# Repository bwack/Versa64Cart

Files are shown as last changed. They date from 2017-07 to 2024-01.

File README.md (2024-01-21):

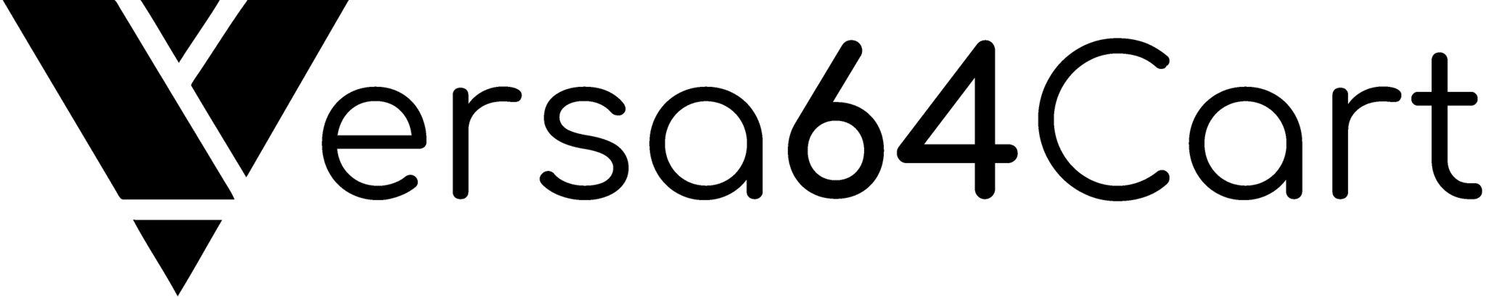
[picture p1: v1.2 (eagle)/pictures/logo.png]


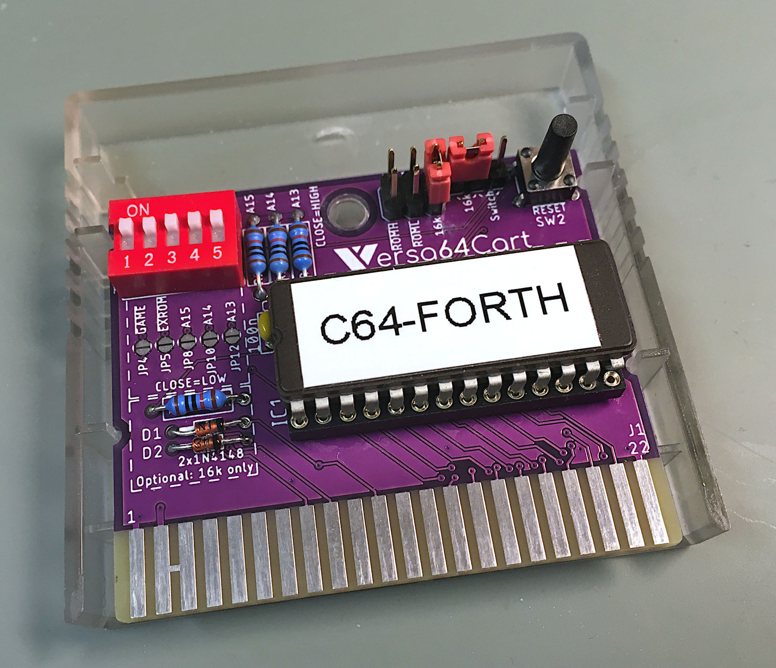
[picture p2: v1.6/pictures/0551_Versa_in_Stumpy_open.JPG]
boardimage


Versa64Cart is designed to be a modern easy-to-use cartridge development board for Commodore 64 and Commodore 128 hobbyists and hackers. The versatile design of the PCB allows for flexible implementation of various cartridge types. Whether it’s a simple cartridge backup of an 8k game or a switchable multi-program diagnostic cartridge, Versa64Cart has you covered.

Supported EPROMS are: 27C64 (8k), 27C128 (16k), 27C256 (32k), 27C512 (64k).
Please see the documentation for more information.

I have put the rev 1.1 in a separate folder in case someone wants to use the kicad files as a template.
Rev. 1.2 and onwards is designed by [Sven Petersen](https://github.com/svenpetersen1965 "Sven's github repository!") in eagle. It is a complete redrawn schematic and layout.

Sven has designed another cartridge called [Diag64cart](https://github.com/svenpetersen1965/Diag64cart) derived from this project.

# Quick Guide

## Obtaining binaries

Use the cartconv.exe tool from the VICE emulator to get information and to extract the binary from .CRT files. Copy it to the same folder as your .CRT files.

List the .CRT information:

```
C:\cartconv>cartconv -f deadtest.CRT
CRT Version: 1.0
Name: C64DEADTESTREV718220
Hardware ID: 0 (Generic Cartridge)
Mode: exrom: 1 game: 0 (ultimax)

offset  sig  type  bank start size  chunklen
$000040 CHIP ROM   #000 $e000 $2000 $2010

total banks: 1 size: $002000
```
The hardware ID must be 0. The size of the eprom shown here is 8k ($2000).

Convert the binary:

`cartconv -i mycartridge.crt -o mycartridge.bin`

## Combining binaries

The Versa64Cart supports EPROMS from 8k to 8x8k or 4x16k. The easiest way to combine is to use the copy command (in Windows):

`copy /b DeadTest.bin + jupiterl.bin + SomeGame.bin combined.bin`

Special care must be taken if mix 8k and 16k images. The 8k binaries must be allocated in pairs:

`copy /b first8k.bin + second8k.bin + some16k.bin combined.bin`

## Documentation

For more information Please see the [pdf file](v1.6/pdf/Versa64cart_v1_6.pdf) in this repository.

## Pictures

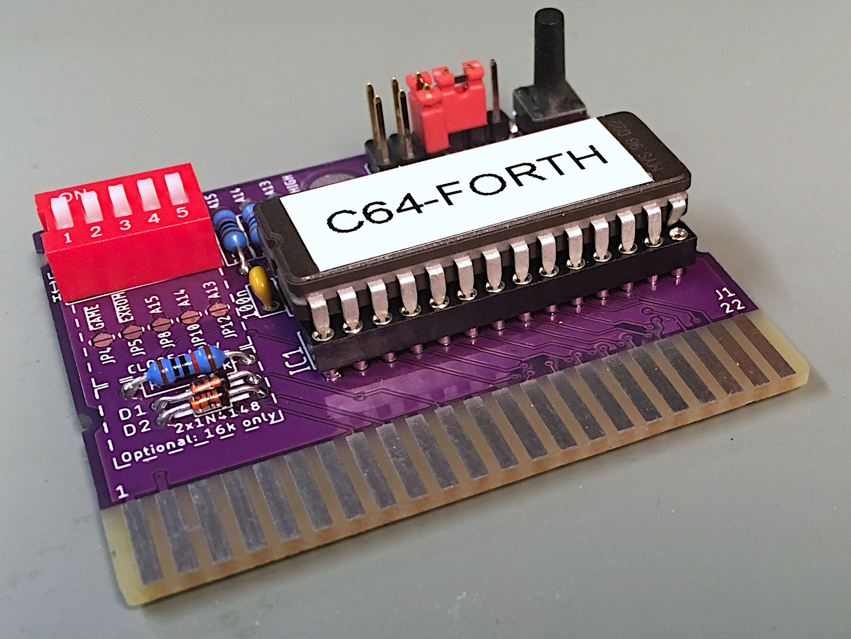
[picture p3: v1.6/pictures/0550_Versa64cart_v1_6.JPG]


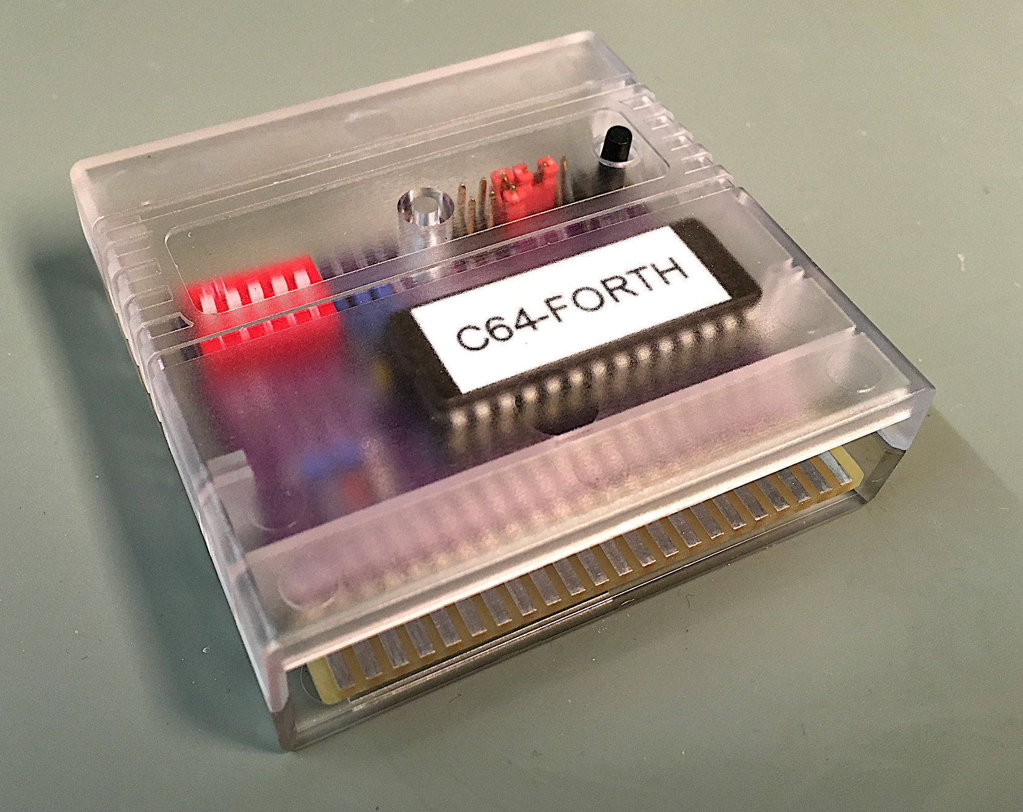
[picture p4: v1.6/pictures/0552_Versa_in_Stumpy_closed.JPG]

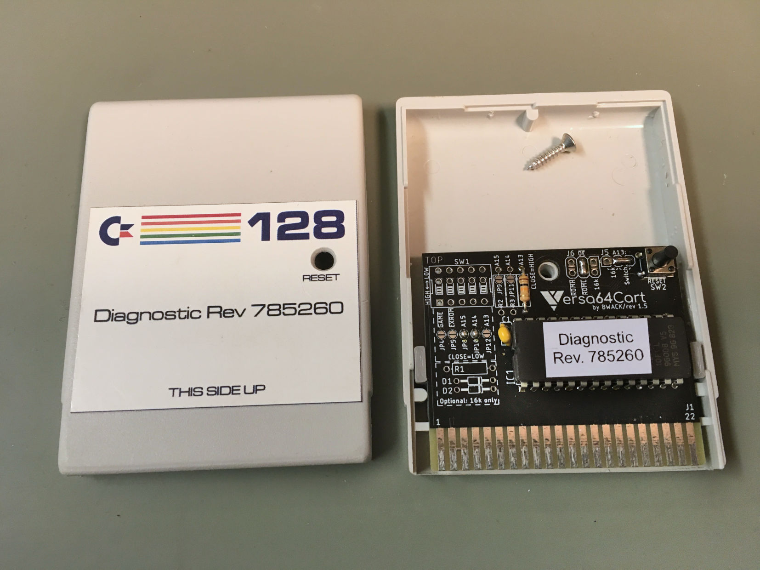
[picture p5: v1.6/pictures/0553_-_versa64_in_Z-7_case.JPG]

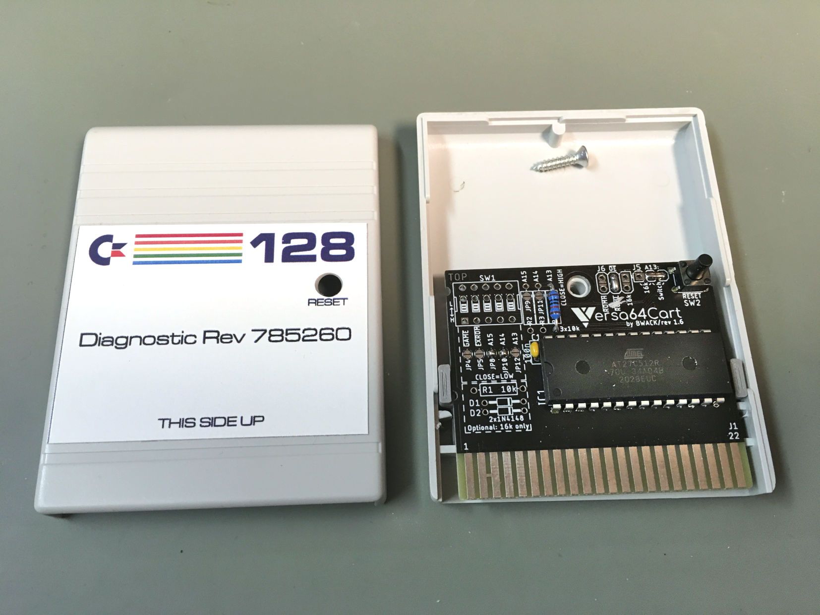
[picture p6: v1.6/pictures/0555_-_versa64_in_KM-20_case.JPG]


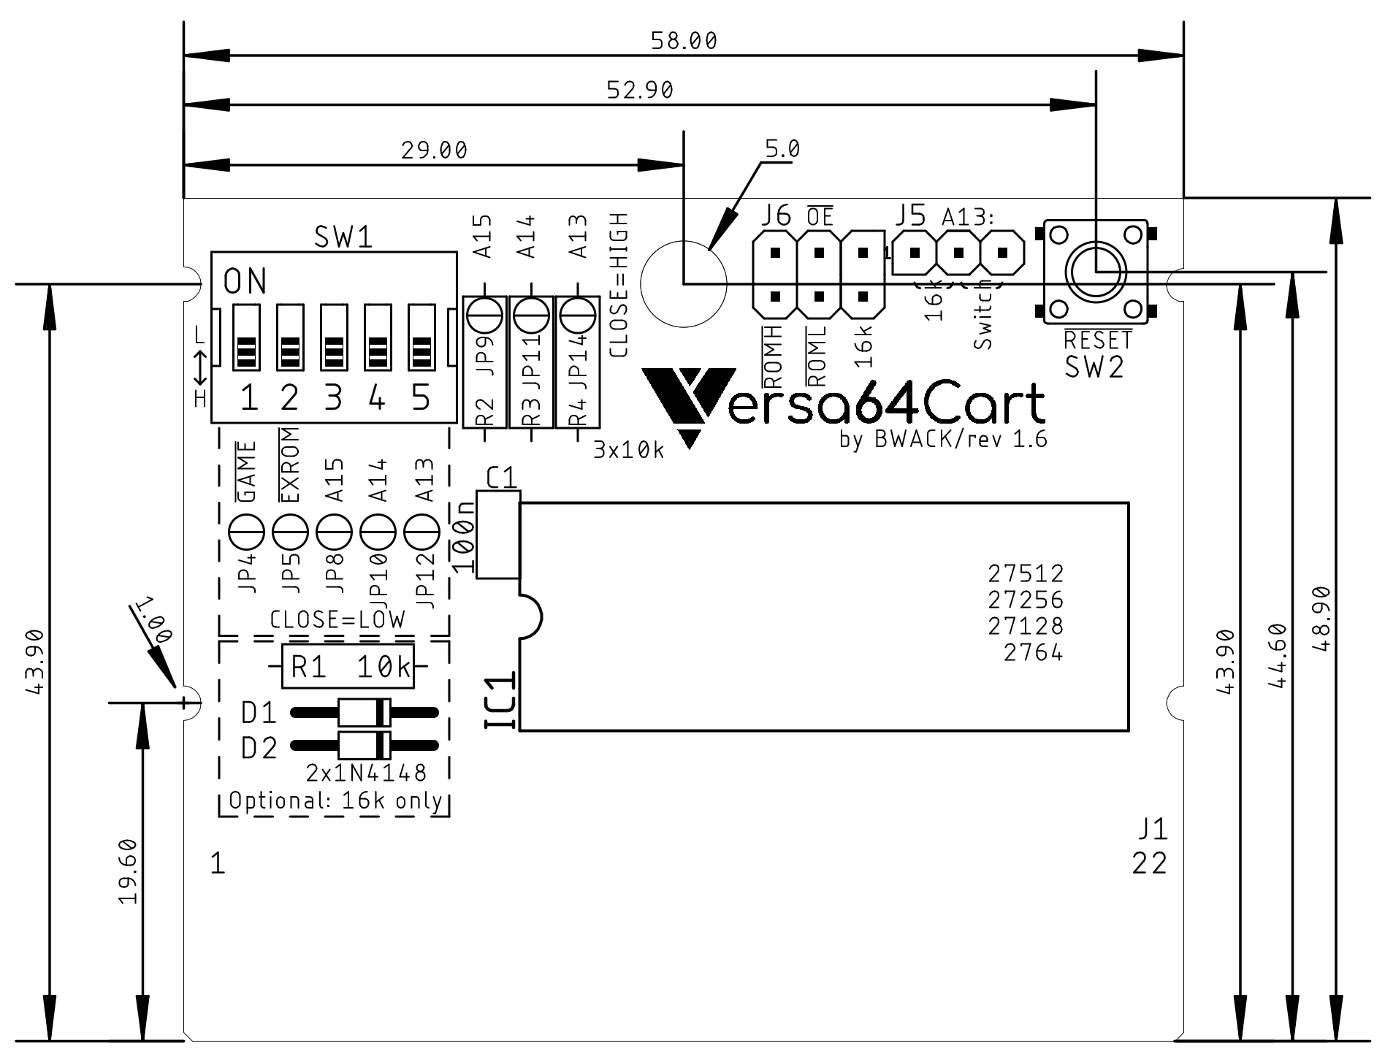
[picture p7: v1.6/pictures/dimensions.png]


# Changes
## 1.6
- Change: Notches added to fit the thefuturewas8bit.com stumpy cartridge case (not the button hole!)
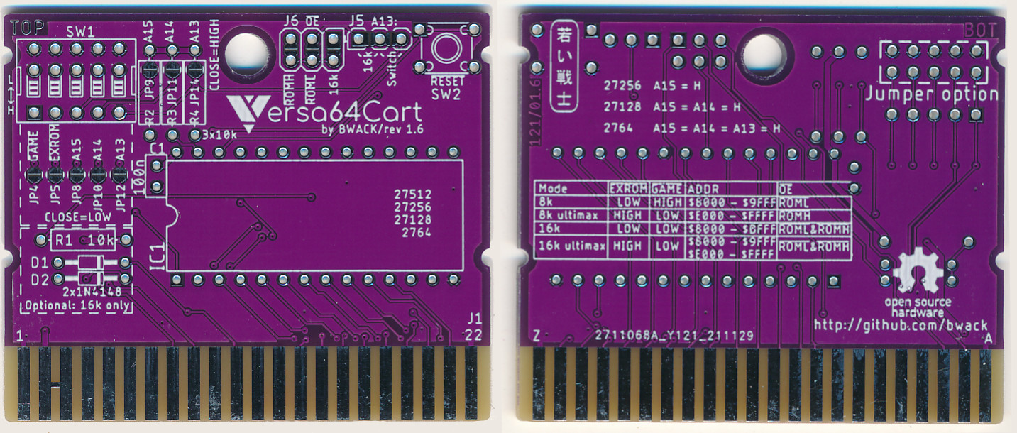
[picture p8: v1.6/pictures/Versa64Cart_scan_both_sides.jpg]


## 1.5
- Change: Combined footprint SW1, 5Way-DIP and 2x5 2.54mm pin header

## 1.4
- Change: card edge connector with pads like in v1.1

## 1.3
- Change: Cartridge enclosure support
  - Moved IC socket away from edge
  - Moved diode group away from edge
  - Bom: Use right angle pin headers. The straight ones are too tall.
  
## 1.2
- A reset button
- Jumpers accessible on outer edge.*
- Solder jumpers at the top layer
- New documentation
- Designed in Eagle
* Remember to turn off the computer before changing the jumpers.

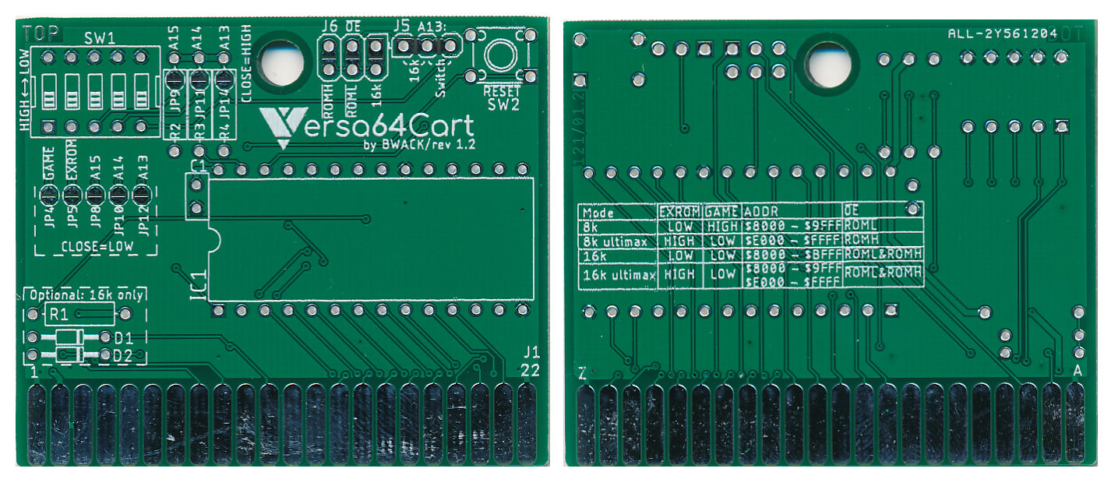
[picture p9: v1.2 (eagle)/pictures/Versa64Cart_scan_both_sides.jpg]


## 1.1 and 1.0

- Designed in KiCad based on simple64cart eagle files
- Support retro innovation cartridge enclosure (allthough pins too high)
- Moved IC sockets further from edge
- Added 16k game support
- Added dip switch and jumpers
- Added Documentation

# External websites

[Blog post, "Versa64Cart and C64 ROMs", by Gregory Nacu at c64os.com ](https://c64os.com/post/versa64cart)

# Versa64Cart on YouTube

https://www.youtube.com/results?search_query=Versa64Cart

# VersaZIF64
Check out VersaZIF64 if you are interested in the Versa64cart and with a ZIF socket.
https://github.com/bwack/VersaZIF64

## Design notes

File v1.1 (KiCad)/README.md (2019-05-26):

For gerbers click the relases tab!

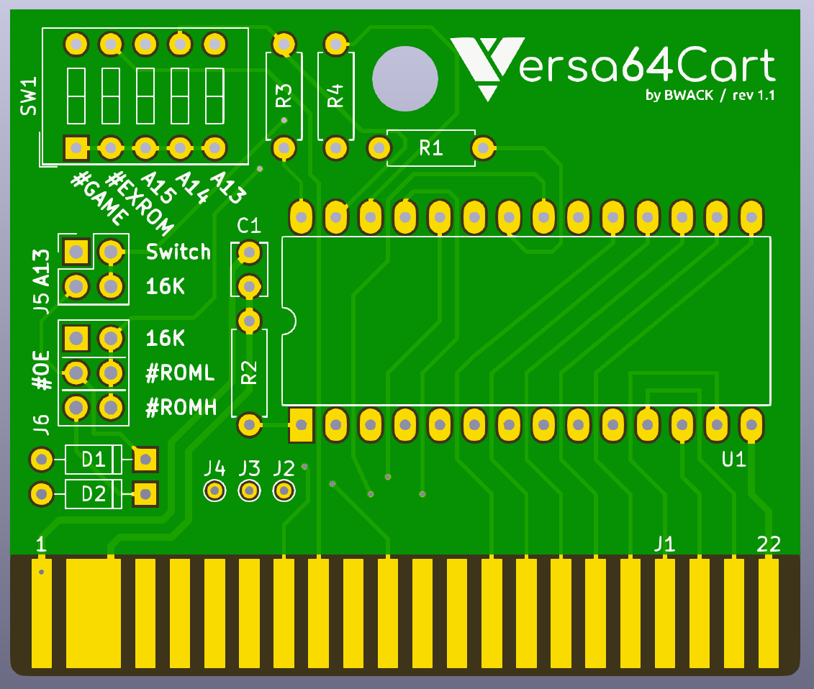
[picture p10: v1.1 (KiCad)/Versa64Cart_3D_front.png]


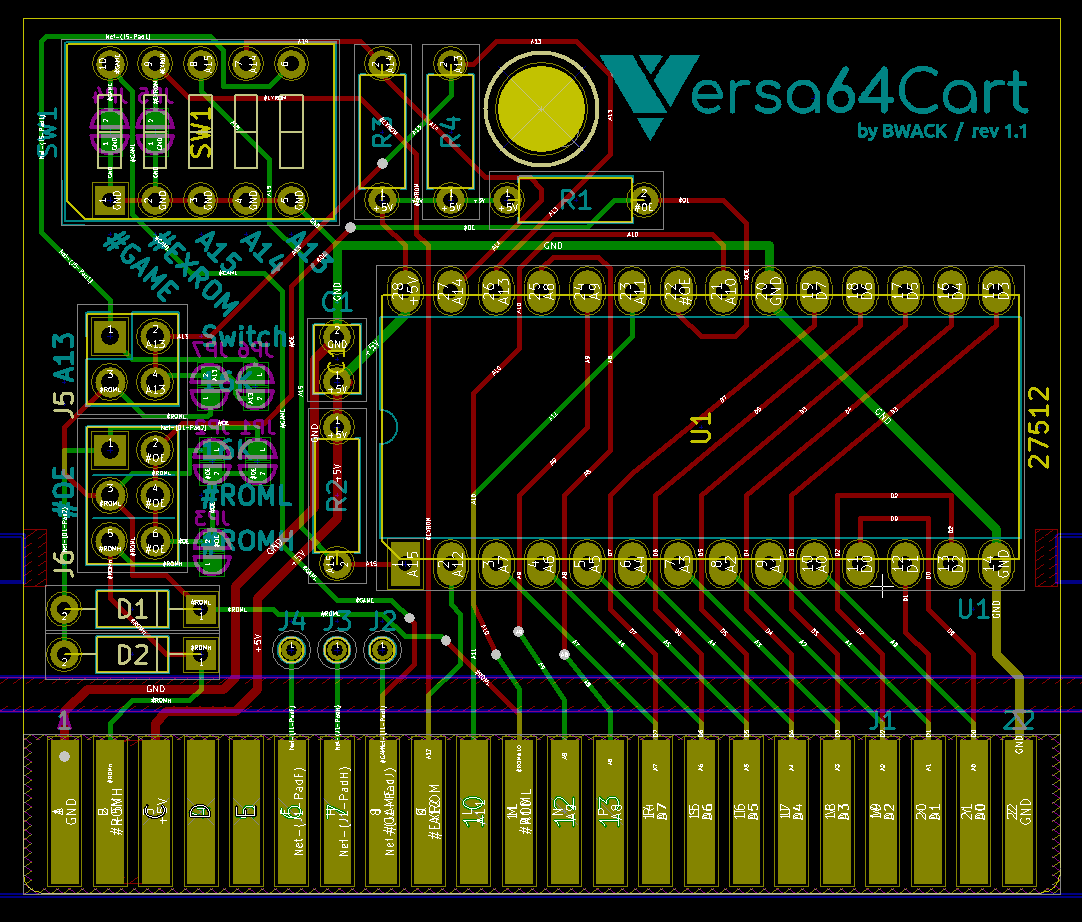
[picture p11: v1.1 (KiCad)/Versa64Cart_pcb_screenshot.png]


For more info see the docs

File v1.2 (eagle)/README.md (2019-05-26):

board

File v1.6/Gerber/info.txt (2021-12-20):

      
       Board: Versa64Cart
       Rev.:  1.6
  
       Files:
       ======
  
       All Gerber files are generated in extended gerber format (RS274X)
       *.TOP        : Film top copper
       *.BOT        :  -"- bottom copper
       *.STC        :  -"- top soldermask 
       *.STS        :  -"- bottom soldermask
       *.PLC        :  -"- silk screen top
       *.PLS        :  -"- silk screen bottom
       *.DK         : Drills plated Through (Excellon)
       *.NDK        : Drills not plated Through (Excellon)
       *.OUT        : Board outline

       Board Size:
       ===========
       Length     :   58.0 mm
       Width      :   48.9 mm
       Thickness  :   1.6 mm
       Material   :   FR 4
       Copper     :   35 um
       Surface    :   HASL
       
       Remarks:
       ========
       minimum drill: 0.35mm
       minimum width: 8 mil
       minimum distance: 6 mil

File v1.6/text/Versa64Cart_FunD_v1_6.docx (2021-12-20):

Versa64Cart v1.6

Functional Description

J1 are the contacts, that fit into the Commodore C64 expansion port. The pin numbering is identical to those of the C64. IC1 is the EPROM, which can be socketed or not. C1 is the blocking capacitor, that should help to keep the noise from the supply voltage out of the IC.

The configuration is achieved with the DIP-Switch SW1, jumper J5 and jumper J6. SW1-1 and SW1-2 set the signals and . These signalize the C64 the mode of the cartridge. The switches SW1-3 to SW3-5 are responsible for the (manual) bank select: The configure the three most sufficient address bit of the EPROM, since those are not asserted by the C64, which only addresses 8kB blocks. The Dip Switch can be replaced with a jumper (2x5).

For 16kB cartridges, a further address bit (A13) is required. Since this kind of cartridge uses both chip selects ( and ) the signal is used for this purpose. It will be low, while the lower 8kB are addressed and HIGH, while the upper 8kB are addressed.

The 16k cartridge configuration requires to combine and to one chip select signal. This function is provided by the wired AND circuit D1, D2 and R1. R1 is pulling the RH&RL signal HIGH. In case one of those signals is low, the RH&RL is driven LOW.

The required chip select signal can be selected with J6.

In 8k mode, the address bit A13 is set by the DIP-switch. Jumper J5 has to be set to the “Switch” position.

While and utilize the pull-up resistors inside the C64, the address signals A13 to A15 require Pull-Up resistors on the cartridge board (R2-R4). There are solder bridges on the component side if the Versa64Cart, that can be used alternatively to the DIP-Switch to pull each signal low. In case the Pull-Up resistors R2-R4 are not populated, additional solder bridges can be used to set A13 – A15 to a HIGH level (only those, that are set to a HIGH level). It is obvious, that closing the HIGH bridge and the LOW bridge of a signal at the same time produces a short circuit.

SW2 is the reset switch. A pull-up resistor on the C64 mainboard is utilized here.

Versa64Cart_FunD_v1_6.docx 19.12.2021 16:27 Drafted by Sven Petersen Page 2 of 2 Doc.-No.: 000-6-00-00

Versa64Cart_FunD_v1_6.docx 19.12.2021 16:27 Drafted by Sven Petersen Page 1 of 1 Doc.-No.: 121-6-02-01.6

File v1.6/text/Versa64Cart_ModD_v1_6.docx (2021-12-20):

Versa64Cart v1.6

Module Description

# 1. Introduction

The Versa64Cart is a generic EPROM cartridge for the Commodore C64 and C128. It can be configured as 8k, 16k, 8k ultimax or 16k ultimax cartridge. Further on, the most sufficient address bits of the EPROM can be set by a DIP-switch which offers a manual bank switching for multi game/multi ROM cart option.

The Versa64Cart is not suitable to run a Kernal or software, which require bank switching by that software (e.g. games > 16k).

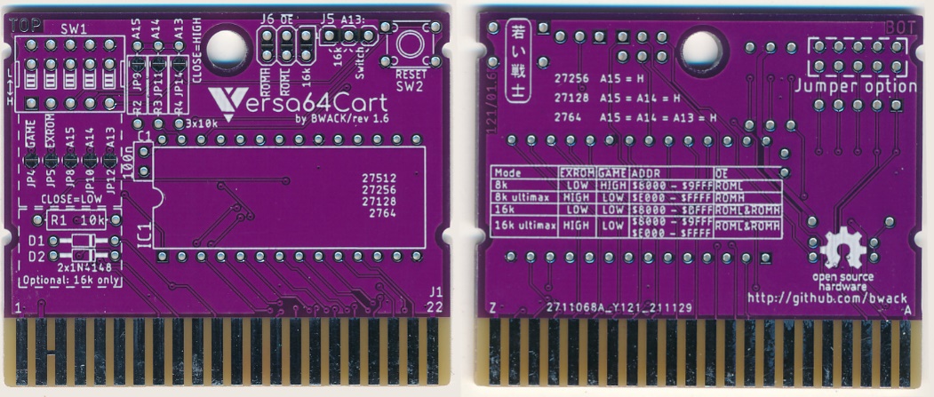
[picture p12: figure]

Figure 1: Both sides of the Versa64cart Rev. 1.6

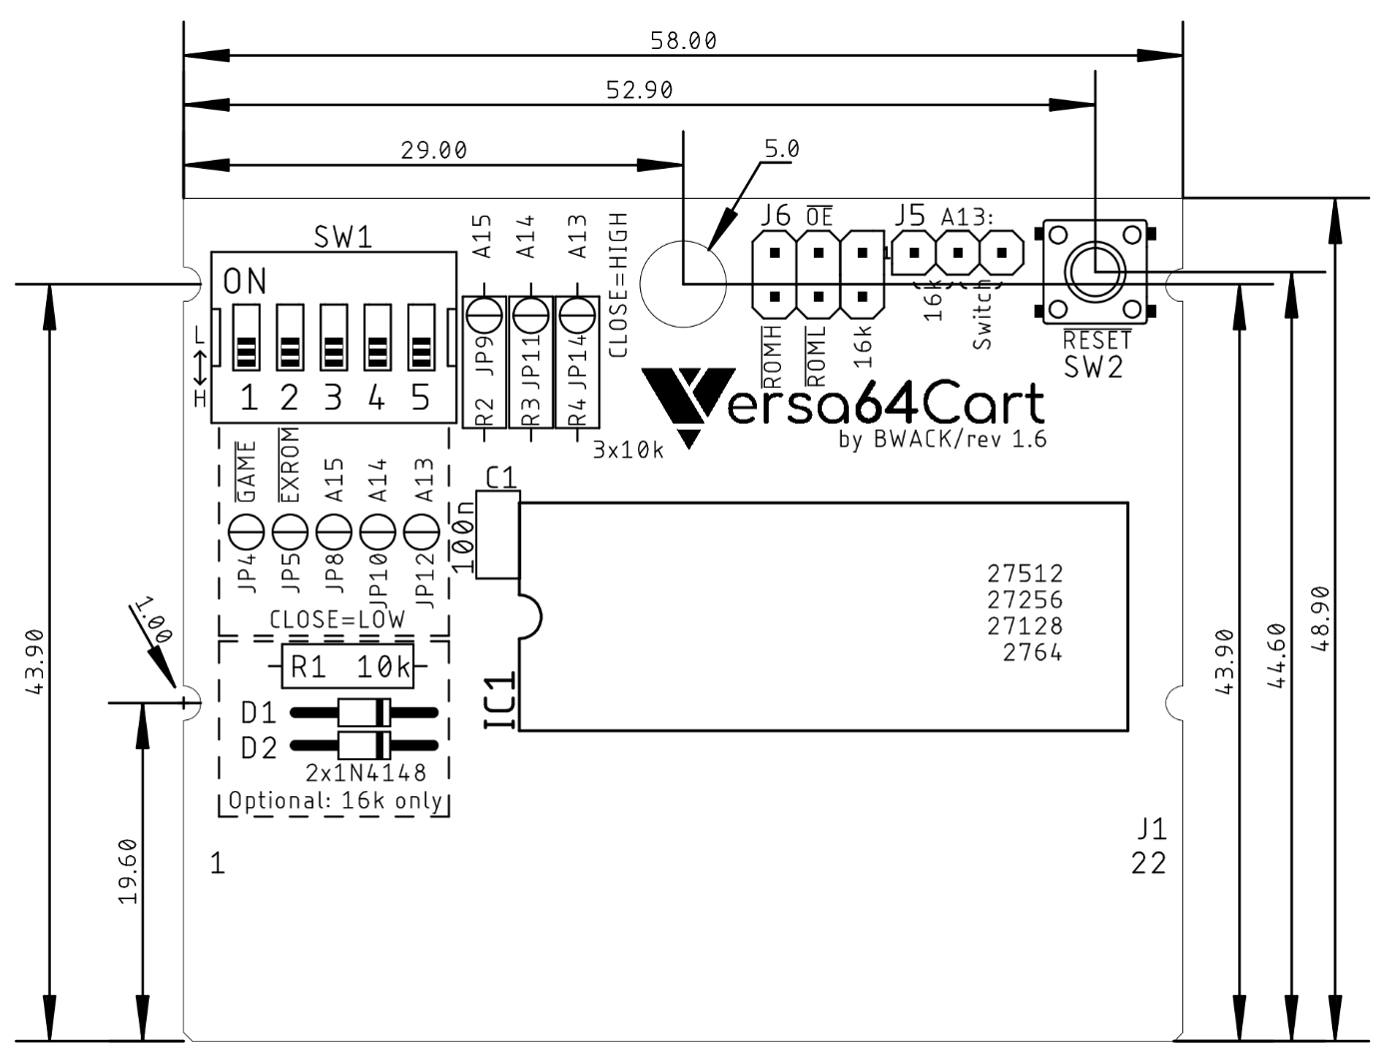
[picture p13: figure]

Figure 2: Versa64Cart - placement and dimensions

# 2. Configuration

## 2.1. Explanation

The extension cartridges signalize their configuration with two flags. Those are and . For addressing the EPROM, the C64 offers two chip-select signals for an 8kB address space, which are and . The chip-select signals are required to locate the EPROM content within the address space of the C64. It is possible to use either , or combining both to get a 16kB address space in total.

Mode | | | | Address space
8k | LOW | HIGH | | 0x8000 – 0x9FFF
8k ultimax | HIGH | LOW | | 0xE000 – 0xFFFF
16k | LOW | LOW | & = “16k” | 0x8000 – 0xBFFF
16k ultimax | HIGH | LOW | & = “16k” | 0x8000 – 0x9FFF + 0xE000 – 0xFFFF

Table 1: Cartridge configuration

In the “ultimax” modes, the Kernal ROM (0xE000 – 0xFFFF) is replaced by the content of the EPROM of the Versa64Cart. The Reset vector is located at 0xFFFC and 0xFFFD. This is a guidepost for the microprocessor, which shows where to start the execution after the processor was powered up (or received a RESET pulse). This way, the software in the EPROM will completely take control.

In EXROM mode, the C64 Kernal (the one on the mainboard) will check the memory locations 0x8004-0x8008 for the “cartridge signature” CBM80 (PETSCII 0xC3, 0xC2, 0xCD, 0x38, 0x30). If this sequence is found, the execution will follow the cartridge cold start vector located at the first two memory addresses of the EPROM (0x8000 and 0x8001 in the C64’s address space).

## 2.2. Jumper & DIP-Switch Settings

The DIP-Switch SW1 configures the cartridge mode and the three most sufficient address bit of the EPROM (the “bank switching”). Annotation: ON position connects the signal to ground (=LOW).

The jumper J6 () sets the chip select signal for the EPROM. It can be , or “16k”(this is a diode logic AND of and ).

The jumper J5 (A13) can be set to “Switch” or “16k”. “Switch” means, that A13 is set by the DIP-Switch, “16k” means, that A13 is controlled by the signal.

A 16k cartridge requires both jumpers (J5 and J6) set to “16k”.

For the required settings refer to Table 1.

## 2.3. Bank Switching

The EPROM offers more memory (27C512 = 64kB), than it is required for a generic 8k or 16k cartridge. On account of this an EPROM can keep the content of several cartridges. The DIP-Switch SW1 (3, 4, 5 = A15, A14 and A13) selects, which of these cartridges is selected. In 16k mode, the setting of A13 is ignored.

The DIP-Switch can be replaced with a jumper.

DIP-Switch | | | Address Bits | | | EPROM Address (Offset)
3 | 4 | 5 | A15 | A14 | A13
ON | ON | ON | L | L | L | 0x0000 – 0x1FFF
ON | ON | OFF | L | L | H | 0x2000 – 0x3FFF
ON | OFF | ON | L | H | L | 0x4000 – 0x5FFF
ON | OFF | OFF | L | H | H | 0x6000 – 0x7FFF
OFF | ON | ON | H | L | L | 0x8000 – 0x9FFF
OFF | ON | OFF | H | L | H | 0xA000 – 0xBFFF
OFF | OFF | ON | H | H | L | 0xC000 – 0xDFFF
OFF | OFF | OFF | H | H | H | 0xE000 – 0xFFFF

Table 2: 8k cartridges memory banks

DIP-Switch | | | Address Bits | | | EPROM Address (Offset)
3 | 4 | 5 | A15 | A14 | A13
ON | ON | X | L | L | X | 0x0000 – 0x3FFF
ON | OFF | X | L | H | X | 0x4000 – 0x7FFF
OFF | ON | X | H | L | X | 0x8000 – 0xBFFF
OFF | OFF | X | H | H | X | 0xC000 – 0xFFFF

Table 3: 16k cartridges memory banks

The C64 address must not be confused with the EPROM Address offset.

## 2.4. Solder Bridges

Instead of setting jumpers and the DIP-Switch, solder bridges can be utilized to configure the Versa64Cart. This is an option, in case the configuration of the Versa64Cart is not prone to be changed. Solder bridges are used to “hard wire” the configuration.

Signal | HIGH | LOW
| JP4 = open | JP4 = closed
| JP5 = open | JP5 = closed
A15 | JP8 = open, (JP9 = closed) | JP8 = closed, (JP9 = open)
A14 | JP10 = open, (JP11 = closed) | JP10 = closed, (JP11 = open)
A13 | JP12 = open, (JP14 = closed) | JP12 = closed, (JP14 = open)

Table 4: Configuration with solder bridges

The jumpers in ( ) are only required, in case the pull-up resistors R2, R3 and R4 are not populated. Never (!!!!) close both jumpers of one address signal. It cannot be LOW and HIGH at the same time, this will produce a SHORT CIRCUIT!!!!

The footprints of the jumpers J5 and J6 are designed to be solder bridged, when not populated.

# 3. Assembly of the Versa64Cart

The Versa64Cart can work with a minimum of components when being configured with solder bridges. Just the EPROM and a 100nF capacitor is required.

- The reset switch is nice to have, but it is just an option.
- The DIP-switch can be replaced by configuring the solder bridges JP4, 5, 8, 10 and 12.
- The pull-up resistors (R2-4) can be omitted and JP9, 11, 14 can be utilized to set a HIGH level on A15 … A13 (BE CAREFUL, see warning above!). If you are not sure, keep the pull up resistors.
- J5 and J6 can be hard wired with solder bridges.
- R1, D1 and D2 are only required in 16k modes.
- The EPROM can be soldered, a socket is not necessary

Soldering the EPROM can be required if a shallow cartridge case is used. A socket might add too much height. In this case, it is advised to test the EPROM with a Versa64Cart with a socket before.

# 4. Retrieving the binary and the settings from a CRT file

## 4.1. VICE cartconv

The CRT file format is created to emulate cartridges with VICE or devices like the Ultimate II+ etc. It should not be programmed into an EPROM; this will not work.

Instead, the binary has to be retrieved from the CRT file. The binary is a file that can be used for programming EPROMs. Also, it is possible to find out the required settings for and .

The utility that is used here is CARTCONV, which is a command line too that comes with VICE (C64 emulator). For the examples, CARTCONV and the cartridge files are copied to the same directory. To start, enter cmd into the search box on the task bar of Windows 10.

First the CRT information is required. Enter the following command

cartconv -f mycartridge.crt

mycartridge.crt stands for the crt file, that you want to convert.

The second step is to generate a *.bin file from the *.crt. The *.bin file can be used to program EPROMs.

cartconv -i mycartridge.crt -o mycartridge.bin

## 4.2. Example I

C:\cartconv>cartconv -f deadtest.CRT

CRT Version: 1.0

Name: C64DEADTESTREV718220

Hardware ID: 0 (Generic Cartridge)

Mode: exrom: 1 game: 0 (ultimax)

offset sig type bank start size chunklen

$000040 CHIP ROM #000 $e000 $2000 $2010

total banks: 1 size: $002000

The important information is colored red in the above example.

First of all, it has to be a generic cartridge (Hardware ID 0). Many (game or special) cartridges have additional hardware build it, that is required for proper operation. That might be one of manifold automatic bank switching circuits, a freezer circuit like in the Final Cartridge etc.

Next, has to be 1 (HIGH) and has to be 0 (LOW) Þ DIP Switch 1=ON, 2=OFF. The ultimax mode is mentioned here, too. The start address is $e000 (0xE000). Referring to Table 1, J6 has to be set to . The size is $2000 (which is hexadecimal for 8k). Hence jumper J5 is set to “switch”. It is assumed, that the binary is programmed to the first 8k of the EPROM, so the address lines A15, A14 and A13 are L, L, L Þ the switches 3-5 are ON.

Item | cartconv | Setting
| 0 (= LOW) | SW1-1 = ON
| 1 (= HIGH) | SW1-2 = OFF
size | $2000 (=8k cartridge) | A13 (J5) = “Switch”
start | $E000 | (J6) =
EPROM offset | $2000 | A15…13 = LLL Þ SW1-3 = ON SW1-4 = ON SW1-5 = ON

Now the deadtest.bin file can be generated:

C:\cartconv>cartconv -i deadtest.CRT -o deadtest.bin

Input file : deadtest.CRT

Output file : deadtest.bin

Conversion from Generic Cartridge .crt to binary format successful.

## 4.3. Example II

C:\cartconv>cartconv -f diag04.crt

CRT Version: 1.0

Name: 586220PLUS_0.4

Hardware ID: 0 (Generic Cartridge)

Mode: exrom: 0 game: 1 (8k Game)

offset sig type bank start size chunklen

$000040 CHIP ROM #000 $8000 $2000 $2010

total banks: 1 size: $002000

Here, the Hardware ID is 0 (Generic Cartridge) again. The Versa64Cart is suitable for running the software. Now, it is assumed, that the first 8k are already in use and the binary should be programmed to the second 8k slot of the EPROM.

Item | cartconv | Setting
| 1 (= HIGH) | SW1-1 = OFF
| 0 (= LOW) | SW1-2 = ON
size | $2000 (=8k cartridge) | A13 (J5) = “Switch”
start | $8000 | (J6) =
EPROM offset | $2000 | A15…13 = LLH Þ SW1-3 = ON SW1-4 = ON SW1-5 = OFF

The binary conversion is exactly the same like in Example I.

## 4.4. Example III

C:\cartconv>cartconv -f neutron.crt

CRT Version: 1.0

Name: NEUTRON

Hardware ID: 0 (Generic Cartridge)

Mode: exrom: 0 game: 0 (16k Game)

offset sig type bank start size chunklen

$000040 CHIP ROM #000 $8000 $4000 $4010

total banks: 1 size: $004000

Again, it is assumed, the binaries should be programmed to the first 16k of the EPROM.

Item | cartconv | Setting
| 0 (= LOW) | SW1-1 = ON
| 0 (= LOW) | SW1-2 = ON
size | $4000 (=16k cartridge) | A13 (J5) = “16k” (J6) = “16k”
start | $8000 | Not relevant in 16k mode
EPROM offset | $0000 | A15…13 = LLL Þ SW1-3 = ON SW1-4 = ON SW1-5 = ON

The binary conversion is exactly the same like in Example I.

## 4.5. Example IV

C:\cartconv>cartconv -f batman.crt

CRT Version: 1.0

Name: batman

Hardware ID: 5 (Ocean)

Mode: exrom: 0 game: 1 (8k Game)

Warning: game in crt image set incorrectly.

offset sig type bank start size chunklen

$000040 CHIP ROM #000 $8000 $2000 $2010

$002050 CHIP ROM #001 $8000 $2000 $2010

[…]

$01e130 CHIP ROM #015 $8000 $2000 $2010

total banks: 16 size: $020000

Here, the hardware ID is not 0 (generic). The Versa64Cart is not suitable for this software. The size is $20000, which is 128kB, more than what fits into the memory space of the C64. This kind of software requires a cartridge with a certain automatic bank switching circuit, in this case the Ocean cartridge type and a 27C010 (128kx8bit) EPROM is required.

# 5. EPROMs

Four different types/sizes of EPROMs can be used with the Versa64Cart, not all settings make sense with them. Their pin out is shown in Table 5.

The effect of the settings and the recommended configurations are shown in Table 6.

27C64
| 27C128
| | 27C256
| | | 27C512
| | | | SOCKET
Vpp | Vpp | Vpp | A15 | 1 | A15 | VCC | 28 | VCC | VCC | VCC | VCC
A12 | A12 | A12 | A12 | 2 | A12 | A14 | 27 | A14 | A14 | /PGM | /PGM
A7 | A7 | A7 | A7 | 3 | A7 | A13 | 26 | A13 | A13 | A13 | n.c.
A6 | A6 | A6 | A6 | 4 | A6 | A8 | 25 | A8 | A8 | A8 | A8
A5 | A5 | A5 | A5 | 5 | A5 | A9 | 24 | A9 | A9 | A9 | A9
A4 | A4 | A4 | A4 | 6 | A4 | A11 | 23 | A11 | A11 | A11 | A11
A3 | A3 | A3 | A3 | 7 | A3 | /OE | 22 | /G/Vpp | /G | /G | /G
A2 | A2 | A2 | A2 | 8 | A2 | A10 | 21 | A10 | A10 | A10 | A10
A1 | A1 | A1 | A1 | 9 | A1 | GND | 20 | /E | /E | /E | /E
A0 | A0 | A0 | A0 | 10 | A0 | D7 | 19 | D7 | D7 | D7 | D7
D0 | D0 | D0 | D0 | 11 | D0 | D6 | 18 | D6 | D6 | D6 | D6
D1 | D1 | D1 | D1 | 12 | D1 | D5 | 17 | D5 | D5 | D5 | D5
D2 | D2 | D2 | D2 | 13 | D2 | D4 | 16 | D4 | D4 | D4 | D4
GND | GND | GND | GND | 14 | GND | D3 | 15 | D3 | D3 | D3 | D3

Table 5: EPROM pin compatibility

EPROM | Size | A15 | A14 | A13 | 16k
27C512 | 64kx8 | yes | yes | yes | yes
27C256 | 32kx8 | HIGH | yes | yes | yes
27C128 | 16kx8 | HIGH | HIGH | yes | yes
27C64 | 8kx8 | HIGH | HIGH | HIGH | no

Table 6: Settings per EPROM type

In case Vpp is located at a dedicated pin (pin 1), A15 has no effect anymore. A HIGH level is recommended (switch is off) . The /PGM Pin should be set HIGH. The n.c. (not connected) pin should be HIGH (with pull-up) or open. For an 8k EPROM, the 16k setting makes no sense.

# 6. Using parallel EEPROMs

There are parallel EPROMs, which fit into the EPROM sockets. They do not require erasing with a UV eraser, like EPROMs, but the price is higher.

Since they can be written, which is controlled by the signal, but the Super Expander II cartridge is lacking of this functionality, this signal has to be HIGH (inactive). The 28C256 has the A14 signal connected to Pin 1, which is A15 of the EEPROM socket. This is no problem, but it has to be kept in mind, that the jumper for A15 has effect on the bank select A14 of the EPROM.

28C64
| 28C256
| | SOCKET
n.c. | A14 | 1 | A15 | VCC | 28 | VCC | VCC
A12 | A12 | 2 | A12 | A14 | 27 | /WE | /WE
A7 | A7 | 3 | A7 | A13 | 26 | A13 | n.c
A6 | A6 | 4 | A6 | A8 | 25 | A8 | A8
A5 | A5 | 5 | A5 | A9 | 24 | A9 | A9
A4 | A4 | 6 | A4 | A11 | 23 | A11 | A11
A3 | A3 | 7 | A3 | /OE | 22 | /G/Vpp | /OE
A2 | A2 | 8 | A2 | A10 | 21 | A10 | A10
A1 | A1 | 9 | A1 | GND | 20 | /E | /CE
A0 | A0 | 10 | A0 | D7 | 19 | D7 | D7
D0 | D0 | 11 | D0 | D6 | 18 | D6 | D6
D1 | D1 | 12 | D1 | D5 | 17 | D5 | D5
D2 | D2 | 13 | D2 | D4 | 16 | D4 | D4
GND | GND | 14 | GND | D3 | 15 | D3 | D3

Table 7: EEPROM pin compatibility

EEPROM | Size | A15 | A14 | A13
28C256 | 32kx8 | =A14 | OPEN | yes
28C64 | 8kx8 | OPEN | OPEN | OPEN

Table 8: Settings per EEPROM type

# 7. Startup and Trouble shooting

Before you insert the Versa64Cart into the expansion port of the C64, you should make sure, that there are no fatal failures on it. In the worst case, it will produce a short circuit.

- Check the solder joints on the solder side
- Check the orientation of the socket. The notch is at the side, where the capacitor is
- In case you have used the solder bridges to configure the address, check according to the warning in chapter 2.4 or measure the resistance between pin 1 and 2 (that is GND and +5V) of the edge connector (without an EPROM inserted). It must not be less than about 3kΩ.
- After inserting the EPROM, check if the notch is at the same side like the notch of the socket. Check all pins are properly seated in the socket and not bent inwards or outwards.

After all these points are correct, nothing really bad can happen to your C64 anymore. If you get a black screen or a normal startup display with less than 38911 Basic Bytes free, you might have a configuration problem.

- Did you program the EPROM with a proper *.bin and not with the *.crt file? CRT files are not suitable to program an EPROM. Refer to chapter 4.
- Did you set the configuration bits correctly? ON means LOW
- Did you select the required (J6)?
- Did you jumper A13 (J5) as required?
- In case it is a 16k cartridge: Are R1, D1 and D2 placed?

# 8. Suitable Cases

There are several case options:

1. The Versa64case (https://github.com/svenpetersen1965/Versa64Case) is a 3D-Printed case with a lid. It fits the Versa64cart with a socketed EPROM
2. The Maszczyk KM-20 (https://www.tme.eu/de/en/details/abs-20b/multipurpose-enclosures/maszczyk/km-20b-gy/) case (e.g. available from tme.eu) – no EPROM socket possible
3. The Kradex Z-7 (https://www.tme.eu/de/en/details/z-7/enclosures-with-panel/kradex/z7/) case (e.g. available from tme.eu) – no EPROM socket possible
4. Stumpy cartridge case from https://www.thefuturewas8bit.com/ EPROM on a low profile socket possible.

For the KM-20 and the Z-7, an 3D printed adapter (https://github.com/svenpetersen1965/Versa64cart-adapter_km20-z7) helps to keep the Versa64cart straight. It is not a requirement, but an elegant way to solve a (minor) problem. The reset button should have a height of 9.5mm for this case.

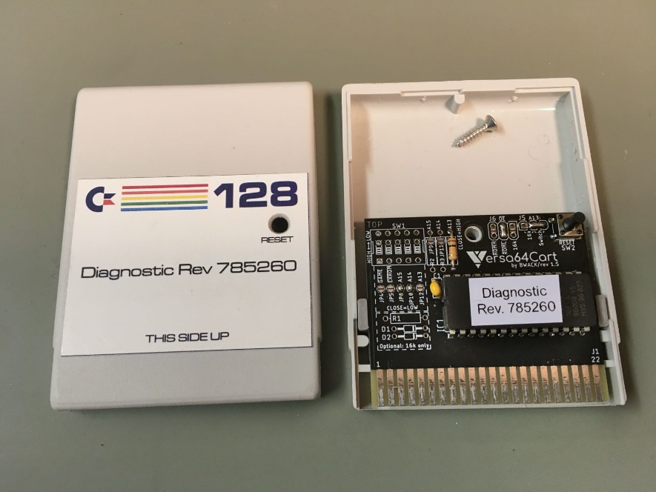
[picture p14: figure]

Figure 3: The Versa64cart in a Kradex Z-7 case

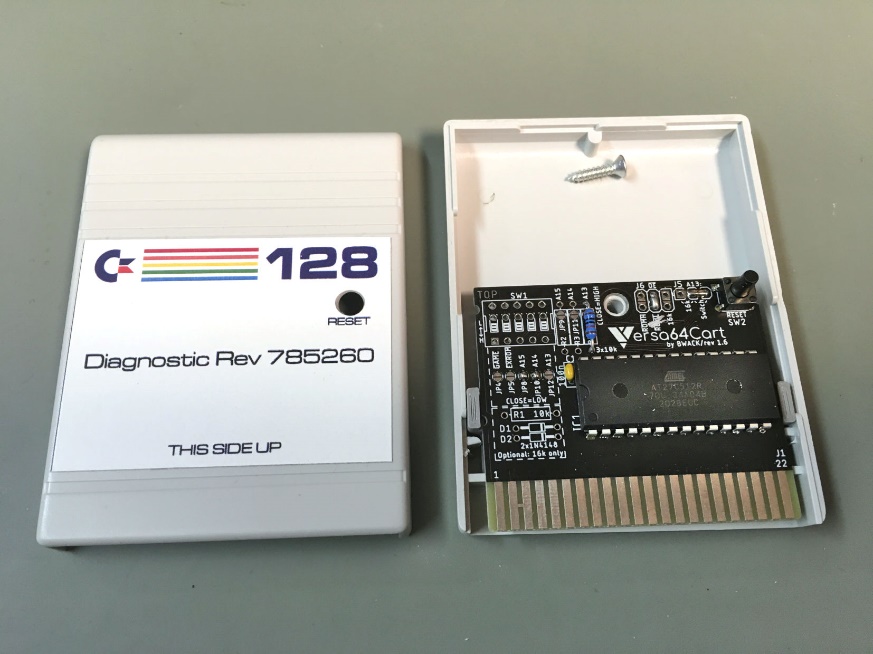
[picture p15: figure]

Figure 4: The Versa64cart in a Maszczyk KM-20 case

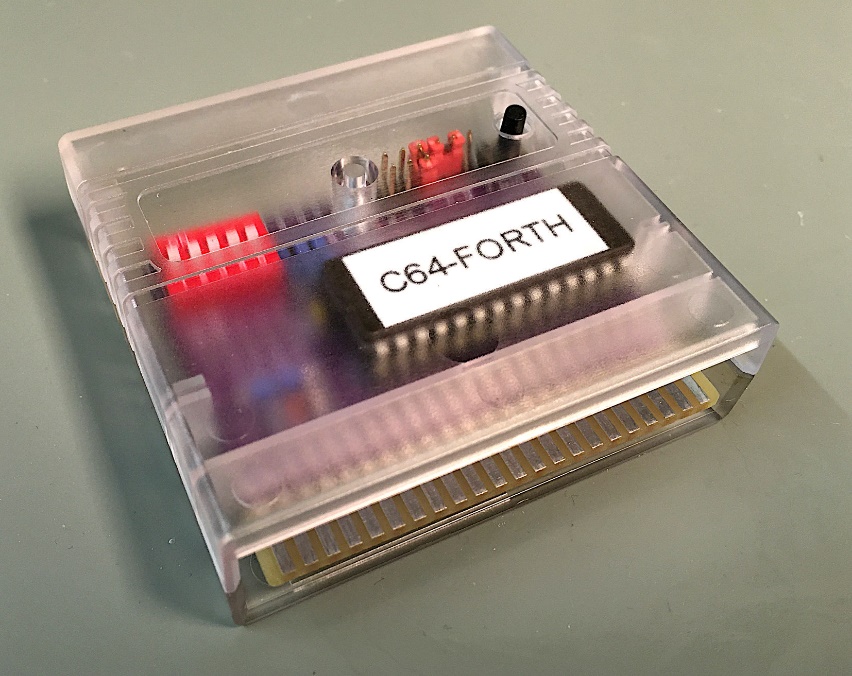
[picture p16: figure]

Figure 5: The Versa64cart (Rev. 1.6) in a Stumpy cartridge case

For the Stumpy cartridge case, the Reset button should have a height of 11mm.

# 9. Revision History

## 9.1. Rev. 1.1 Þ Rev. 1.2

- Schematic and layout were redrawn in Eagle (v 9.2)
- All solder bridges (jumpers) are located on the component side now (the footprint of the jumpers includes the solder bridge option)
- A13…A15 can be configured by solder bridges now
- No test points for A13…A15 anymore
- The jumpers are moved to the outer edge for easier access
- J5 for the configuration of A13 is a 3-pin jumper now
- A reset switch is added
- A configuration table is added on the solder side

## 9.2. Rev. 1.2 Þ Rev. 1.3

Some issues with cartridge cases were fixed.

- The diodes D1 & D2 and R1 were moved north by 4.93mm
- D1&D2 moved east by 4.6mm, R1 by 2.54mm
- IC1&C1 moved west by 1.59mm

## 9.3. Rev. 1.3 Þ Rev. 1.4

- The width of the contact pads of the expansion port was reduced to 1.5mm and the whole area is free of solder stop mask.

## 9.4. Rev. 1.4 Þ Rev. 1.5

- The DIP-Switch SW1 can be replaced with a jumper

## 9.5. Rev. 1.5 Þ Rev. 1.6

- Notches added to fit the thefuturewas8bit.com stumpy cartridge case (not the button hole!)

Versa64Cart_ModD_v1_6.docx 19.12.2021 16:33 Drafted by Sven Petersen Page 2 of 2 Doc.-No.: 121-6-01-01.6

Versa64Cart_ModD_v1_6.docx 19.12.2021 16:33 Drafted by Sven Petersen Page 1 of 1 Doc.-No.: 121-6-01-01.5

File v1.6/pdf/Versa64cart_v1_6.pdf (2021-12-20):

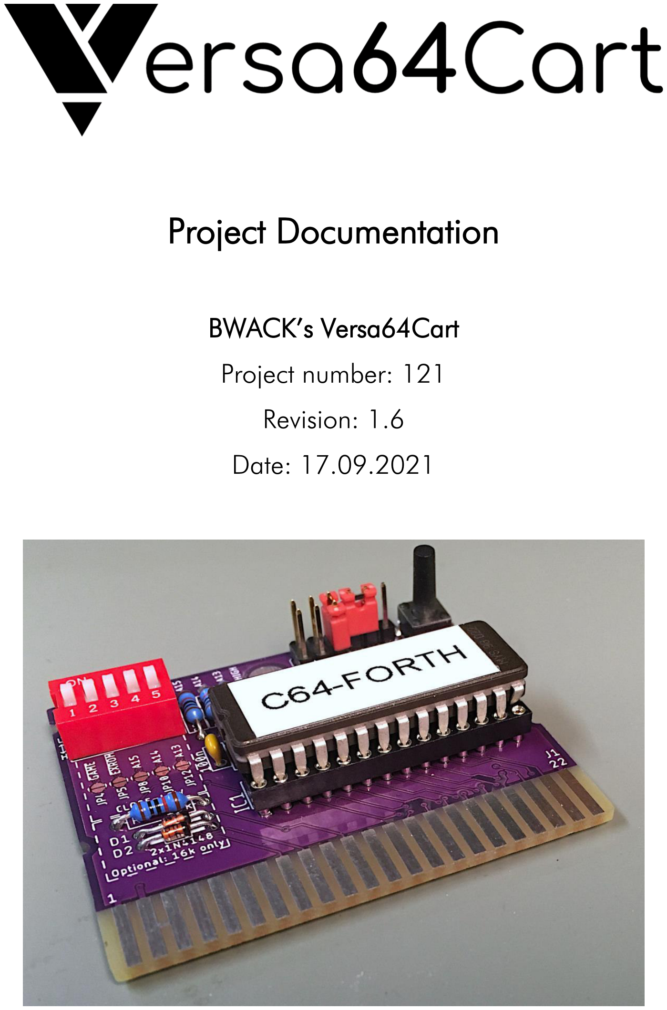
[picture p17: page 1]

# Project Documentation

# BWACK’s Versa64Cart

## Project number: 121

## Revision: 1.6

## Date: 17.09.2021

Versa64Cart_ModD_v1_6.docx | | 19.12.2021 16:33
Drafted by Sven Petersen | Page 1 of 11 | Doc.-No.: 121-6-01-01.6

# Versa64Cart v1.6

# Module Description

Content

# 1. Introduction

The Versa64Cart is a generic EPROM cartridge for the Commodore C64 and C128. It can be configured as 8k, 16k, 8k ultimax or 16k ultimax cartridge. Further on, the most sufficient address bits of the EPROM can be set by a DIP-switch which offers a manual bank switching for multi game/multi ROM cart option.

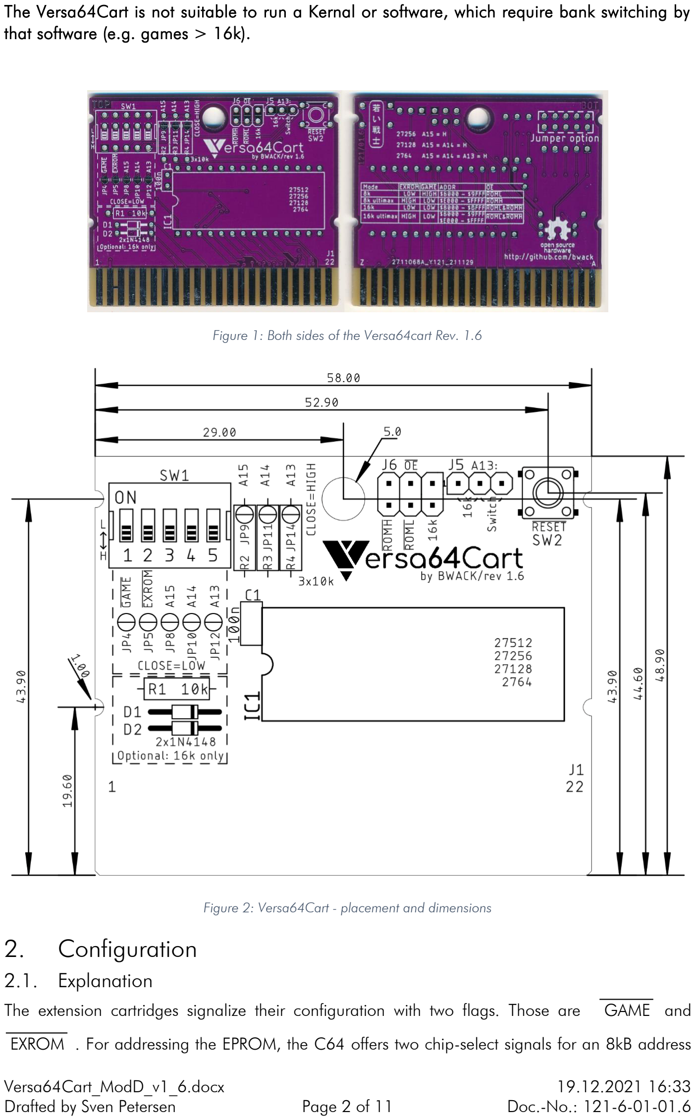
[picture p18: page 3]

Drafted by Sven Petersen | Page 2 of 11 | Doc.-No.: 121-6-01-01.6

The Versa64Cart is not suitable to run a Kernal or software, which require bank switching by that software (e.g. games > 16k).

Figure 1: Both sides of the Versa64cart Rev. 1.6

Figure 2: Versa64Cart - placement and dimensions

## 2. Configuration

### 2.1. Explanation

The extension cartridges signalize their configuration with two flags. Those are GAME and

EXROM . For addressing the EPROM, the C64 offers two chip-select signals for an 8kB address

Drafted by Sven Petersen | Page 3 of 11 | Doc.-No.: 121-6-01-01.6

space, which are ROML and ROMH . The chip-select signals are required to locate the EPROM

content within the address space of the C64. It is possible to use either ROML , ROMH or combining both to get a 16kB address space in total.

Mode | EXROM | GAME | OE

Address space

8k | LOW | HIGH | ROML | 0x8000 – 0x9FFF
8k ultimax | HIGH | LOW | ROMH | 0xE000 – 0xFFFF
16k | LOW | LOW | ROML & ROMH = “16k” | 0x8000 – 0xBFFF
16k ultimax | HIGH | LOW | ROML & ROMH = “16k” | 0x8000 – 0x9FFF + 0xE000 – 0xFFFF

Table 1: Cartridge configuration
In the “ultimax” modes, the Kernal ROM (0xE000 – 0xFFFF) is replaced by the content of the EPROM of the Versa64Cart. The Reset vector is located at 0xFFFC and 0xFFFD. This is a guidepost for the microprocessor, which shows where to start the execution after the processor was powered up (or received a RESET pulse). This way, the software in the EPROM will completely take control.

In EXROM mode, the C64 Kernal (the one on the mainboard) will check the memory locations
0x8004-0x8008 for the “cartridge signature” CBM80 (PETSCII 0xC3, 0xC2, 0xCD, 0x38, 0x30). If
this sequence is found, the execution will follow the cartridge cold start vector located at the first two
memory addresses of the EPROM (0x8000 and 0x8001 in the C64’s address space).

### 2.2. Jumper & DIP-Switch Settings

The DIP-Switch SW1 configures the cartridge mode and the three most sufficient address bit of the EPROM (the “bank switching”). Annotation: ON position connects the signal to ground (=LOW).

The jumper J6 ( OE ) sets the chip select signal for the EPROM. It can be ROML , ROMH or
“16k”(this is a diode logic AND of ROML and ROMH ).

The jumper J5 (A13) can be set to “Switch” or “16k”. “Switch” means, that A13 is set by the DIP-
Switch, “16k” means, that A13 is controlled by the ROML signal.

A 16k cartridge requires both jumpers (J5 and J6) set to “16k”.

For the required settings refer to Table 1.

### 2.3. Bank Switching

The EPROM offers more memory (27C512 = 64kB), than it is required for a generic 8k or 16k cartridge. On account of this an EPROM can keep the content of several cartridges. The DIP-Switch SW1 (3, 4, 5 = A15, A14 and A13) selects, which of these cartridges is selected. In 16k mode, the setting of A13 is ignored.

The DIP-Switch can be replaced with a jumper.

Drafted by Sven Petersen | Page 4 of 11 | Doc.-No.: 121-6-01-01.6
DIP-Switch | Address Bits | EPROM Address
3 | 4 | 5 | A15 | A14 | A13 | (Offset)
ON | ON | ON | L | L | L | 0x0000 – 0x1FFF
ON | ON | OFF | L | L | H | 0x2000 – 0x3FFF
ON | OFF | ON | L | H | L | 0x4000 – 0x5FFF
ON | OFF | OFF | L | H | H | 0x6000 – 0x7FFF
OFF | ON | ON | H | L | L | 0x8000 – 0x9FFF
OFF | ON | OFF | H | L | H | 0xA000 – 0xBFFF
OFF | OFF | ON | H | H | L | 0xC000 – 0xDFFF
OFF | OFF | OFF | H | H | H | 0xE000 – 0xFFFF
Table 2: 8k cartridges memory banks
DIP-Switch | Address Bits | EPROM Address
3 | 4 | 5 | A15 | A14 | A13 | (Offset)
ON | ON | X | L | L | X | 0x0000 – 0x3FFF
ON | OFF | X | L | H | X | 0x4000 – 0x7FFF
OFF | ON | X | H | L | X | 0x8000 – 0xBFFF
OFF | OFF | X | H | H | X | 0xC000 – 0xFFFF
Table 3: 16k cartridges memory banks

The C64 address must not be confused with the EPROM Address offset.

### 2.4. Solder Bridges

Instead of setting jumpers and the DIP-Switch, solder bridges can be utilized to configure the Versa64Cart. This is an option, in case the configuration of the Versa64Cart is not prone to be
changed. Solder bridges are used to “hard wire” the configuration.
Signal | HIGH | LOW
GAME | JP4 = open | JP4 = closed
EXROM | JP5 = open | JP5 = closed
A15 | JP8 = open, (JP9 = closed) | JP8 = closed, (JP9 = open)
A14 | JP10 = open, (JP11 = closed) | JP10 = closed, (JP11 = open)
A13 | JP12 = open, (JP14 = closed) | JP12 = closed, (JP14 = open)
Table 4: Configuration with solder bridges

The jumpers in ( ) are only required, in case the pull-up resistors R2, R3 and R4 are not populated. Never (!!!!) close both jumpers of one address signal. It cannot be LOW and HIGH at the same time, this will produce a SHORT CIRCUIT!!!!

The footprints of the jumpers J5 and J6 are designed to be solder bridged, when not populated.

## 3. Assembly of the Versa64Cart

The Versa64Cart can work with a minimum of components when being configured with solder bridges. Just the EPROM and a 100nF capacitor is required.

- The reset switch is nice to have, but it is just an option.
- The DIP-switch can be replaced by configuring the solder bridges JP4, 5, 8, 10 and 12.

Drafted by Sven Petersen | Page 5 of 11 | Doc.-No.: 121-6-01-01.6
- The pull-up resistors (R2-4) can be omitted and JP9, 11, 14 can be utilized to set a HIGH level on A15 … A13 (BE CAREFUL, see warning above!). If you are not sure, keep the pull up resistors.
- J5 and J6 can be hard wired with solder bridges.
- R1, D1 and D2 are only required in 16k modes.
- The EPROM can be soldered, a socket is not necessary

Soldering the EPROM can be required if a shallow cartridge case is used. A socket might add too much height. In this case, it is advised to test the EPROM with a Versa64Cart with a socket before.

## 4. Retrieving the binary and the settings from a CRT file

### 4.1. VICE cartconv

The CRT file format is created to emulate cartridges with VICE or devices like the Ultimate II+ etc. It should not be programmed into an EPROM; this will not work.

Instead, the binary has to be retrieved from the CRT file. The binary is a file that can be used for programming EPROMs. Also, it is possible to find out the required settings for GAME and

EXROM .

The utility that is used here is CARTCONV, which is a command line too that comes with VICE (C64 emulator). For the examples, CARTCONV and the cartridge files are copied to the same directory. To start, enter cmd into the search box on the task bar of Windows 10.

First the CRT information is required. Enter the following command

cartconv -f mycartridge.crt

mycartridge.crt stands for the crt file, that you want to convert.

The second step is to generate a *.bin file from the *.crt. The *.bin file can be used to program EPROMs.

cartconv -i mycartridge.crt -o mycartridge.bin

### 4.2. Example I

C:\cartconv>cartconv -f deadtest.CRT
CRT Version: 1.0
Name: C64DEADTESTREV718220
Hardware ID: 0 (Generic Cartridge)
Mode: exrom: 1 game: 0 (ultimax)

offset sig type bank start size chunklen $000040 CHIP ROM #000 $e000 $2000 $2010

total banks: 1 size: $002000

The important information is colored red in the above example.

First of all, it has to be a generic cartridge (Hardware ID 0). Many (game or special) cartridges have additional hardware build it, that is required for proper operation. That might be one of manifold automatic bank switching circuits, a freezer circuit like in the Final Cartridge etc.

Drafted by Sven Petersen | Page 6 of 11 | Doc.-No.: 121-6-01-01.6

Next, EXROM has to be 1 (HIGH) and GAME has to be 0 (LOW) Þ DIP Switch 1=ON, 2=OFF.

The ultimax mode is mentioned here, too. The start address is $e000 (0xE000). Referring to Table 1, J6 has to be set to ROMH . The size is $2000 (which is hexadecimal for 8k). Hence jumper J5 is set to “switch”. It is assumed, that the binary is programmed to the first 8k of the EPROM, so the address lines A15, A14 and A13 are L, L, L Þ the switches 3-5 are ON.

Item | cartconv | Setting
GAME | 0 (= LOW) | SW1-1 = ON
EXROM | 1 (= HIGH) | SW1-2 = OFF
size | $2000 (=8k cartridge) | A13 (J5) = “Switch”
start | $E000 | OE (J6) = ROMH
EPROM offset | $2000 | A15…13 = LLL Þ SW1-3 = ON SW1-4 = ON SW1-5 = ON

Now the deadtest.bin file can be generated:

C:\cartconv>cartconv -i deadtest.CRT -o deadtest.bin
Input file : deadtest.CRT
Output file : deadtest.bin
Conversion from Generic Cartridge .crt to binary format successful.

### 4.3. Example II

C:\cartconv>cartconv -f diag04.crt
CRT Version: 1.0
Name: 586220PLUS_0.4
Hardware ID: 0 (Generic Cartridge)
Mode: exrom: 0 game: 1 (8k Game)
offset | sig | type | bank start size | chunklen
$000040 CHIP ROM | #000 $8000 $2000 $2010
total banks: 1 size: $002000

Here, the Hardware ID is 0 (Generic Cartridge) again. The Versa64Cart is suitable for running the software. Now, it is assumed, that the first 8k are already in use and the binary should be programmed to the second 8k slot of the EPROM.

Item | cartconv | Setting
GAME | 1 (= HIGH) | SW1-1 = OFF
EXROM | 0 (= LOW) | SW1-2 = ON
size | $2000 (=8k cartridge) | A13 (J5) = “Switch”
start | $8000 | OE (J6) = ROML
EPROM offset | $2000 | A15…13 = LLH Þ SW1-3 = ON SW1-4 = ON SW1-5 = OFF

Drafted by Sven Petersen | Page 7 of 11 | Doc.-No.: 121-6-01-01.6

The binary conversion is exactly the same like in Example I.

### 4.4. Example III

C:\cartconv>cartconv -f neutron.crt CRT Version: 1.0
Name: NEUTRON
Hardware ID: 0 (Generic Cartridge)
Mode: exrom: 0 game: 0 (16k Game)
offset | sig | type | bank start size | chunklen
$000040 CHIP ROM | #000 $8000 $4000 $4010
total banks: 1 size: $004000

Again, it is assumed, the binaries should be programmed to the first 16k of the EPROM.

Item | cartconv | Setting
GAME | 0 (= LOW) | SW1-1 = ON
EXROM | 0 (= LOW) | SW1-2 = ON
size | $4000 (=16k cartridge) | A13 (J5) = “16k” OE (J6) = “16k”
start | $8000 | Not relevant in 16k mode
EPROM offset | $0000 | A15…13 = LLL Þ SW1-3 = ON SW1-4 = ON SW1-5 = ON

The binary conversion is exactly the same like in Example I.

### 4.5. Example IV

C:\cartconv>cartconv -f batman.crt
CRT Version: 1.0
Name: batman
Hardware ID: 5 (Ocean)
Mode: exrom: 0 game: 1 (8k Game)
Warning: game in crt image set incorrectly.
offset | sig | type | bank start size | chunklen
$000040 CHIP ROM | #000 $8000 $2000 $2010
$002050 CHIP ROM | #001 $8000 $2000 $2010
[…]
$01e130 CHIP ROM #015 $8000 $2000 $2010
total banks: 16 size: $020000

Here, the hardware ID is not 0 (generic). The Versa64Cart is not suitable for this software. The size is $20000, which is 128kB, more than what fits into the memory space of the C64. This kind of software requires a cartridge with a certain automatic bank switching circuit, in this case the Ocean cartridge type and a 27C010 (128kx8bit) EPROM is required.

Drafted by Sven Petersen | Page 8 of 11 | Doc.-No.: 121-6-01-01.6

## 5. EPROMs

Four different types/sizes of EPROMs can be used with the Versa64Cart, not all settings make sense with them. Their pin out is shown in Table 5.

The effect of the settings and the recommended configurations are shown in Table 6.

27C64
| 27C128
| 27C256
| 27C512
| SOCKET
Vpp | Vpp | Vpp | A15 | 1 | A15 | VCC | 28 | VCC | VCC | VCC | VCC
A12 | A12 | A12 | A12 | 2 | A12 | A14 | 27 | A14 | A14 | /PGM | /PGM
A7 | A7 | A7 | A7 | 3 | A7 | A13 | 26 | A13 | A13 | A13 | n.c.
A6 | A6 | A6 | A6 | 4 | A6 | A8 | 25 | A8 | A8 | A8 | A8
A5 | A5 | A5 | A5 | 5 | A5 | A9 | 24 | A9 | A9 | A9 | A9
A4 | A4 | A4 | A4 | 6 | A4 | A11 | 23 | A11 | A11 | A11 | A11
A3 | A3 | A3 | A3 | 7 | A3 | /OE | 22 | /G/Vpp | /G | /G | /G
A2 | A2 | A2 | A2 | 8 | A2 | A10 | 21 | A10 | A10 | A10 | A10
A1 | A1 | A1 | A1 | 9 | A1 | GND | 20 | /E | /E | /E | /E
A0 | A0 | A0 | A0 | 10 | A0 | D7 | 19 | D7 | D7 | D7 | D7
D0 | D0 | D0 | D0 | 11 | D0 | D6 | 18 | D6 | D6 | D6 | D6
D1 | D1 | D1 | D1 | 12 | D1 | D5 | 17 | D5 | D5 | D5 | D5
D2 | D2 | D2 | D2 | 13 | D2 | D4 | 16 | D4 | D4 | D4 | D4
GND | GND | GND | GND | 14 | GND | D3 | 15 | D3 | D3 | D3 | D3
Table 5: EPROM pin compatibility
EPROM | Size | A15 | A14 | A13 | 16k
27C512 | 64kx8 | yes | yes | yes | yes
27C256 | 32kx8 | HIGH | yes | yes | yes
27C128 | 16kx8 | HIGH | HIGH | yes | yes
27C64 | 8kx8 | HIGH | HIGH | HIGH | no
Table 6: Settings per EPROM type

In case Vpp is located at a dedicated pin (pin 1), A15 has no effect anymore. A HIGH level is recommended (switch is off) . The /PGM Pin should be set HIGH. The n.c. (not connected) pin should be HIGH (with pull-up) or open. For an 8k EPROM, the 16k setting makes no sense.

## 6. Using parallel EEPROMs

There are parallel EPROMs, which fit into the EPROM sockets. They do not require erasing with a UV eraser, like EPROMs, but the price is higher.

Since they can be written, which is controlled by the WE signal, but the Super Expander II cartridge is lacking of this functionality, this signal has to be HIGH (inactive). The 28C256 has the A14 signal connected to Pin 1, which is A15 of the EEPROM socket. This is no problem, but it has to be kept in mind, that the jumper for A15 has effect on the bank select A14 of the EPROM.

Drafted by Sven Petersen | Page 9 of 11 | Doc.-No.: 121-6-01-01.6

28C64
| 28C256
| SOCKET
n.c. | A14 | 1 | A15 | VCC | 28 | VCC | VCC
A12 | A12 | 2 | A12 | A14 | 27 | /WE | /WE
A7 | A7 | 3 | A7 | A13 | 26 | A13 | n.c
A6 | A6 | 4 | A6 | A8 | 25 | A8 | A8
A5 | A5 | 5 | A5 | A9 | 24 | A9 | A9
A4 | A4 | 6 | A4 | A11 | 23 | A11 | A11
A3 | A3 | 7 | A3 | /OE | 22 | /G/Vpp | /OE
A2 | A2 | 8 | A2 | A10 | 21 | A10 | A10
A1 | A1 | 9 | A1 | GND | 20 | /E | /CE
A0 | A0 | 10 | A0 | D7 | 19 | D7 | D7
D0 | D0 | 11 | D0 | D6 | 18 | D6 | D6
D1 | D1 | 12 | D1 | D5 | 17 | D5 | D5
D2 | D2 | 13 | D2 | D4 | 16 | D4 | D4
GND | GND | 14 | GND | D3 | 15 | D3 | D3
Table 7: EEPROM pin compatibility
EEPROM | Size | A15 | A14 | A13
28C256 | 32kx8 | =A14 | OPEN | yes
28C64 | 8kx8 | OPEN | OPEN | OPEN
Table 8: Settings per EEPROM type

## 7. Startup and Trouble shooting

Before you insert the Versa64Cart into the expansion port of the C64, you should make sure, that there are no fatal failures on it. In the worst case, it will produce a short circuit.

- Check the solder joints on the solder side
- Check the orientation of the socket. The notch is at the side, where the capacitor is
- In case you have used the solder bridges to configure the address, check according to the warning in chapter 2.4 or measure the resistance between pin 1 and 2 (that is GND and +5V) of the edge connector (without an EPROM inserted). It must not be less than about 3kΩ.
- After inserting the EPROM, check if the notch is at the same side like the notch of the socket. Check all pins are properly seated in the socket and not bent inwards or outwards.

After all these points are correct, nothing really bad can happen to your C64 anymore. If you get a black screen or a normal startup display with less than 38911 Basic Bytes free, you might have a configuration problem.

- Did you program the EPROM with a proper *.bin and not with the *.crt file? CRT files are not suitable to program an EPROM. Refer to chapter 4.
- Did you set the configuration bits correctly? ON means LOW
- Did you select the required OE (J6)?
- Did you jumper A13 (J5) as required?
- In case it is a 16k cartridge: Are R1, D1 and D2 placed?

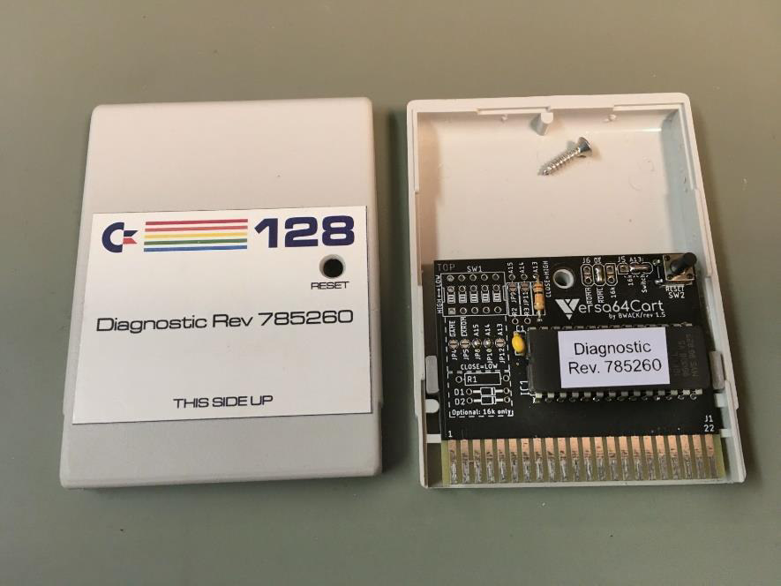
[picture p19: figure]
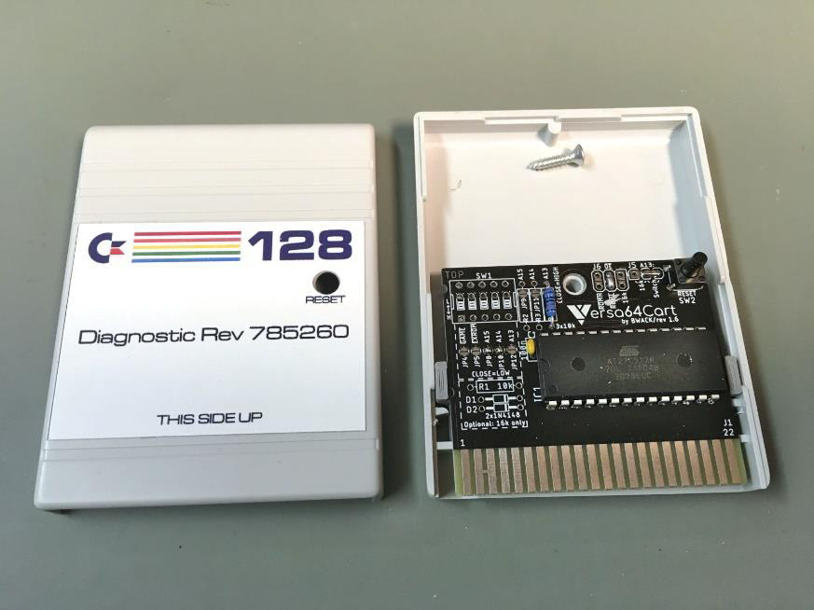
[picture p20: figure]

Drafted by Sven Petersen | Page 10 of 11 | Doc.-No.: 121-6-01-01.6

## 8. Suitable Cases

There are several case options:

1. The Versa64case (https://github.com/svenpetersen1965/Versa64Case) is a 3D-Printed case with a lid. It fits the Versa64cart with a socketed EPROM
2. The Maszczyk KM-20 (https://www.tme.eu/de/en/details/abs-20b/multipurpose-enclosures/maszczyk/km-20b-gy/) case (e.g. available from tme.eu) – no EPROM socket possible
3. The Kradex Z-7 (https://www.tme.eu/de/en/details/z-7/enclosures-with-panel/kradex/z7/) case (e.g. available from tme.eu) – no EPROM socket possible

### 4. Stumpy cartridge case from https://www.thefuturewas8bit.com/ EPROM on a low profile

socket possible.

For the KM-20 and the Z-7, an 3D printed adapter (https://github.com/svenpetersen1965/Versa64cart-adapter_km20-z7) helps to keep the Versa64cart straight. It is not a requirement, but an elegant way to solve a (minor) problem. The reset button should have a height of 9.5mm for this case.

Figure 3: The Versa64cart in a Kradex Z-7 case

Figure 4: The Versa64cart in a Maszczyk KM-20 case

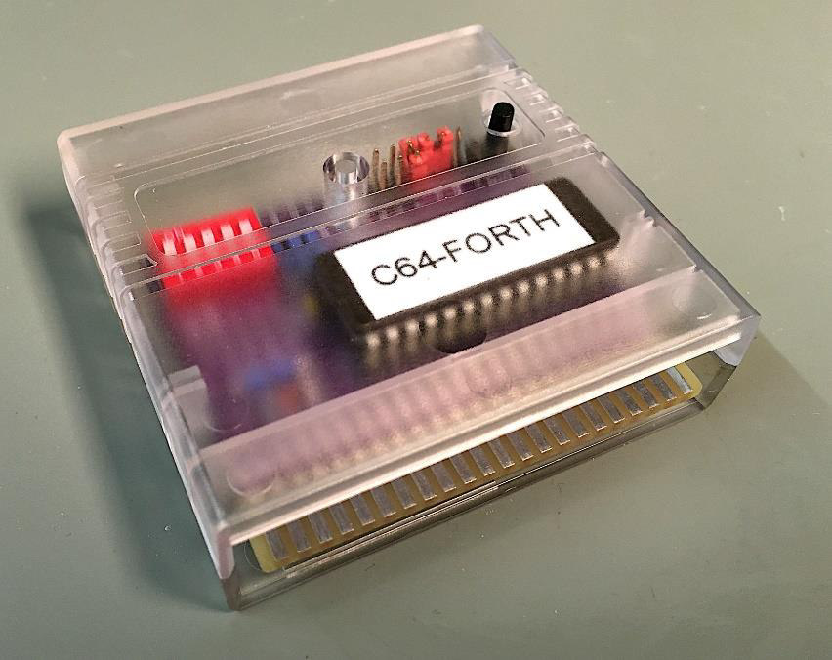
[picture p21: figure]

Drafted by Sven Petersen | Page 11 of 11 | Doc.-No.: 121-6-01-01.6

Figure 5: The Versa64cart (Rev. 1.6) in a Stumpy cartridge case

For the Stumpy cartridge case, the Reset button should have a height of 11mm.

## 9. Revision History

### 9.1. Rev. 1.1 Þ Rev. 1.2

- Schematic and layout were redrawn in Eagle (v 9.2)
- All solder bridges (jumpers) are located on the component side now (the footprint of the jumpers includes the solder bridge option)

### - A13…A15 can be configured by solder bridges now - No test points for A13…A15 anymore

- The jumpers are moved to the outer edge for easier access
- J5 for the configuration of A13 is a 3-pin jumper now
- A reset switch is added
- A configuration table is added on the solder side

### 9.2. Rev. 1.2 Þ Rev. 1.3

Some issues with cartridge cases were fixed.

- The diodes D1 & D2 and R1 were moved north by 4.93mm
- D1&D2 moved east by 4.6mm, R1 by 2.54mm
- IC1&C1 moved west by 1.59mm

### 9.3. Rev. 1.3 Þ Rev. 1.4

- The width of the contact pads of the expansion port was reduced to 1.5mm and the whole area is free of solder stop mask.

### 9.4. Rev. 1.4 Þ Rev. 1.5

- The DIP-Switch SW1 can be replaced with a jumper

### 9.5. Rev. 1.5 Þ Rev. 1.6

- Notches added to fit the thefuturewas8bit.com stumpy cartridge case (not the button hole!)

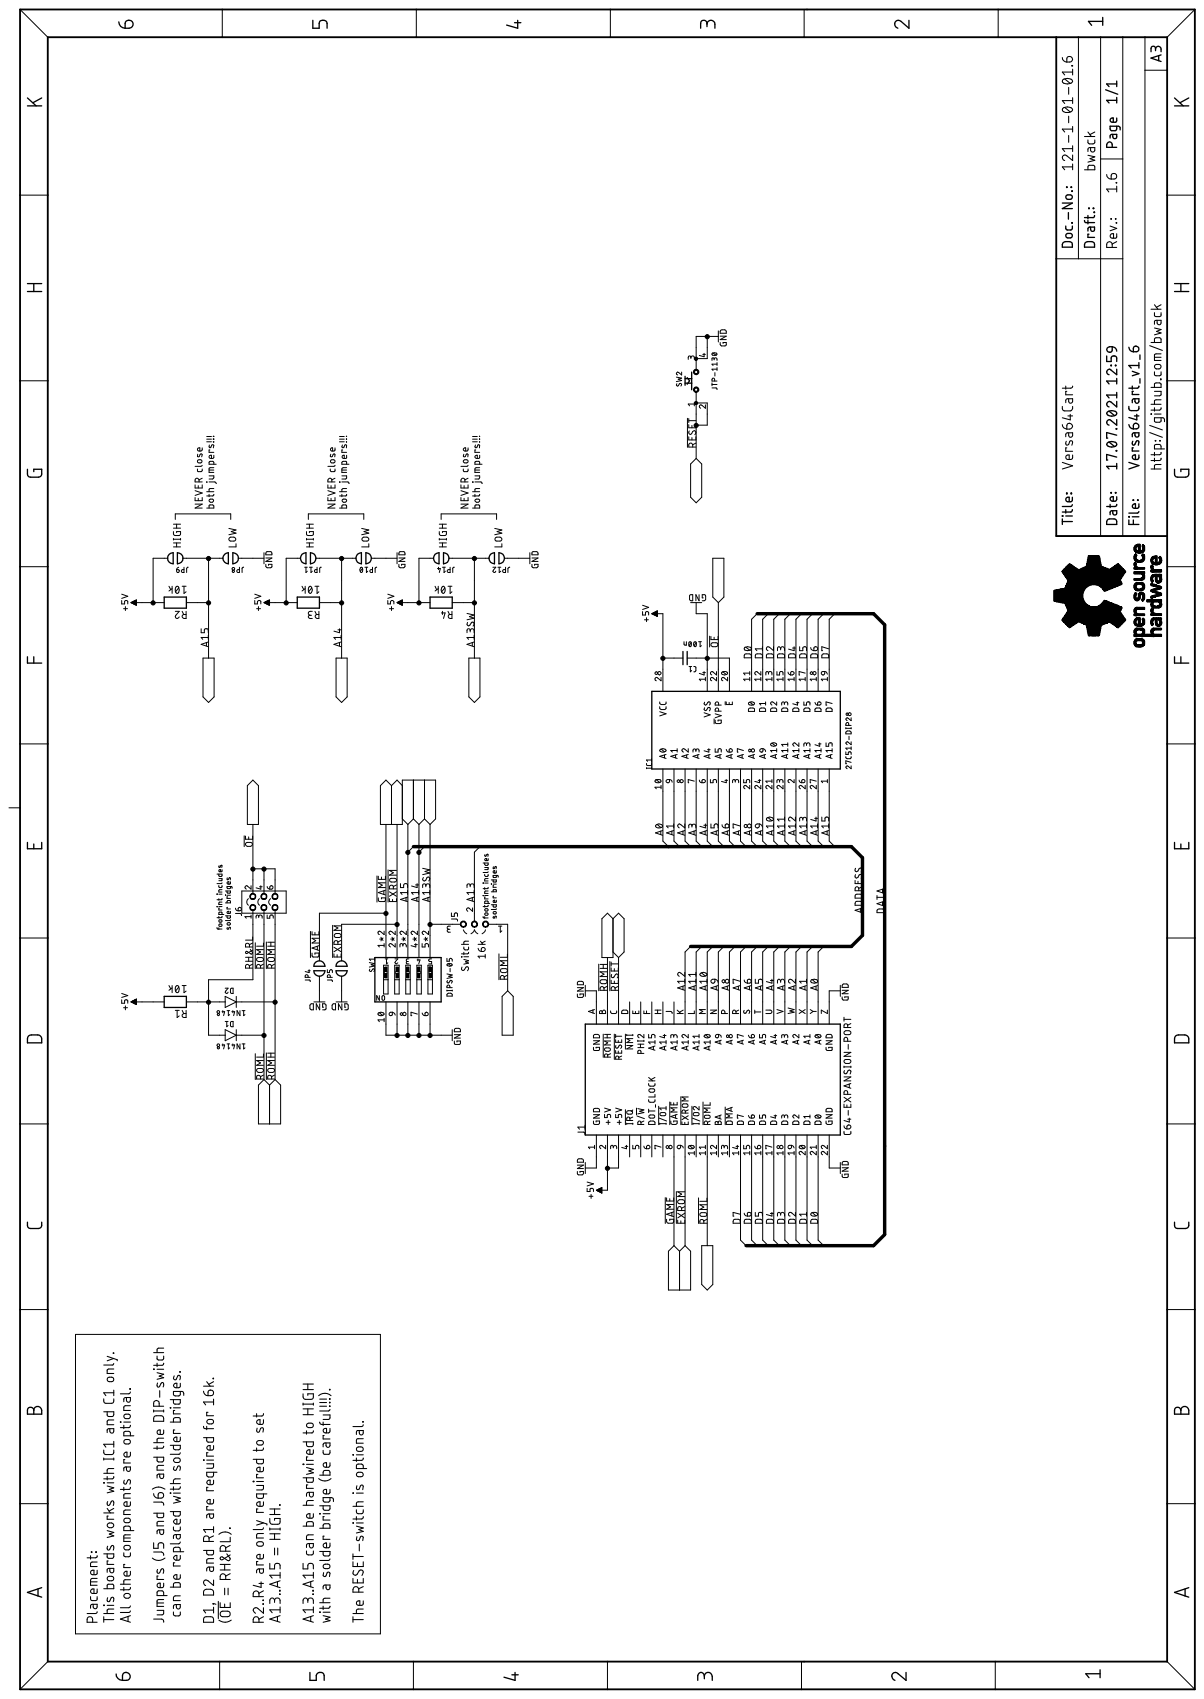
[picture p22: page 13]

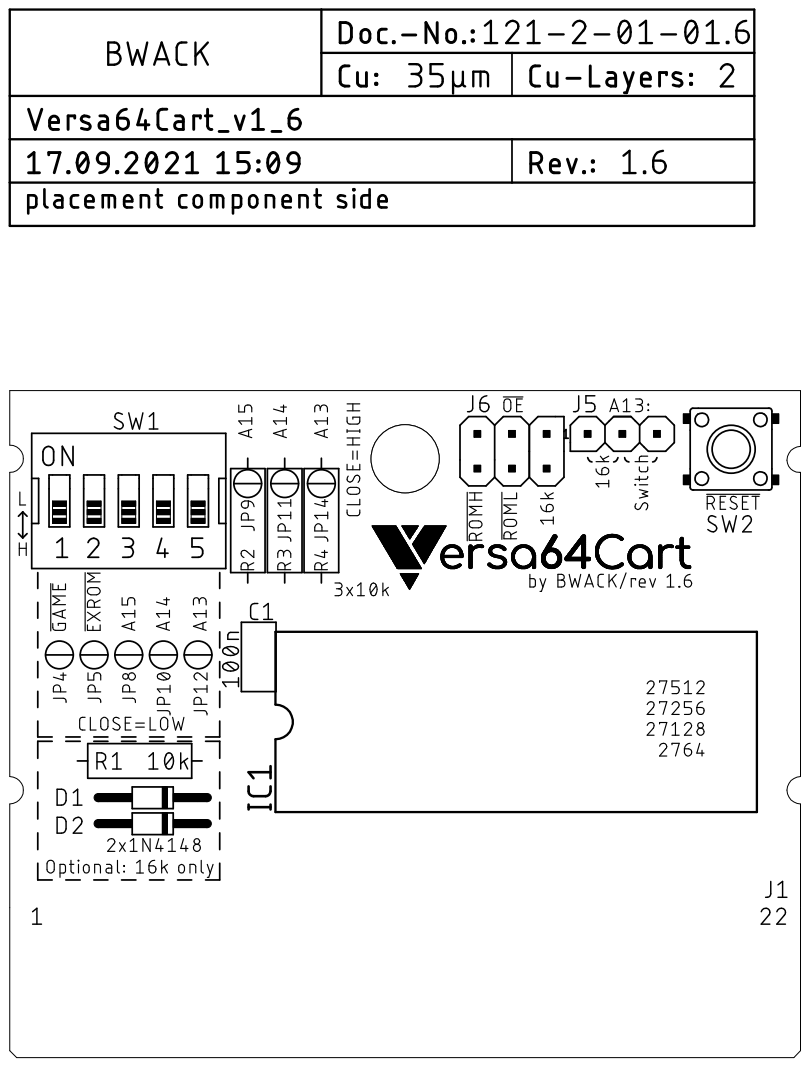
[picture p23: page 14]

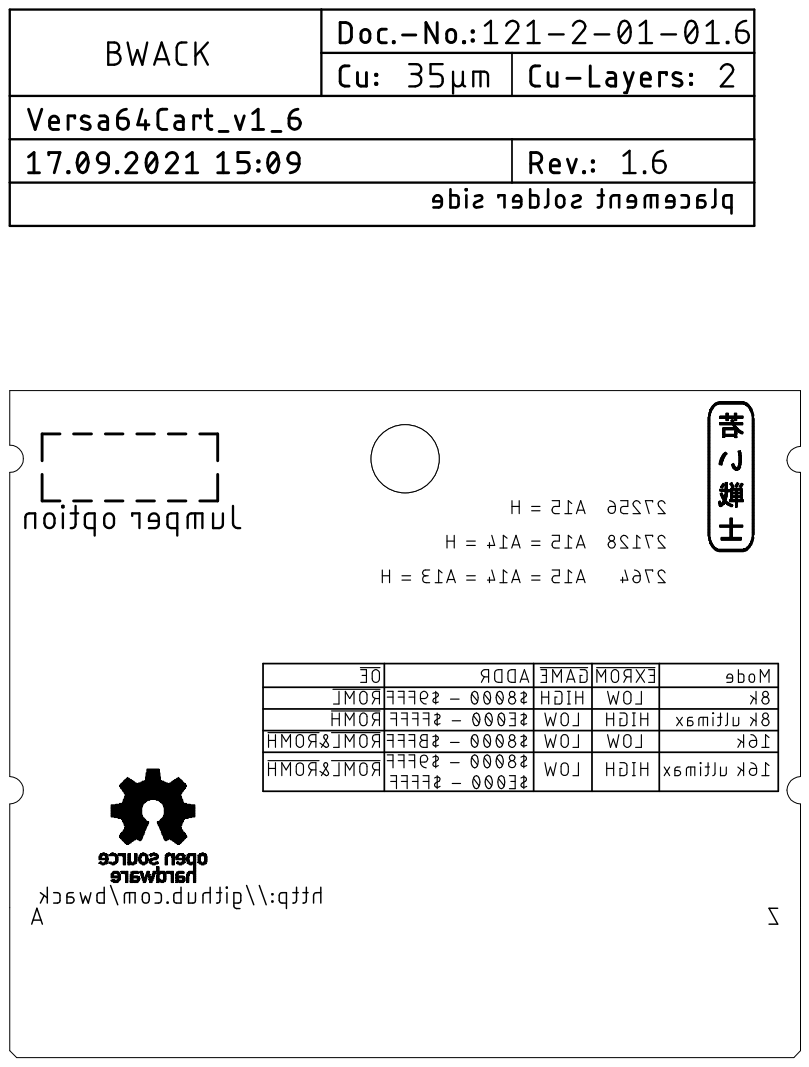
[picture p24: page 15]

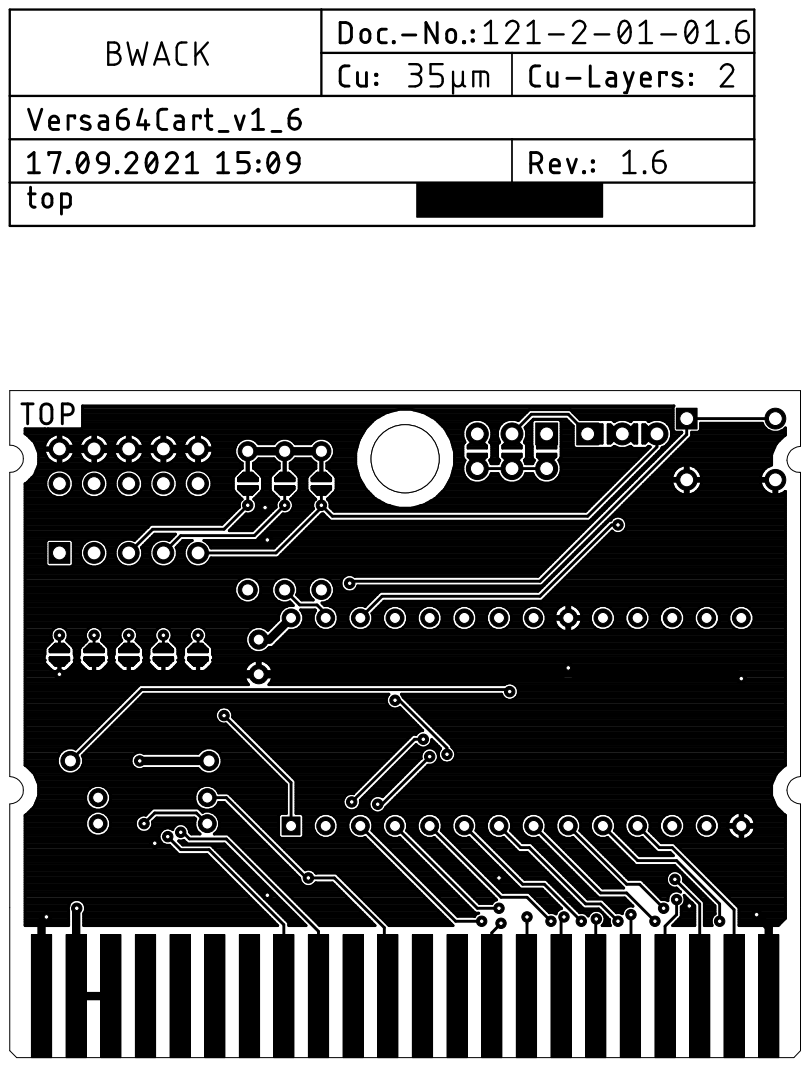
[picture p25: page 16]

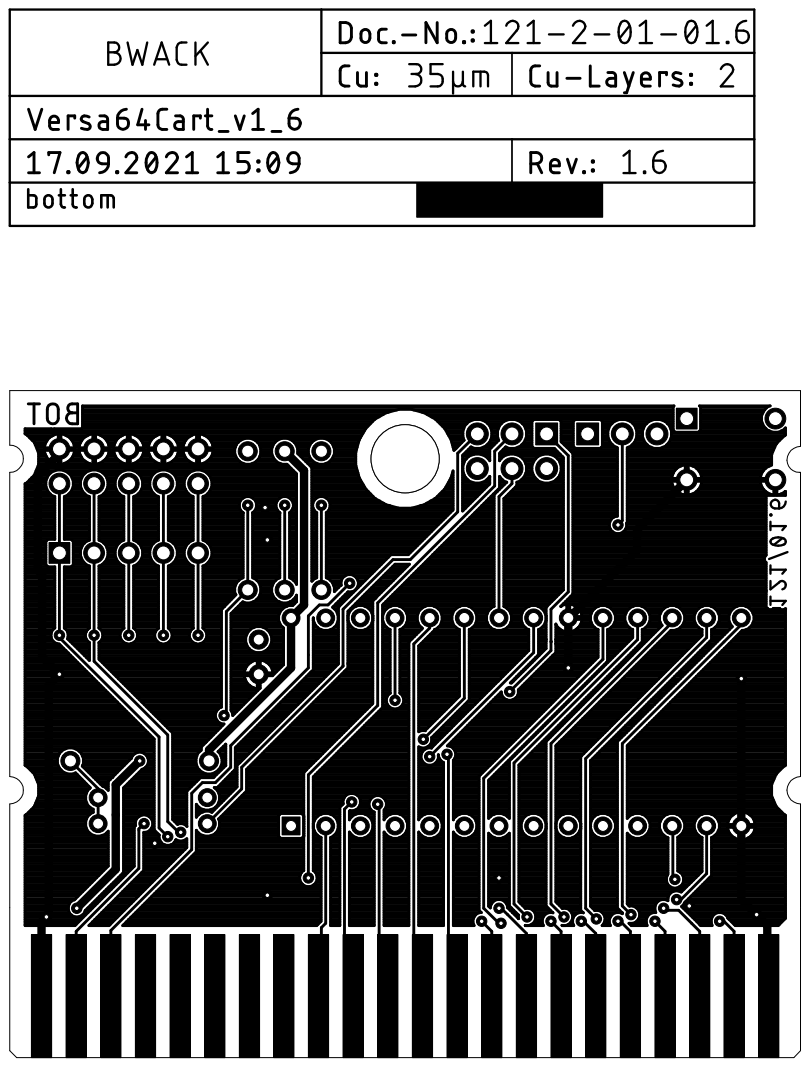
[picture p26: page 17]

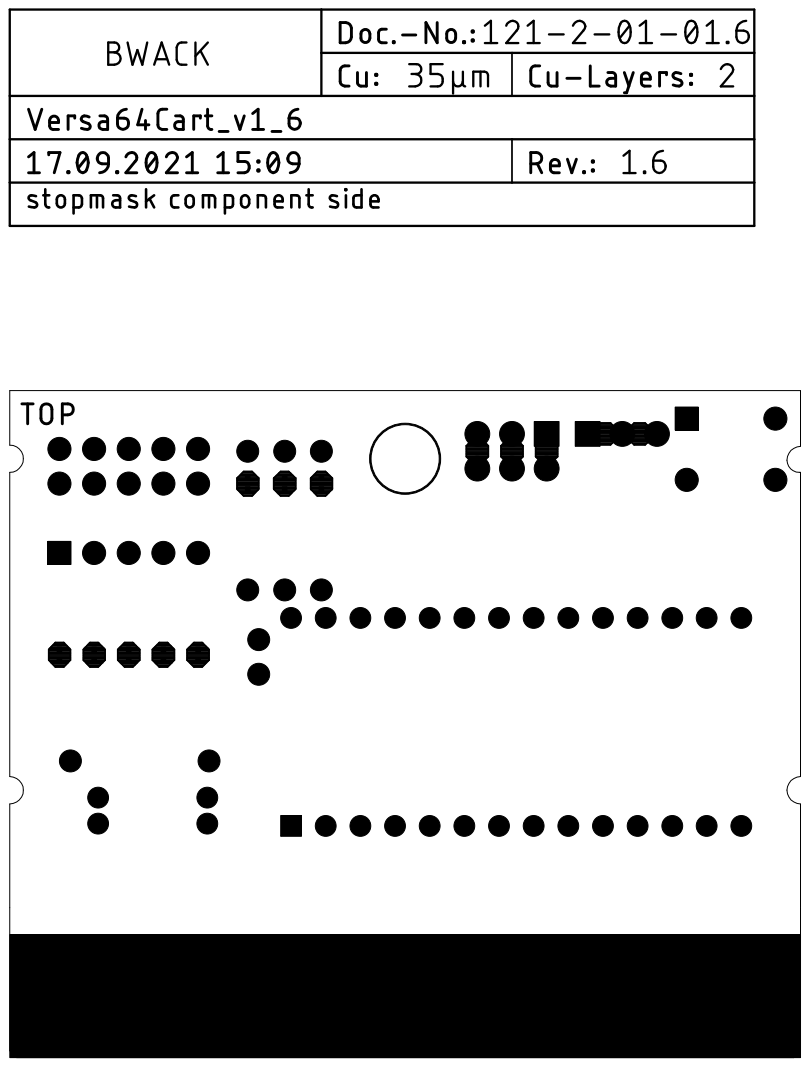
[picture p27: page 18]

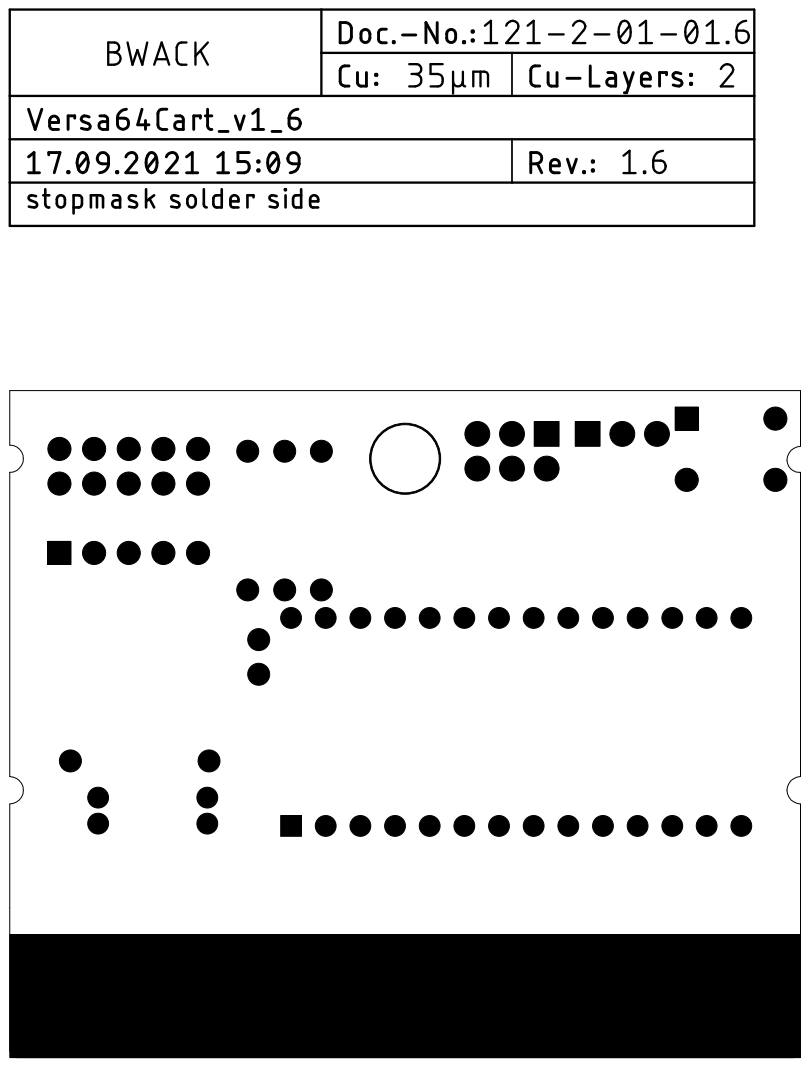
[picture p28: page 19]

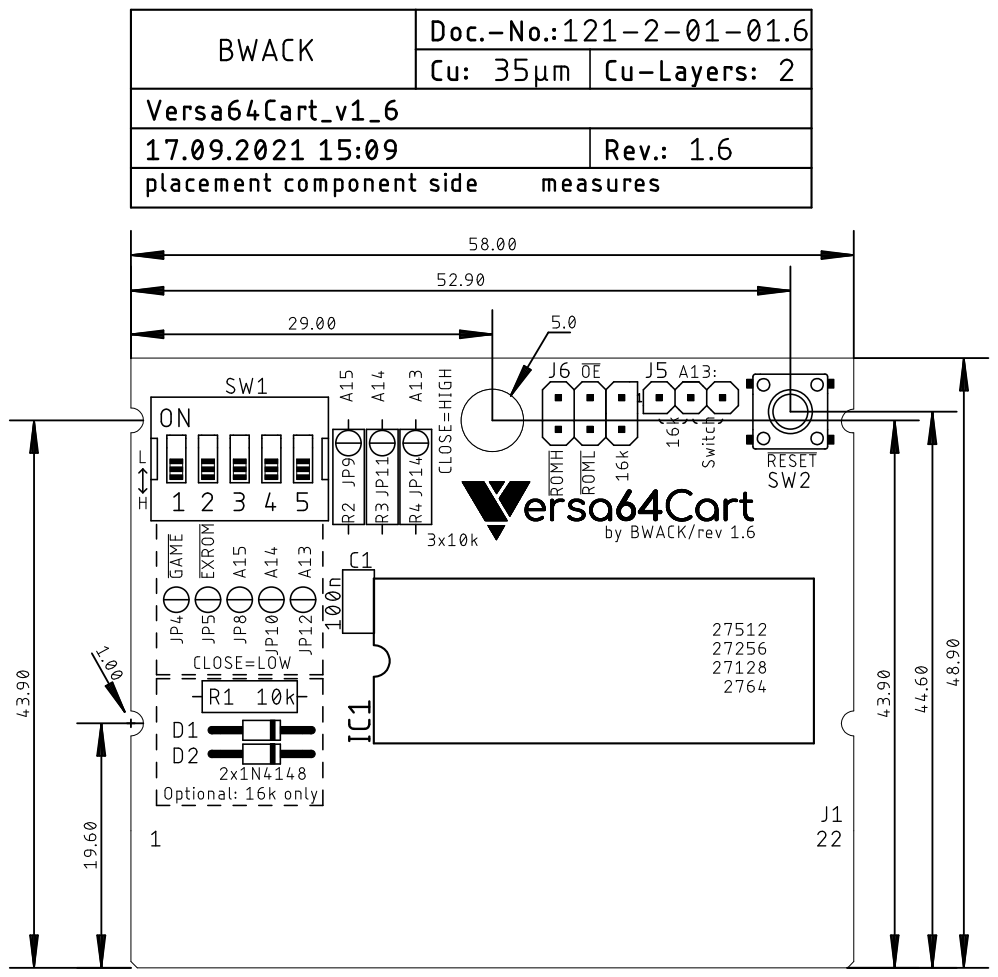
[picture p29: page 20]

Versa64Cart_FunD_v1_6.docx | | 19.12.2021 16:27
Drafted by Sven Petersen | Page 1 of 1 | Doc.-No.: 121-6-02-01.6

### Versa64Cart v1.6

### Functional Description

J1 are the contacts, that fit into the Commodore C64 expansion port. The pin numbering is identical to those of the C64. IC1 is the EPROM, which can be socketed or not. C1 is the blocking capacitor, that should help to keep the noise from the supply voltage out of the IC.

The configuration is achieved with the DIP-Switch SW1, jumper J5 and jumper J6. SW1-1 and SW1-2 set the signals GAME and EXROM . These signalize the C64 the mode of the cartridge. The switches SW1-3 to SW3-5 are responsible for the (manual) bank select: The configure the three most sufficient address bit of the EPROM, since those are not asserted by the C64, which only addresses 8kB blocks. The Dip Switch can be replaced with a jumper (2x5).

For 16kB cartridges, a further address bit (A13) is required. Since this kind of cartridge uses both chip selects ( ROML and ROMH ) the signal ROML is used for this purpose. It will be low, while the lower 8kB are addressed and HIGH, while the upper 8kB are addressed.

The 16k cartridge configuration requires to combine ROML and ROMH to one chip select signal. This function is provided by the wired AND circuit D1, D2 and R1. R1 is pulling the RH&RL signal HIGH. In case one of those signals is low, the RH&RL is driven LOW.

The required chip select signal can be selected with J6.

In 8k mode, the address bit A13 is set by the DIP-switch. Jumper J5 has to be set to the
“Switch” position.

While GAME and EXROM utilize the pull-up resistors inside the C64, the address signals A13 to A15 require Pull-Up resistors on the cartridge board (R2-R4). There are solder bridges on the component side if the Versa64Cart, that can be used alternatively to the DIP-Switch to pull each signal low. In case the Pull-Up resistors R2-R4 are not populated, additional solder bridges can be used to set A13 – A15 to a HIGH level (only those, that are set to a HIGH level). It is obvious, that closing the HIGH bridge and the LOW bridge of a signal at the same time produces a short circuit.

SW2 is the reset switch. A pull-up resistor on the C64 mainboard is utilized here.

Versa64Cart_Test_v1_6.docx | | 19.12.2021 16:30
Drafted by Sven Petersen | Page 1 of 4 | Doc.-No.: 121-6-03-01.6

### Versa64Cart v1.6

### Testing

## Test Description

The electrical test was executed with a Versa64Cart v1.2 (the differences to v1.3 to v1.6 are not functional), a C64G (Mainboard ASSY 250469) and an EPROM type ST micro M27C512 10F1. The programming of the EPROM was done with a TL866II Plus programmer.

The following binaries were loaded into the program memory of the programmer, programed to the EPROM and verified “ok”:

Binary | Binary # | Start Address | End Address
Neutron.bin | 1 | 0x0000 | 0x3FFF
Deadtest.bin | 2 | 0x4000 | 0x5FFF
586220plus_0_4.bin | 3 | 0x6000 | 0x7FFF
LalaPrologue.bin | 4 | 0x8000 | 0xBFFF

The EPROM was inserted into the socket of Versa64Cart, which was then configured, inserted into the C64, the C64 was switched on and the selected binary was run.

## Test Execution

Binary # | A15..13 | GAME | EXROM | J6 OE
J5 A13 Observation | Testing
1 | LLL | L | L | 16k | 16k | working | ok
2 | LHL | L | H | ROMH | Switch | working | ok
3 | LHH | H | L | ROML | Switch | working | ok
4 | HLL | L | L | 16k | 16k | working | ok
Test | Observation | Testing
Does the Cart fit into the slot? | yes | ok
Does the Cart move inside the slot? | The Cart moves 0.9mm from left to right in total. The contacts of the cartridge connector do not leave the contact pad. | ok
Comparison of measures v1.2 vs. v1.1 | Both PCBs have the same dimensions. The mounting holes are aligned. The port contacts are aligned, the contacts of v1.2 are wider. | ok
Reset button | Binary #1 can be restarted by pushing the reset button. Some software (e.g. LalaPrologue.bin) does not reset well after pressing the RESET button. It depends on that software, not on the memory bank. | ok
Running cartridge with a breakout board, which adds 90mm to the bus | Binary #1 is running Þ The bus length is not critical | ok

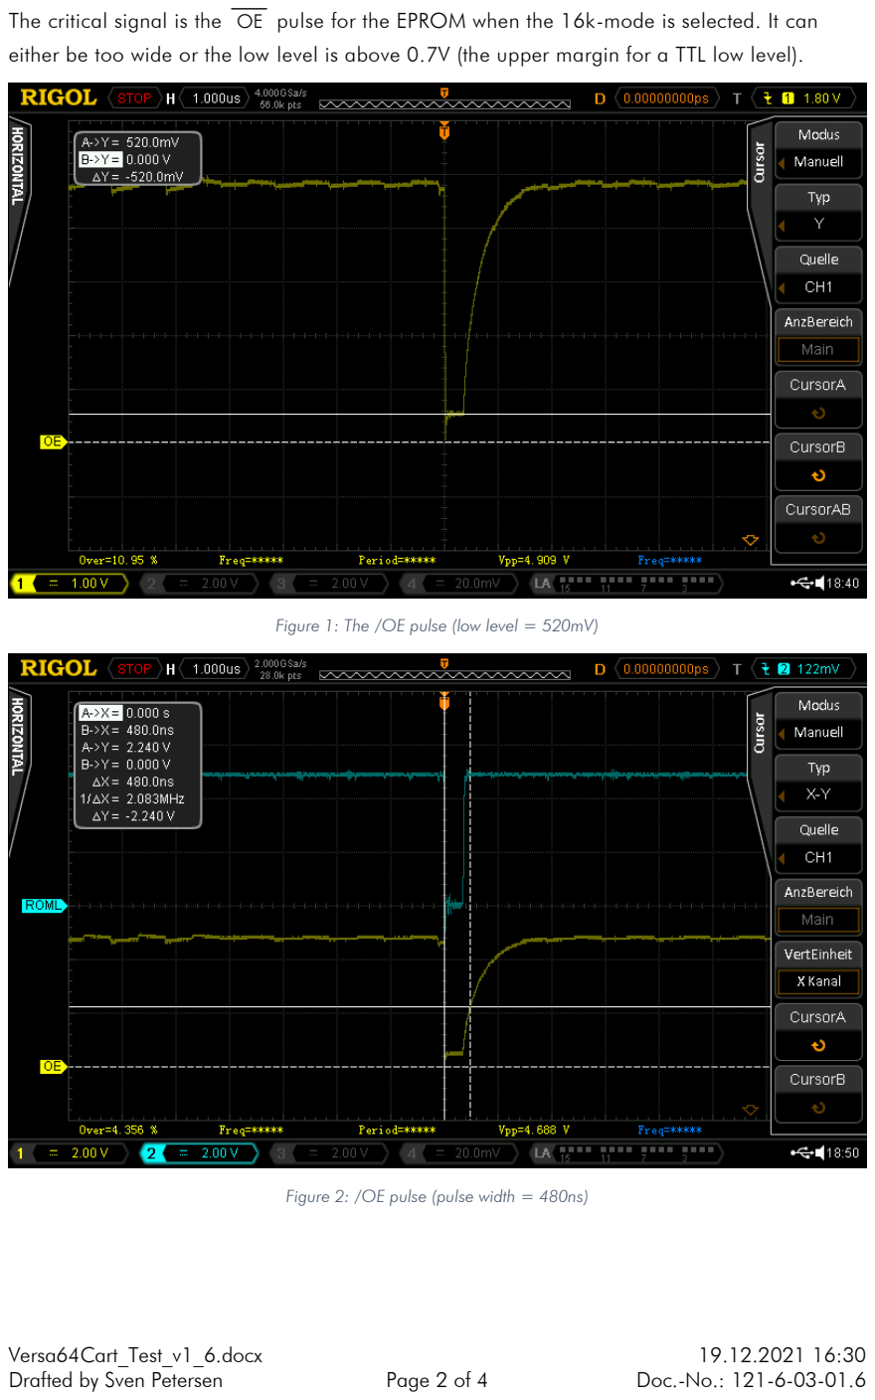
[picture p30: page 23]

Versa64Cart_Test_v1_6.docx | | 19.12.2021 16:30
Drafted by Sven Petersen | Page 2 of 4 | Doc.-No.: 121-6-03-01.6

The critical signal is the OE pulse for the EPROM when the 16k-mode is selected. It can either be too wide or the low level is above 0.7V (the upper margin for a TTL low level).

Figure 1: The /OE pulse (low level = 520mV)

Figure 2: /OE pulse (pulse width = 480ns)

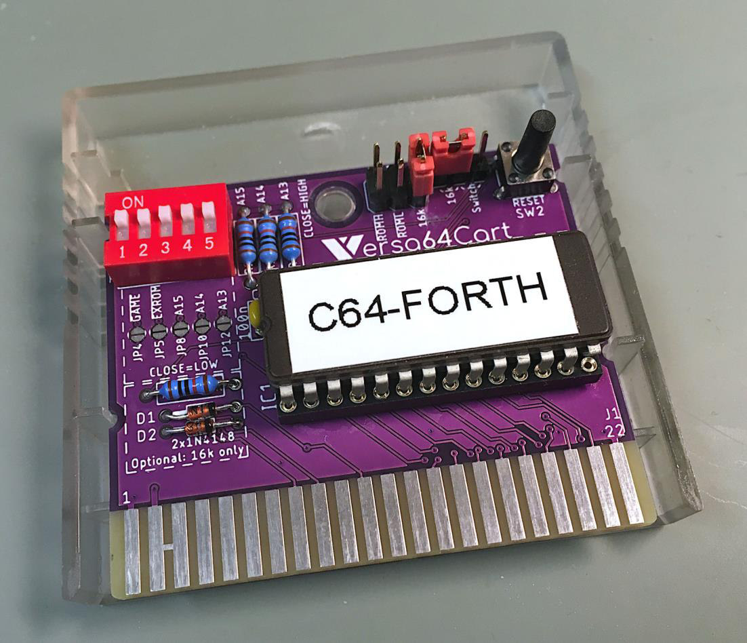
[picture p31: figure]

Versa64Cart_Test_v1_6.docx | | 19.12.2021 16:30
Drafted by Sven Petersen | Page 3 of 4 | Doc.-No.: 121-6-03-01.6
Test | Observation | Testing
Low level of the 16k- OE pulse below 0.7V | The low level is 520mV | ok
Pulse width of the 16k-OE pulse less than 500ns (?) | The pulse width is 480ns | ok (?)
Test | Observation | Testing
Neutron.bin & LalaPrologue.bin were programmed into a 27C256, A15 was set HIGH | Both games started and played properly. | ok
LalaPrologue.bin was programmed into a 27C128A, A15 & A14 were set HIGH | Game started and played properly. | ok
1541diagcart.bin was programmed into a 27C164A, A13..A15:HHH, GAME : H, EXROM : L, OE : ROML | Software started and worked properly | ok

## Testing the Rev. 1.6 in a Stumpy Cartridge Case

Figure 3: Versa64cart Rev. 1.6 on an open Stumpy cartridge case

Versa64Cart_Test_v1_6.docx | | 19.12.2021 16:30
Drafted by Sven Petersen | Page 4 of 4 | Doc.-No.: 121-6-03-01.6

## Conclusion

### - All extra address lines (A15 … A13) can be asserted

- GAME can be configured properly
- EXROM can be configured properly
- ROML works as a chip select
- ROMH works as a chip select
- The 16k OE works properly, the timing cannot be proved ok, due to a lack of

information.
- All binaries are running (16k, 8k Game, 8k Exrom)
- EPROM types tested: ST M27C512, M27C256B, M27C128A, M27C64A
- The notches of Rev. 1.6 fit the Stumpy cartridge case.

The Versa64Cart v1.6 is fully functional.

Pos. Qty Value Footprint Ref.-No. Comment

1 1 121-2-01-01.6 2 Layer PCB Rev. 1.6 2 layer, Cu 35µ, HASL, 58mm x 48.9mm, 1.6mm FR4

2 1 100n C-2,5 C1 ceramic capacitor, pitch 2.54

3 4 10k R-10 R1, R2, R3, R4 resistors
4 2 1N4148 DO-35 D1, D2 diodes

5 1 27C512 DIL28 IC1 EPROM. Also possible: 27C256, 27C128 and 27C64

6 1 socket DIL28 (IC1) IC socket for the EPROM

7 1 Pinheader 3x1 pin 1x3p J5 2.54mm pitch (0.1") pinheader (option: 90°)

8 1 Pinheader 3x2 pin 2x3p J6 2.54mm pitch (0.1") pinheader (option: 90°)

9 2 Jumper 2.54mm 2.54mm (J5), (J6) Jumper to be placed on J5 and J6

10 1 DIPSW-05V DIPSW-05V SW1 Standard DIP-Switch with 5 switches (switch side facing up)

The DIP-Switch can be replaced with a normal 2x5 jumper.

11 1 JTP-1130 JTP-1130 SW2 Standard 6x6mm tact switch, e.g. Namae JTP-1130 or any

other

### Rev. 1.2 → 1.3

Pos 1 new board revision

### Rev. 1.3 → 1.4

Pos 1 new board revision

### Rev. 1.4 → 1.5

Pos 1 new board revision

### Rev. 1.5 → 1.6

Pos 1 new board revision

## Versa64Cart Rev. 1.6

## Bill of Material Rev. 1.60

Versa64Cart_BOM_v1_60.xlsx

Drafted by Sven Petersen Page 1 of 1

17.09.2021 15:41
Doc.No.: 121-5-01-01.60

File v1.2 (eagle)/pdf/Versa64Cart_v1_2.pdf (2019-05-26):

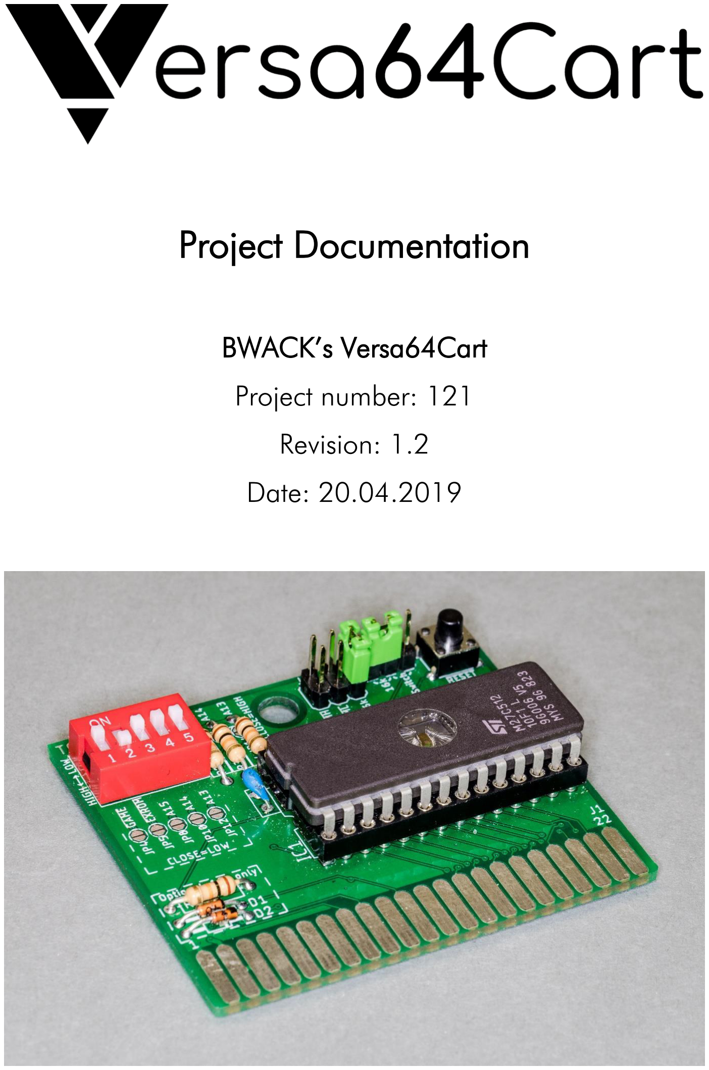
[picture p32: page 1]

# Project Documentation

# BWACK’s Versa64Cart

## Project number: 121

## Revision: 1.2

## Date: 20.04.2019

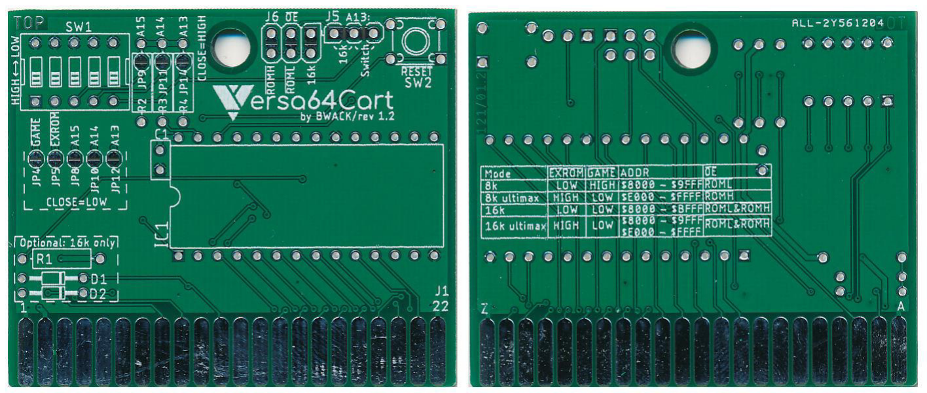
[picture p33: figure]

Versa64Cart_ModD_v1_2.docx | | 24.05.2019 16:38
Drafted by Sven Petersen | Page 1 of 9 | Doc.-No.: 121-6-01-01.2

# Versa64Cart v1.2

# Module Description

Content

Figure 1: Both sides of the Versa64Cart Rev. 1.2


Drafted by Sven Petersen | Page 2 of 9 | Doc.-No.: 121-6-01-01.2

# 1. Introduction

The Versa64Cart is a generic EPROM cartridge for the Commodore C64 and C128. It can be configured as 8k, 16k, 8k ultimax or 16k ultimax cartridge. Further on, the most sufficient address bits of the EPROM can be set by a DIP-switch which offers a manual bank switching for multi game/multi ROM cart option.

The Versa64Cart is not suitable to run a Kernal or software, which require bank switching by that software (e.g. games > 16k).

Figure 2: Versa64Cart - placement and dimensions

## 2. Configuration

### 2.1. Explanation

The extension cartridges signalize their configuration with two flags. Those are GAME and

EXROM . For addressing the EPROM, the C64 offers two chip-select signals for an 8kB address

space, which are ROML and ROMH . The chip-select signals are required to locate the EPROM

Drafted by Sven Petersen | Page 3 of 9 | Doc.-No.: 121-6-01-01.2

content within the address space of the C64. It is possible to use either ROML , ROMH or combining both to get a 16kB address space in total.

Mode | EXROM | GAME | OE

Address space

8k | LOW | HIGH | ROML | 0x8000 – 0x9FFF
8k ultimax | HIGH | LOW | ROMH | 0xE000 – 0xFFFF
16k | LOW | LOW | ROML & ROMH = “16k” | 0x8000 – 0xBFFF
16k ultimax | HIGH | LOW | ROML & ROMH = “16k” | 0x8000 – 0x9FFF + 0xE000 – 0xFFFF

Table 1: Cartridge configuration
In the “ultimax” modes, the Kernal ROM (0xE000 – 0xFFFF) is replaced by the content of the EPROM of the Versa64Cart. The Reset vector is located at 0xFFFC and 0xFFFD. This is a guidepost for the microprocessor, which shows where to start the execution after the processor was powered up (or received a RESET pulse). This way, the software in the EPROM will completely take control.

In EXROM mode, the C64 Kernal (the one on the mainboard) will check the memory locations
0x8004-0x8008 for the “cartridge signature” CBM80 (PETSCII 0xC3, 0xC2, 0xCD, 0x38, 0x30). If
this sequence is found, the execution will follow the cartridge cold start vector located at the first two
memory addresses of the EPROM (0x8000 and 0x8001 in the C64’s address space).

### 2.2. Jumper & DIP-Switch Settings

The DIP-Switch SW1 configures the cartridge mode and the three most sufficient address bit of the EPROM (the “bank switching”). Annotation: ON position connects the signal to ground (=LOW).

The jumper J6 ( OE ) sets the chip select signal for the EPROM. It can be ROML , ROMH or
“16k”(this is a diode logic AND of ROML and ROMH ).

The jumper J5 (A13) can be set to “Switch” or “16k”. “Switch” means, that A13 is set by the DIP-Switch, “16k” means, that A13 is controlled by the ROML signal.

A 16k cartridge requires both jumpers (J5 and J6) set to “16k”.

For the required settings refer to Table 1.

### 2.3. Bank Switching

The EPROM offers more memory (27C512 = 64kB), than it is required for a generic 8k or 16k cartridge. On account of this an EPROM can keep the content of several cartridges. The DIP-Switch SW1 (3, 4, 5 = A15, A14 and A13) selects, which of these cartridges is selected. In 16k mode, the setting of A13 is ignored.

Drafted by Sven Petersen | Page 4 of 9 | Doc.-No.: 121-6-01-01.2
DIP-Switch | Address Bits | EPROM Address
3 | 4 | 5 | A15 | A14 | A13 | (Offset)
ON | ON | ON | L | L | L | 0x0000 – 0x1FFF
ON | ON | OFF | L | L | H | 0x2000 – 0x3FFF
ON | OFF | ON | L | H | L | 0x4000 – 0x5FFF
ON | OFF | OFF | L | H | H | 0x6000 – 0x7FFF
OFF | ON | ON | H | L | L | 0x8000 – 0x9FFF
OFF | ON | OFF | H | L | H | 0xA000 – 0xBFFF
OFF | OFF | ON | H | H | L | 0xC000 – 0xDFFF
OFF | OFF | OFF | H | H | H | 0xE000 – 0xFFFF
Table 2: 8k cartridges memory banks
DIP-Switch | Address Bits | EPROM Address
3 | 4 | 5 | A15 | A14 | A13 | (Offset)
ON | ON | X | L | L | X | 0x0000 – 0x3FFF
ON | OFF | X | L | H | X | 0x4000 – 0x7FFF
OFF | ON | X | H | L | X | 0x8000 – 0xBFFF
OFF | OFF | X | H | H | X | 0xC000 – 0xFFFF
Table 3: 16k cartridges memory banks

The C64 address must not be confused with the EPROM Address offset.

### 2.4. Solder Bridges

Instead of setting jumpers and the DIP-Switch, solder bridges can be utilized to configure the Versa64Cart. This is an option, in case the configuration of the Versa64Cart is not prone to be
changed. Solder bridges are used to “hard wire” the configuration.
Signal | HIGH | LOW
GAME | JP4 = open | JP4 = closed
EXROM | JP5 = open | JP5 = closed
A15 | JP8 = open, (JP9 = closed) | JP8 = closed, (JP9 = open)
A14 | JP10 = open, (JP11 = closed) | JP10 = closed, (JP11 = open)
A13 | JP12 = open, (JP14 = closed) | JP12 = closed, (JP14 = open)
Table 4: Configuration with solder bridges

The jumpers in ( ) are only required, in case the pull-up resistors R2, R3 and R4 are not populated. Never (!!!!) close both jumpers of one address signal. It cannot be LOW and HIGH at the same time, this will produce a SHORT CIRCUIT!!!!

The footprints of the jumpers J5 and J6 are designed to be solder bridged, when not populated.

## 3. Assembly of the Versa64Cart

The Versa64Cart can work with a minimum of components when being configured with solder bridges. Just the EPROM and a 100nF capacitor is required.

- The reset switch is nice to have, but it is just an option.
- The DIP-switch can be replaced by configuring the solder bridges JP4, 5, 8, 10 and 12.

Drafted by Sven Petersen | Page 5 of 9 | Doc.-No.: 121-6-01-01.2
- The pull-up resistors (R2-4) can be omitted and JP9, 11, 14 can be utilized to set a HIGH level on A15 … A13 (BE CAREFUL, see warning above!). If you are not sure, keep the pull up resistors.
- J5 and J6 can be hard wired with solder bridges.
- R1, D1 and D2 are only required in 16k modes.
- The EPROM can be soldered, a socket is not necessary

Soldering the EPROM can be required if a shallow cartridge case is used. A socket might add too much height. In this case, it is advised to test the EPROM with a Versa64Cart with a socket before.

## 4. Retrieving the binary and the settings from a CRT file

### 4.1. VICE cartconv

The CRT file format is created to emulate cartridges with VICE or devices like the Ultimate II+ etc. It should not be programmed into an EPROM; this will not work.

Instead, the binary has to be retrieved from the CRT file. The binary is a file that can be used for programming EPROMs. Also, it is possible to find out the required settings for GAME and

EXROM .

The utility that is used here is CARTCONV, which is a command line too that comes with VICE (C64 emulator). For the examples, CARTCONV and the cartridge files are copied to the same directory. To start, enter cmd into the search box on the task bar of Windows 10.

First the CRT information is required. Enter the following command

cartconv -f mycartridge.crt

mycartridge.crt stands for the crt file, that you want to convert.

The second step is to generate a *.bin file from the *.crt. The *.bin file can be used to program EPROMs.

cartconv -i mycartridge.crt -o mycartridge.bin

### 4.2. Example I

C:\cartconv>cartconv -f deadtest.CRT
CRT Version: 1.0
Name: C64DEADTESTREV718220
Hardware ID: 0 (Generic Cartridge)
Mode: exrom: 1 game: 0 (ultimax)

offset sig type bank start size chunklen $000040 CHIP ROM #000 $e000 $2000 $2010

total banks: 1 size: $002000

The important information is colored red in the above example.

First of all, it has to be a generic cartridge (Hardware ID 0). Many (game or special) cartridges have additional hardware build it, that is required for proper operation. That might be one of manifold automatic bank switching circuits, a freezer circuit like in the Final Cartridge etc.

Drafted by Sven Petersen | Page 6 of 9 | Doc.-No.: 121-6-01-01.2

Next, EXROM has to be 1 (HIGH) and GAME has to be 0 (LOW) Þ DIP Switch 1=ON, 2=OFF.

The ultimax mode is mentioned here, too. The start address is $e000 (0xE000). Referring to Table 1, J6 has to be set to ROMH . The size is $2000 (which is hexadecimal for 8k). Hence jumper J5 is set to “switch”. It is assumed, that the binary is programmed to the first 8k of the EPROM, so the address lines A15, A14 and A13 are L, L, L Þ the switches 3-5 are ON.

Item | cartconv | Setting
GAME | 0 (= LOW) | SW1-1 = ON
EXROM | 1 (= HIGH) | SW1-2 = OFF
size | $2000 (=8k cartridge) | A13 (J5) = “Switch”
start | $E000 | OE (J6) = ROMH
EPROM offset | $2000 | A15…13 = LLL Þ SW1-3 = ON SW1-4 = ON SW1-5 = ON

Now the deadtest.bin file can be generated:

C:\cartconv>cartconv -i deadtest.CRT -o deadtest.bin
Input file : deadtest.CRT
Output file : deadtest.bin
Conversion from Generic Cartridge .crt to binary format successful.

### 4.3. Example II

C:\cartconv>cartconv -f diag04.crt
CRT Version: 1.0
Name: 586220PLUS_0.4
Hardware ID: 0 (Generic Cartridge)
Mode: exrom: 0 game: 1 (8k Game)
offset | sig | type | bank start size | chunklen
$000040 CHIP ROM | #000 $8000 $2000 $2010
total banks: 1 size: $002000

Here, the Hardware ID is 0 (Generic Cartridge) again. The Versa64Cart is suitable for running the software. Now, it is assumed, that the first 8k are already in use and the binary should be programmed to the second 8k slot of the EPROM.

Item | cartconv | Setting
GAME | 1 (= HIGH) | SW1-1 = OFF
EXROM | 0 (= LOW) | SW1-2 = ON
size | $2000 (=8k cartridge) | A13 (J5) = “Switch”
start | $8000 | OE (J6) = ROML
EPROM offset | $2000 | A15…13 = LLH Þ SW1-3 = ON SW1-4 = ON SW1-5 = OFF

Drafted by Sven Petersen | Page 7 of 9 | Doc.-No.: 121-6-01-01.2

The binary conversion is exactly the same like in Example I.

### 4.4. Example III

C:\cartconv>cartconv -f neutron.crt CRT Version: 1.0
Name: NEUTRON
Hardware ID: 0 (Generic Cartridge)
Mode: exrom: 0 game: 0 (16k Game)
offset | sig | type | bank start size | chunklen
$000040 CHIP ROM | #000 $8000 $4000 $4010
total banks: 1 size: $004000

Again, it is assumed, the binaries should be programmed to the first 16k of the EPROM.

Item | cartconv | Setting
GAME | 0 (= LOK) | SW1-1 = OFF
EXROM | 0 (= LOW) | SW1-2 = ON
size | $4000 (=16k cartridge) | A13 (J5) = “16k” OE (J6) = “16k”
start | $8000 | Not relevant in 16k mode
EPROM offset | $0000 | A15…13 = LLL Þ SW1-3 = ON SW1-4 = ON SW1-5 = ON

The binary conversion is exactly the same like in Example I.

### 4.5. Example IV

C:\cartconv>cartconv -f batman.crt
CRT Version: 1.0
Name: batman
Hardware ID: 5 (Ocean)
Mode: exrom: 0 game: 1 (8k Game)
Warning: game in crt image set incorrectly.
offset | sig | type | bank start size | chunklen
$000040 CHIP ROM | #000 $8000 $2000 $2010
$002050 CHIP ROM | #001 $8000 $2000 $2010
[…]
$01e130 CHIP ROM #015 $8000 $2000 $2010
total banks: 16 size: $020000

Here, the hardware ID is not 0 (generic). The Versa64Cart is not suitable for this software. The size is $20000, which is 128kB, more than what fits into the memory space of the C64. This kind of software requires a cartridge with a certain automatic bank switching circuit, in this case the Ocean cartridge type and a 27C010 (128kx8bit) EPROM is required.

Drafted by Sven Petersen | Page 8 of 9 | Doc.-No.: 121-6-01-01.2

## 5. EPROMs

Four different types/sizes of EPROMs can be used with the Versa64Cart, not all settings make sense with them. Their pin out is shown in Table 5.

The effect of the settings and the recommended configurations are shown in Table 6.

27C64
| 27C128
| 27C256
| 27C512
| SOCKET
Vpp | Vpp | Vpp | A15 | 1 | A15 | VCC | 28 | VCC | VCC | VCC | VCC
A12 | A12 | A12 | A12 | 2 | A12 | A14 | 27 | A14 | A14 | /PGM | /PGM
A7 | A7 | A7 | A7 | 3 | A7 | A13 | 26 | A13 | A13 | A13 | n.c.
A6 | A6 | A6 | A6 | 4 | A6 | A8 | 25 | A8 | A8 | A8 | A8
A5 | A5 | A5 | A5 | 5 | A5 | A9 | 24 | A9 | A9 | A9 | A9
A4 | A4 | A4 | A4 | 6 | A4 | A11 | 23 | A11 | A11 | A11 | A11
A3 | A3 | A3 | A3 | 7 | A3 | /OE | 22 | /G/Vpp | /G | /G | /G
A2 | A2 | A2 | A2 | 8 | A2 | A10 | 21 | A10 | A10 | A10 | A10
A1 | A1 | A1 | A1 | 9 | A1 | GND | 20 | /E | /E | /E | /E
A0 | A0 | A0 | A0 | 10 | A0 | D7 | 19 | D7 | D7 | D7 | D7
D0 | D0 | D0 | D0 | 11 | D0 | D6 | 18 | D6 | D6 | D6 | D6
D1 | D1 | D1 | D1 | 12 | D1 | D5 | 17 | D5 | D5 | D5 | D5
D2 | D2 | D2 | D2 | 13 | D2 | D4 | 16 | D4 | D4 | D4 | D4
GND | GND | GND | GND | 14 | GND | D3 | 15 | D3 | D3 | D3 | D3
Table 5: EPROM pin compatibility
EPROM | Size | A15 | A14 | A13 | 16k
27C512 | 64kx8 | yes | yes | yes | yes
27C256 | 32kx8 | HIGH | yes | yes | yes
27C128 | 16kx8 | HIGH | HIGH | yes | yes
27C64 | 8kx8 | HIGH | HIGH | HIGH | no
Table 6: Settings per EPROM type

In case Vpp is located at a dedicated pin (pin 1), A15 has no effect anymore. A HIGH level is recommended (switch is off) . The /PGM Pin should be set HIGH. The n.c. (not connected) pin should be HIGH (with pull-up) or open. For an 8k EPROM, the 16k setting makes no sense.

## 6. Startup and Trouble shooting

Before you insert the Versa64Cart into the expansion port of the C64, you should make sure, that there are no fatal failures on it. In the worst case, it will produce a short circuit.

- Check the solder joints on the solder side
- Check the orientation of the socket. The notch is at the side, where the capacitor is
- In case you have used the solder bridges to configure the address, check according to the warning in chapter 2.4 or measure the resistance between pin 1 and 2 (that is GND and +5V) of the edge connector (without an EPROM inserted). It must not be less than about 3kΩ.
- After inserting the EPROM, check if the notch is at the same side like the notch of the socket. Check all pins are properly seated in the socket and not bent inwards or outwards.

Drafted by Sven Petersen | Page 9 of 9 | Doc.-No.: 121-6-01-01.2

After all these points are correct, nothing really bad can happen to your C64 anymore. If you get a black screen or a normal startup display with less than 38911 Basic Bytes free, you might have a configuration problem.

- Did you program the EPROM with a proper *.bin and not with the *.crt file? CRT files are not suitable to program an EPROM. Refer to chapter 4.
- Did you set the configuration bits correctly? ON means LOW
- Did you select the required OE (J6)?
- Did you jumper A13 (J5) as required?
- In case it is a 16k cartridge: Are R1, D1 and D2 placed?

## 7. Revision History

### 7.1. Rev. 1.1 Þ Rev. 1.2

- Schematic and layout were redrawn in Eagle (v 9.2)
- All solder bridges (jumpers) are located on the component side now (the footprint of the jumpers includes the solder bridge option)

### - A13…A15 can be configured by solder bridges now - No test points for A13…A15 anymore

- The jumpers are moved to the outer edge for easier access
- J5 for the configuration of A13 is a 3-pin jumper now
- A reset switch is added
- A configuration table is added on the solder side










Versa64Cart_FunD_v1_2.docx | | 24.05.2019 16:52
Drafted by Sven Petersen | Page 1 of 1 | Doc.-No.: 121-6-02-01.2

### Versa64Cart v1.2

### Functional Description

J1 are the contacts, that fit into the Commodore C64 expansion port. The pin numbering is identical to those of the C64. IC1 is the EPROM, which can be socketed or not. C1 is the blocking capacitor, that should help to keep the noise from the supply voltage out of the IC.

The configuration is achieved with the DIP-Switch SW1, jumper J5 and jumper J6. SW1-1 and SW1-2 set the signals GAME and EXROM . These signalize the C64 the mode of the cartridge. The switches SW1-3 to SW3-5 are responsible for the (manual) bank select: The configure the three most sufficient address bit of the EPROM, since those are not asserted by the C64, which only addresses 8kB blocks.

For 16kB cartridges, a further address bit (A13) is required. Since this kind of cartridge uses both chip selects ( ROML and ROMH ) the signal ROML is used for this purpose. It will be low, while the lower 8kB are addressed and HIGH, while the upper 8kB are addressed.

The 16k cartridge configuration requires to combine ROML and ROMH to one chip select signal. This function is provided by the wired AND circuit D1, D2 and R1. R1 is pulling the RH&RL signal HIGH. In case one of those signals is low, the RH&RL is driven LOW.

The required chip select signal can be selected with J6.

In 8k mode, the address bit A13 is set by the DIP-switch. Jumper J5 has to be set to the
“Switch” position.

While GAME and EXROM utilize the pull-up resistors inside the C64, the address signals A13 to A15 require Pull-Up resistors on the cartridge board (R2-R4). There are solder bridges on the component side if the Versa64Cart, that can be used alternatively to the DIP-Switch to pull each signal low. In case the Pull-Up resistors R2-R4 are not populated, additional solder bridges can be used to set A13 – A15 to a HIGH level (only those, that are set to a HIGH level). It is obvious, that closing the HIGH bridge and the LOW bridge of a signal at the same time produces a short circuit.

SW2 is the reset switch. A pull-up resistor on the C64 mainboard is utilized here.

Pos. | Qty Value | Footprint | Ref.-No. | Comment
1 | 1 121-2-01-01.2 | 2 Layer | PCB Rev. 0 | 2 layer, Cu 35µ, HASL, 58mm x 48.9mm, 1.6mm FR4
2 | 1 100n | C-2,5 | C1 | ceramic capacitor, pitch 2.54
3 | 4 10k | R-10 | R1, R2, R3, R4 | resistors
4 | 2 1N4148 | DO-35 | D1, D2 | diodes
5 | 1 27C512 | DIL28 | IC1 | EPROM. Also possible: 27C256, 27C128 and 27C64
6 | 1 socket | DIL28 | (IC1) | IC socket for the EPROM
7 | 1 Pinheader 3x1 pin | 1x3p | J5 | 2.54mm pitch (0.1") pinheader
8 | 1 Pinheader 3x2 pin | 2x3p | J6 | 2.54mm pitch (0.1") pinheader
9 | 2 Jumper 2.54mm | 2.54mm | (J5), (J6) | Jumper to be placed on J5 and J6
10 | 1 DIPSW-05V | DIPSW-05V | SW1 | Standard DIP-Switch with 5 switches (switch side facing up)
11 | 1 JTP-1130 | JTP-1130 | SW2 | Standard 6x6mm tact switch, e.g. Namae JTP-1130 or any
| | | | other

## Versa64Cart Rev. 1.2 Bill of Material Rev. 1.20

Versa64Cart_BOM_v1_20.xlsx
Drafted by Sven Petersen | Page 1 of 1

24.05.2019 15:36
Doc.No.: 121-5-01-00.0

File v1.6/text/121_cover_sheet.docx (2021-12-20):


Project Documentation

BWACK’s Versa64Cart

Project number: 121

Revision: 1.6

Date: 17.09.2021


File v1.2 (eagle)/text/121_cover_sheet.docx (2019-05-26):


Project Documentation

BWACK’s Versa64Cart

Project number: 121

Revision: 1.2

Date: 20.04.2019


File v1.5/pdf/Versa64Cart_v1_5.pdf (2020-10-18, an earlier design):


# Project Documentation

# BWACK’s Versa64Cart

## Project number: 121

## Revision: 1.5

## Date: 07.05.2020


Versa64Cart_ModD_v1_5.docx | | 18.10.2020 12:28
Drafted by Sven Petersen | Page 1 of 10 | Doc.-No.: 121-6-01-01.5

# Versa64Cart v1.5

# Module Description

Content

Figure 1: Both sides of the Versa64Cart Rev. 1.2


Drafted by Sven Petersen | Page 2 of 10 | Doc.-No.: 121-6-01-01.5

# 1. Introduction

The Versa64Cart is a generic EPROM cartridge for the Commodore C64 and C128. It can be configured as 8k, 16k, 8k ultimax or 16k ultimax cartridge. Further on, the most sufficient address bits of the EPROM can be set by a DIP-switch which offers a manual bank switching for multi game/multi ROM cart option.

The Versa64Cart is not suitable to run a Kernal or software, which require bank switching by that software (e.g. games > 16k).

Figure 2: Versa64Cart - placement and dimensions

## 2. Configuration

### 2.1. Explanation

The extension cartridges signalize their configuration with two flags. Those are GAME and

EXROM . For addressing the EPROM, the C64 offers two chip-select signals for an 8kB address

space, which are ROML and ROMH . The chip-select signals are required to locate the EPROM

Drafted by Sven Petersen | Page 3 of 10 | Doc.-No.: 121-6-01-01.5

content within the address space of the C64. It is possible to use either ROML , ROMH or combining both to get a 16kB address space in total.

Mode | EXROM | GAME | OE

Address space

8k | LOW | HIGH | ROML | 0x8000 – 0x9FFF
8k ultimax | HIGH | LOW | ROMH | 0xE000 – 0xFFFF
16k | LOW | LOW | ROML & ROMH = “16k” | 0x8000 – 0xBFFF
16k ultimax | HIGH | LOW | ROML & ROMH = “16k” | 0x8000 – 0x9FFF + 0xE000 – 0xFFFF

Table 1: Cartridge configuration
In the “ultimax” modes, the Kernal ROM (0xE000 – 0xFFFF) is replaced by the content of the EPROM of the Versa64Cart. The Reset vector is located at 0xFFFC and 0xFFFD. This is a guidepost for the microprocessor, which shows where to start the execution after the processor was powered up (or received a RESET pulse). This way, the software in the EPROM will completely take control.

In EXROM mode, the C64 Kernal (the one on the mainboard) will check the memory locations
0x8004-0x8008 for the “cartridge signature” CBM80 (PETSCII 0xC3, 0xC2, 0xCD, 0x38, 0x30). If
this sequence is found, the execution will follow the cartridge cold start vector located at the first two
memory addresses of the EPROM (0x8000 and 0x8001 in the C64’s address space).

### 2.2. Jumper & DIP-Switch Settings

The DIP-Switch SW1 configures the cartridge mode and the three most sufficient address bit of the EPROM (the “bank switching”). Annotation: ON position connects the signal to ground (=LOW).

The jumper J6 ( OE ) sets the chip select signal for the EPROM. It can be ROML , ROMH or
“16k”(this is a diode logic AND of ROML and ROMH ).

The jumper J5 (A13) can be set to “Switch” or “16k”. “Switch” means, that A13 is set by the DIP-
Switch, “16k” means, that A13 is controlled by the ROML signal.

A 16k cartridge requires both jumpers (J5 and J6) set to “16k”.

For the required settings refer to Table 1.

### 2.3. Bank Switching

The EPROM offers more memory (27C512 = 64kB), than it is required for a generic 8k or 16k cartridge. On account of this an EPROM can keep the content of several cartridges. The DIP-Switch SW1 (3, 4, 5 = A15, A14 and A13) selects, which of these cartridges is selected. In 16k mode, the setting of A13 is ignored.

The DIP-Switch can be replaced with a jumper.

Drafted by Sven Petersen | Page 4 of 10 | Doc.-No.: 121-6-01-01.5
DIP-Switch | Address Bits | EPROM Address
3 | 4 | 5 | A15 | A14 | A13 | (Offset)
ON | ON | ON | L | L | L | 0x0000 – 0x1FFF
ON | ON | OFF | L | L | H | 0x2000 – 0x3FFF
ON | OFF | ON | L | H | L | 0x4000 – 0x5FFF
ON | OFF | OFF | L | H | H | 0x6000 – 0x7FFF
OFF | ON | ON | H | L | L | 0x8000 – 0x9FFF
OFF | ON | OFF | H | L | H | 0xA000 – 0xBFFF
OFF | OFF | ON | H | H | L | 0xC000 – 0xDFFF
OFF | OFF | OFF | H | H | H | 0xE000 – 0xFFFF
Table 2: 8k cartridges memory banks
DIP-Switch | Address Bits | EPROM Address
3 | 4 | 5 | A15 | A14 | A13 | (Offset)
ON | ON | X | L | L | X | 0x0000 – 0x3FFF
ON | OFF | X | L | H | X | 0x4000 – 0x7FFF
OFF | ON | X | H | L | X | 0x8000 – 0xBFFF
OFF | OFF | X | H | H | X | 0xC000 – 0xFFFF
Table 3: 16k cartridges memory banks

The C64 address must not be confused with the EPROM Address offset.

### 2.4. Solder Bridges

Instead of setting jumpers and the DIP-Switch, solder bridges can be utilized to configure the Versa64Cart. This is an option, in case the configuration of the Versa64Cart is not prone to be
changed. Solder bridges are used to “hard wire” the configuration.
Signal | HIGH | LOW
GAME | JP4 = open | JP4 = closed
EXROM | JP5 = open | JP5 = closed
A15 | JP8 = open, (JP9 = closed) | JP8 = closed, (JP9 = open)
A14 | JP10 = open, (JP11 = closed) | JP10 = closed, (JP11 = open)
A13 | JP12 = open, (JP14 = closed) | JP12 = closed, (JP14 = open)
Table 4: Configuration with solder bridges

The jumpers in ( ) are only required, in case the pull-up resistors R2, R3 and R4 are not populated. Never (!!!!) close both jumpers of one address signal. It cannot be LOW and HIGH at the same time, this will produce a SHORT CIRCUIT!!!!

The footprints of the jumpers J5 and J6 are designed to be solder bridged, when not populated.

## 3. Assembly of the Versa64Cart

The Versa64Cart can work with a minimum of components when being configured with solder bridges. Just the EPROM and a 100nF capacitor is required.

- The reset switch is nice to have, but it is just an option.
- The DIP-switch can be replaced by configuring the solder bridges JP4, 5, 8, 10 and 12.

Drafted by Sven Petersen | Page 5 of 10 | Doc.-No.: 121-6-01-01.5
- The pull-up resistors (R2-4) can be omitted and JP9, 11, 14 can be utilized to set a HIGH level on A15 … A13 (BE CAREFUL, see warning above!). If you are not sure, keep the pull up resistors.
- J5 and J6 can be hard wired with solder bridges.
- R1, D1 and D2 are only required in 16k modes.
- The EPROM can be soldered, a socket is not necessary

Soldering the EPROM can be required if a shallow cartridge case is used. A socket might add too much height. In this case, it is advised to test the EPROM with a Versa64Cart with a socket before.

## 4. Retrieving the binary and the settings from a CRT file

### 4.1. VICE cartconv

The CRT file format is created to emulate cartridges with VICE or devices like the Ultimate II+ etc. It should not be programmed into an EPROM; this will not work.

Instead, the binary has to be retrieved from the CRT file. The binary is a file that can be used for programming EPROMs. Also, it is possible to find out the required settings for GAME and

EXROM .

The utility that is used here is CARTCONV, which is a command line too that comes with VICE (C64 emulator). For the examples, CARTCONV and the cartridge files are copied to the same directory. To start, enter cmd into the search box on the task bar of Windows 10.

First the CRT information is required. Enter the following command

cartconv -f mycartridge.crt

mycartridge.crt stands for the crt file, that you want to convert.

The second step is to generate a *.bin file from the *.crt. The *.bin file can be used to program EPROMs.

cartconv -i mycartridge.crt -o mycartridge.bin

### 4.2. Example I

C:\cartconv>cartconv -f deadtest.CRT
CRT Version: 1.0
Name: C64DEADTESTREV718220
Hardware ID: 0 (Generic Cartridge)
Mode: exrom: 1 game: 0 (ultimax)

offset sig type bank start size chunklen $000040 CHIP ROM #000 $e000 $2000 $2010

total banks: 1 size: $002000

The important information is colored red in the above example.

First of all, it has to be a generic cartridge (Hardware ID 0). Many (game or special) cartridges have additional hardware build it, that is required for proper operation. That might be one of manifold automatic bank switching circuits, a freezer circuit like in the Final Cartridge etc.

Drafted by Sven Petersen | Page 6 of 10 | Doc.-No.: 121-6-01-01.5

Next, EXROM has to be 1 (HIGH) and GAME has to be 0 (LOW) Þ DIP Switch 1=ON, 2=OFF.

The ultimax mode is mentioned here, too. The start address is $e000 (0xE000). Referring to Table 1, J6 has to be set to ROMH . The size is $2000 (which is hexadecimal for 8k). Hence jumper J5 is set to “switch”. It is assumed, that the binary is programmed to the first 8k of the EPROM, so the address lines A15, A14 and A13 are L, L, L Þ the switches 3-5 are ON.

Item | cartconv | Setting
GAME | 0 (= LOW) | SW1-1 = ON
EXROM | 1 (= HIGH) | SW1-2 = OFF
size | $2000 (=8k cartridge) | A13 (J5) = “Switch”
start | $E000 | OE (J6) = ROMH
EPROM offset | $2000 | A15…13 = LLL Þ SW1-3 = ON SW1-4 = ON SW1-5 = ON

Now the deadtest.bin file can be generated:

C:\cartconv>cartconv -i deadtest.CRT -o deadtest.bin
Input file : deadtest.CRT
Output file : deadtest.bin
Conversion from Generic Cartridge .crt to binary format successful.

### 4.3. Example II

C:\cartconv>cartconv -f diag04.crt
CRT Version: 1.0
Name: 586220PLUS_0.4
Hardware ID: 0 (Generic Cartridge)
Mode: exrom: 0 game: 1 (8k Game)
offset | sig | type | bank start size | chunklen
$000040 CHIP ROM | #000 $8000 $2000 $2010
total banks: 1 size: $002000

Here, the Hardware ID is 0 (Generic Cartridge) again. The Versa64Cart is suitable for running the software. Now, it is assumed, that the first 8k are already in use and the binary should be programmed to the second 8k slot of the EPROM.

Item | cartconv | Setting
GAME | 1 (= HIGH) | SW1-1 = OFF
EXROM | 0 (= LOW) | SW1-2 = ON
size | $2000 (=8k cartridge) | A13 (J5) = “Switch”
start | $8000 | OE (J6) = ROML
EPROM offset | $2000 | A15…13 = LLH Þ SW1-3 = ON SW1-4 = ON SW1-5 = OFF

Drafted by Sven Petersen | Page 7 of 10 | Doc.-No.: 121-6-01-01.5

The binary conversion is exactly the same like in Example I.

### 4.4. Example III

C:\cartconv>cartconv -f neutron.crt CRT Version: 1.0
Name: NEUTRON
Hardware ID: 0 (Generic Cartridge)
Mode: exrom: 0 game: 0 (16k Game)
offset | sig | type | bank start size | chunklen
$000040 CHIP ROM | #000 $8000 $4000 $4010
total banks: 1 size: $004000

Again, it is assumed, the binaries should be programmed to the first 16k of the EPROM.

Item | cartconv | Setting
GAME | 0 (= LOW) | SW1-1 = ON
EXROM | 0 (= LOW) | SW1-2 = ON
size | $4000 (=16k cartridge) | A13 (J5) = “16k” OE (J6) = “16k”
start | $8000 | Not relevant in 16k mode
EPROM offset | $0000 | A15…13 = LLL Þ SW1-3 = ON SW1-4 = ON SW1-5 = ON

The binary conversion is exactly the same like in Example I.

### 4.5. Example IV

C:\cartconv>cartconv -f batman.crt
CRT Version: 1.0
Name: batman
Hardware ID: 5 (Ocean)
Mode: exrom: 0 game: 1 (8k Game)
Warning: game in crt image set incorrectly.
offset | sig | type | bank start size | chunklen
$000040 CHIP ROM | #000 $8000 $2000 $2010
$002050 CHIP ROM | #001 $8000 $2000 $2010
[…]
$01e130 CHIP ROM #015 $8000 $2000 $2010
total banks: 16 size: $020000

Here, the hardware ID is not 0 (generic). The Versa64Cart is not suitable for this software. The size is $20000, which is 128kB, more than what fits into the memory space of the C64. This kind of software requires a cartridge with a certain automatic bank switching circuit, in this case the Ocean cartridge type and a 27C010 (128kx8bit) EPROM is required.

Drafted by Sven Petersen | Page 8 of 10 | Doc.-No.: 121-6-01-01.5

## 5. EPROMs

Four different types/sizes of EPROMs can be used with the Versa64Cart, not all settings make sense with them. Their pin out is shown in Table 5.

The effect of the settings and the recommended configurations are shown in Table 6.

27C64
| 27C128
| 27C256
| 27C512
| SOCKET
Vpp | Vpp | Vpp | A15 | 1 | A15 | VCC | 28 | VCC | VCC | VCC | VCC
A12 | A12 | A12 | A12 | 2 | A12 | A14 | 27 | A14 | A14 | /PGM | /PGM
A7 | A7 | A7 | A7 | 3 | A7 | A13 | 26 | A13 | A13 | A13 | n.c.
A6 | A6 | A6 | A6 | 4 | A6 | A8 | 25 | A8 | A8 | A8 | A8
A5 | A5 | A5 | A5 | 5 | A5 | A9 | 24 | A9 | A9 | A9 | A9
A4 | A4 | A4 | A4 | 6 | A4 | A11 | 23 | A11 | A11 | A11 | A11
A3 | A3 | A3 | A3 | 7 | A3 | /OE | 22 | /G/Vpp | /G | /G | /G
A2 | A2 | A2 | A2 | 8 | A2 | A10 | 21 | A10 | A10 | A10 | A10
A1 | A1 | A1 | A1 | 9 | A1 | GND | 20 | /E | /E | /E | /E
A0 | A0 | A0 | A0 | 10 | A0 | D7 | 19 | D7 | D7 | D7 | D7
D0 | D0 | D0 | D0 | 11 | D0 | D6 | 18 | D6 | D6 | D6 | D6
D1 | D1 | D1 | D1 | 12 | D1 | D5 | 17 | D5 | D5 | D5 | D5
D2 | D2 | D2 | D2 | 13 | D2 | D4 | 16 | D4 | D4 | D4 | D4
GND | GND | GND | GND | 14 | GND | D3 | 15 | D3 | D3 | D3 | D3
Table 5: EPROM pin compatibility
EPROM | Size | A15 | A14 | A13 | 16k
27C512 | 64kx8 | yes | yes | yes | yes
27C256 | 32kx8 | HIGH | yes | yes | yes
27C128 | 16kx8 | HIGH | HIGH | yes | yes
27C64 | 8kx8 | HIGH | HIGH | HIGH | no
Table 6: Settings per EPROM type

In case Vpp is located at a dedicated pin (pin 1), A15 has no effect anymore. A HIGH level is recommended (switch is off) . The /PGM Pin should be set HIGH. The n.c. (not connected) pin should be HIGH (with pull-up) or open. For an 8k EPROM, the 16k setting makes no sense.

## 6. Using parallel EEPROMs

There are parallel EPROMs, which fit into the EPROM sockets. They do not require erasing with a UV eraser, like EPROMs, but the price is higher.

Since they can be written, which is controlled by the WE signal, but the Super Expander II cartridge is lacking of this functionality, this signal has to be HIGH (inactive). The 28C256 has the A14 signal connected to Pin 1, which is A15 of the EEPROM socket. This is no problem, but it has to be kept in mind, that the jumper for A15 has effect on the bank select A14 of the EPROM.

Drafted by Sven Petersen | Page 9 of 10 | Doc.-No.: 121-6-01-01.5

28C64
| 28C256
| SOCKET
n.c. | A14 | 1 | A15 | VCC | 28 | VCC | VCC
A12 | A12 | 2 | A12 | A14 | 27 | /WE | /WE
A7 | A7 | 3 | A7 | A13 | 26 | A13 | n.c
A6 | A6 | 4 | A6 | A8 | 25 | A8 | A8
A5 | A5 | 5 | A5 | A9 | 24 | A9 | A9
A4 | A4 | 6 | A4 | A11 | 23 | A11 | A11
A3 | A3 | 7 | A3 | /OE | 22 | /G/Vpp | /OE
A2 | A2 | 8 | A2 | A10 | 21 | A10 | A10
A1 | A1 | 9 | A1 | GND | 20 | /E | /CE
A0 | A0 | 10 | A0 | D7 | 19 | D7 | D7
D0 | D0 | 11 | D0 | D6 | 18 | D6 | D6
D1 | D1 | 12 | D1 | D5 | 17 | D5 | D5
D2 | D2 | 13 | D2 | D4 | 16 | D4 | D4
GND | GND | 14 | GND | D3 | 15 | D3 | D3
Table 7: EEPROM pin compatibility
EEPROM | Size | A15 | A14 | A13
28C256 | 32kx8 | =A14 | OPEN | yes
28C64 | 8kx8 | OPEN | OPEN | OPEN
Table 8: Settings per EEPROM type

## 7. Startup and Trouble shooting

Before you insert the Versa64Cart into the expansion port of the C64, you should make sure, that there are no fatal failures on it. In the worst case, it will produce a short circuit.

- Check the solder joints on the solder side
- Check the orientation of the socket. The notch is at the side, where the capacitor is
- In case you have used the solder bridges to configure the address, check according to the warning in chapter 2.4 or measure the resistance between pin 1 and 2 (that is GND and +5V) of the edge connector (without an EPROM inserted). It must not be less than about 3kΩ.
- After inserting the EPROM, check if the notch is at the same side like the notch of the socket. Check all pins are properly seated in the socket and not bent inwards or outwards.

After all these points are correct, nothing really bad can happen to your C64 anymore. If you get a black screen or a normal startup display with less than 38911 Basic Bytes free, you might have a configuration problem.

- Did you program the EPROM with a proper *.bin and not with the *.crt file? CRT files are not suitable to program an EPROM. Refer to chapter 4.
- Did you set the configuration bits correctly? ON means LOW
- Did you select the required OE (J6)?
- Did you jumper A13 (J5) as required?
- In case it is a 16k cartridge: Are R1, D1 and D2 placed?

Drafted by Sven Petersen | Page 10 of 10 | Doc.-No.: 121-6-01-01.5

## 8. Revision History

### 8.1. Rev. 1.1 Þ Rev. 1.2

- Schematic and layout were redrawn in Eagle (v 9.2)
- All solder bridges (jumpers) are located on the component side now (the footprint of the jumpers includes the solder bridge option)

### - A13…A15 can be configured by solder bridges now - No test points for A13…A15 anymore

- The jumpers are moved to the outer edge for easier access
- J5 for the configuration of A13 is a 3-pin jumper now
- A reset switch is added
- A configuration table is added on the solder side

### 8.2. Rev. 1.2 Þ Rev. 1.3

Some issues with cartridge cases were fixed.

- The diodes D1 & D2 and R1 were moved north by 4.93mm
- D1&D2 moved east by 4.6mm, R1 by 2.54mm
- IC1&C1 moved west by 1.59mm

### 8.3. Rev. 1.3 Þ Rev. 1.4

- The width of the contact pads of the expansion port was reduced to 1.5mm and the whole area is free of solder stop mask.

### 8.4. Rev. 1.4 Þ Rev. 1.5

- The DIP-Switch SW1 can be replaced with a jumper










Versa64Cart_FunD_v1_5.docx | | 07.05.2020 12:36
Drafted by Sven Petersen | Page 1 of 1 | Doc.-No.: 121-6-02-01.5

### Versa64Cart v1.5

### Functional Description

J1 are the contacts, that fit into the Commodore C64 expansion port. The pin numbering is identical to those of the C64. IC1 is the EPROM, which can be socketed or not. C1 is the blocking capacitor, that should help to keep the noise from the supply voltage out of the IC.

The configuration is achieved with the DIP-Switch SW1, jumper J5 and jumper J6. SW1-1 and SW1-2 set the signals GAME and EXROM . These signalize the C64 the mode of the cartridge. The switches SW1-3 to SW3-5 are responsible for the (manual) bank select: The configure the three most sufficient address bit of the EPROM, since those are not asserted by the C64, which only addresses 8kB blocks. The Dip Switch can be replaced with a jumper (2x5).

For 16kB cartridges, a further address bit (A13) is required. Since this kind of cartridge uses both chip selects ( ROML and ROMH ) the signal ROML is used for this purpose. It will be low, while the lower 8kB are addressed and HIGH, while the upper 8kB are addressed.

The 16k cartridge configuration requires to combine ROML and ROMH to one chip select signal. This function is provided by the wired AND circuit D1, D2 and R1. R1 is pulling the RH&RL signal HIGH. In case one of those signals is low, the RH&RL is driven LOW.

The required chip select signal can be selected with J6.

In 8k mode, the address bit A13 is set by the DIP-switch. Jumper J5 has to be set to the
“Switch” position.

While GAME and EXROM utilize the pull-up resistors inside the C64, the address signals A13 to A15 require Pull-Up resistors on the cartridge board (R2-R4). There are solder bridges on the component side if the Versa64Cart, that can be used alternatively to the DIP-Switch to pull each signal low. In case the Pull-Up resistors R2-R4 are not populated, additional solder bridges can be used to set A13 – A15 to a HIGH level (only those, that are set to a HIGH level). It is obvious, that closing the HIGH bridge and the LOW bridge of a signal at the same time produces a short circuit.

SW2 is the reset switch. A pull-up resistor on the C64 mainboard is utilized here.

Versa64Cart_Test_v1_5.docx | | 07.05.2020 12:34
Drafted by Sven Petersen | Page 1 of 3 | Doc.-No.: 121-6-03-01.5

### Versa64Cart v1.5

### Testing

## Test Description

The test was executed with a Versa64Cart v1.2 (the differences to v1.3, v1.4 and v1.5are not functional), a C64G (Mainboard ASSY 250469) and an EPROM type ST micro M27C512 10F1. The programming of the EPROM was done with a TL866II Plus programmer.

The following binaries were loaded into the program memory of the programmer, programed to the EPROM and verified “ok”:

Binary | Binary # | Start Address | End Address
Neutron.bin | 1 | 0x0000 | 0x3FFF
Deadtest.bin | 2 | 0x4000 | 0x5FFF
586220plus_0_4.bin | 3 | 0x6000 | 0x7FFF
LalaPrologue.bin | 4 | 0x8000 | 0xBFFF

The EPROM was inserted into the socket of Versa64Cart, which was then configured, inserted into the C64, the C64 was switched on and the selected binary was run.

## Test Execution

Binary # | A15..13 | GAME | EXROM | J6 OE
J5 A13 Observation | Testing
1 | LLL | L | L | 16k | 16k | working | ok
2 | LHL | L | H | ROMH | Switch | working | ok
3 | LHH | H | L | ROML | Switch | working | ok
4 | HLL | L | L | 16k | 16k | working | ok
Test | Observation | Testing
Does the Cart fit into the slot? | yes | ok
Does the Cart move inside the slot? | The Cart moves 0.9mm from left to right in total. The contacts of the cartridge connector do not leave the contact pad. | ok
Comparison of measures v1.2 vs. v1.1 | Both PCBs have the same dimensions. The mounting holes are aligned. The port contacts are aligned, the contacts of v1.2 are wider. | ok
Reset button | Binary #1 can be restarted by pushing the reset button. Some software (e.g. LalaPrologue.bin) does not reset well after pressing the RESET button. It depends on that software, not on the memory bank. | ok
Running cartridge with a breakout board, which adds 90mm to the bus | Binary #1 is running Þ The bus length is not critical | ok


Versa64Cart_Test_v1_5.docx | | 07.05.2020 12:34
Drafted by Sven Petersen | Page 2 of 3 | Doc.-No.: 121-6-03-01.5

The critical signal is the OE pulse for the EPROM when the 16k-mode is selected. It can either be too wide or the low level is above 0.7V (the upper margin for a TTL low level).

Figure 1: The /OE pulse (low level = 520mV)

Figure 2: /OE pulse (pulse width = 480ns)

Versa64Cart_Test_v1_5.docx | | 07.05.2020 12:34
Drafted by Sven Petersen | Page 3 of 3 | Doc.-No.: 121-6-03-01.5
Test | Observation | Testing
Low level of the 16k- OE pulse below 0.7V | The low level is 520mV | ok
Pulse width of the 16k-OE pulse less than 500ns (?) | The pulse width is 480ns | ok (?)
Test | Observation | Testing
Neutron.bin & LalaPrologue.bin were programmed into a 27C256, A15 was set HIGH | Both games started and played properly. | ok
LalaPrologue.bin was programmed into a 27C128A, A15 & A14 were set HIGH | Game started and played properly. | ok
1541diagcart.bin was programmed into a 27C164A, A13..A15:HHH, GAME : H, EXROM : L, OE : ROML | Software started and worked properly | ok

## Conclusion

### - All extra address lines (A15 … A13) can be asserted

- GAME can be configured properly
- EXROM can be configured properly
- ROML works as a chip select
- ROMH works as a chip select
- The 16k OE works properly, the timing cannot be proved ok, due to a lack of

information.
- All binaries are running (16k, 8k Game, 8k Exrom)
- EPROM types tested: ST M27C512, M27C256B, M27C128A, M27C64A

The Versa64Cart is fully functional.

Pos. Qty Value Footprint Ref.-No. Comment

1 1 121-2-01-01.5 2 Layer PCB Rev. 1.5 2 layer, Cu 35µ, HASL, 58mm x 48.9mm, 1.6mm FR4

2 1 100n C-2,5 C1 ceramic capacitor, pitch 2.54

3 4 10k R-10 R1, R2, R3, R4 resistors
4 2 1N4148 DO-35 D1, D2 diodes

5 1 27C512 DIL28 IC1 EPROM. Also possible: 27C256, 27C128 and 27C64

6 1 socket DIL28 (IC1) IC socket for the EPROM

7 1 Pinheader 3x1 pin 1x3p J5 2.54mm pitch (0.1") pinheader (option: 90°)

8 1 Pinheader 3x2 pin 2x3p J6 2.54mm pitch (0.1") pinheader (option: 90°)

9 2 Jumper 2.54mm 2.54mm (J5), (J6) Jumper to be placed on J5 and J6

10 1 DIPSW-05V DIPSW-05V SW1 Standard DIP-Switch with 5 switches (switch side facing up)

The DIP-Switch can be replaced with a normal 2x5 jumper.

11 1 JTP-1130 JTP-1130 SW2 Standard 6x6mm tact switch, e.g. Namae JTP-1130 or any

other

### Rev. 1.2 → 1.3

Pos 1 new board revision

### Rev. 1.3 → 1.4

Pos 1 new board revision

### Rev. 1.4 → 1.5

Pos 1 new board revision

## Versa64Cart Rev. 1.5

## Bill of Material Rev. 1.50

Versa64Cart_BOM_v1_50.xlsx

Drafted by Sven Petersen Page 1 of 1

07.05.2020 12:50
Doc.No.: 121-5-01-01.50

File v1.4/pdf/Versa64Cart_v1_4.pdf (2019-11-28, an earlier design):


# Project Documentation

# BWACK’s Versa64Cart

## Project number: 121

## Revision: 1.4

## Date: 25.06.2019

Versa64Cart_ModD_v1_4a.docx | | 26.11.2019 18:17
Drafted by Sven Petersen | Page 1 of 14 | Doc.-No.: 121-6-01-01.4a

# Versa64Cart v1.4

# Module Description

Content

# 1. Introduction


Drafted by Sven Petersen | Page 2 of 14 | Doc.-No.: 121-6-01-01.4a

The Versa64Cart is a generic EPROM cartridge for the Commodore C64 and C128. It can be configured as 8k, 16k, 8k ultimax or 16k ultimax cartridge. Further on, the most sufficient address bits of the EPROM can be set by a DIP-switch which offers a manual bank switching for multi game/multi ROM cart option.

Figure 1: Both sides of the Versa64Cart rev 1.2

The Versa64Cart is not suitable to run a Kernal or software, which require bank switching by that software (e.g. games > 16k).

Figure 2: Versa64Cart - placement and dimensions

Drafted by Sven Petersen | Page 3 of 14 | Doc.-No.: 121-6-01-01.4a

## 2. Configuration

### 2.1. Explanation

The extension cartridges signalize their configuration with two flags. Those are GAME and

EXROM . For addressing the EPROM, the C64 offers two chip-select signals for an 8kB address

space, which are ROML and ROMH . The chip-select signals are required to locate the EPROM

content within the address space of the C64. It is possible to use either ROML , ROMH or combining both to get a 16kB address space in total.

Mode | EXROM | GAME | OE

Address space

8k | LOW | HIGH | ROML | 0x8000 – 0x9FFF
8k ultimax | HIGH | LOW | ROMH | 0xE000 – 0xFFFF
16k | LOW | LOW | ROML & ROMH = “16k” | 0x8000 – 0xBFFF
16k ultimax | HIGH | LOW | ROML & ROMH = “16k” | 0x8000 – 0x9FFF + 0xE000 – 0xFFFF

Table 1: Cartridge configuration
In the “ultimax” modes, the Kernal ROM (0xE000 – 0xFFFF) is replaced by the content of the EPROM of the Versa64Cart. The Reset vector is located at 0xFFFC and 0xFFFD. This is a guidepost for the microprocessor, which shows where to start the execution after the processor was powered up (or received a RESET pulse). This way, the software in the EPROM will completely take control.

In EXROM mode, the C64 Kernal (the one on the mainboard) will check the memory locations
0x8004-0x8008 for the “cartridge signature” CBM80 (PETSCII 0xC3, 0xC2, 0xCD, 0x38, 0x30). If
this sequence is found, the execution will follow the cartridge cold start vector located at the first two
memory addresses of the EPROM (0x8000 and 0x8001 in the C64’s address space).

### 2.2. Addresses

This document mentions different sorts of addresses. All are expressed as hexadecimal numbers. This
is indicated by a 0x… in front of the number (like it is common in the programming language C). In
the Commodore world, a $... in front of the number indicates the hexadecimal format.

The addresses shown in Table 1 are absolute addresses in the memory space of the C64. The addresses shown in Table 2 and Table 3 are EPROM offset addresses. Both must no be confused. Depending on the cartridge mode, the selected memory bank is mapped to the addresses shown in Table 1 (by the PLA, the main logic chip of the C64).

### 2.3. Jumper & DIP-Switch Settings

The DIP-Switch SW1 configures the cartridge mode and the three most sufficient address bit of the EPROM (the “bank switching”). Annotation: ON position connects the signal to ground (=LOW).

The jumper J6 ( OE ) sets the chip select signal for the EPROM. It can be ROML , ROMH or
“16k”(this is a diode logic AND of ROML and ROMH ).

Drafted by Sven Petersen | Page 4 of 14 | Doc.-No.: 121-6-01-01.4a

The jumper J5 (A13) can be set to “Switch” or “16k”. “Switch” means, that A13 is set by the DIP-Switch, “16k” means, that A13 is controlled by the ROML signal.

A 16k cartridge requires both jumpers (J5 and J6) set to “16k”.

For the required settings refer to Table 1.

### 2.4. Bank Switching

The EPROM offers more memory (27C512 = 64kB), than it is required for a generic 8k or 16k cartridge. On account of this an EPROM can keep the content of several cartridges. The DIP-Switch SW1 (3, 4, 5 = A15, A14 and A13) selects, which of these cartridges is selected. In 16k mode, the setting of A13 is ignored.

DIP-Switch | Address Bits | EPROM Address
3 | 4 | 5 | A15 | A14 | A13 | (Offset)
ON | ON | ON | L | L | L | 0x0000 – 0x1FFF
ON | ON | OFF | L | L | H | 0x2000 – 0x3FFF
ON | OFF | ON | L | H | L | 0x4000 – 0x5FFF
ON | OFF | OFF | L | H | H | 0x6000 – 0x7FFF
OFF | ON | ON | H | L | L | 0x8000 – 0x9FFF
OFF | ON | OFF | H | L | H | 0xA000 – 0xBFFF
OFF | OFF | ON | H | H | L | 0xC000 – 0xDFFF
OFF | OFF | OFF | H | H | H | 0xE000 – 0xFFFF
Table 2: 8k cartridges memory banks
DIP-Switch | Address Bits | EPROM Address
3 | 4 | 5 | A15 | A14 | A13 | (Offset)
ON | ON | X | L | L | X | 0x0000 – 0x3FFF
ON | OFF | X | L | H | X | 0x4000 – 0x7FFF
OFF | ON | X | H | L | X | 0x8000 – 0xBFFF
OFF | OFF | X | H | H | X | 0xC000 – 0xFFFF
Table 3: 16k cartridges memory banks

The C64 address must not be confused with the EPROM Address offset.

### 2.5. Solder Bridges

Instead of setting jumpers and the DIP-Switch, solder bridges can be utilized to configure the Versa64Cart. This is an option, in case the configuration of the Versa64Cart is not prone to be
changed. Solder bridges are used to “hard wire” the configuration.
Signal | HIGH | LOW
GAME | JP4 = open | JP4 = closed
EXROM | JP5 = open | JP5 = closed
A15 | JP8 = open, (JP9 = closed) | JP8 = closed, (JP9 = open)
A14 | JP10 = open, (JP11 = closed) | JP10 = closed, (JP11 = open)
A13 | JP12 = open, (JP14 = closed) | JP12 = closed, (JP14 = open)
Table 4: Configuration with solder bridges

The jumpers in brackets ( ) (JP9, JP11 and J14) are only required, in case the pull-up resistors R2, R3 and R4 are not populated. Never (!!!!) close both jumpers of one address signal. It cannot be LOW and HIGH at the same time, this will produce a SHORT CIRCUIT!!!!

Drafted by Sven Petersen | Page 5 of 14 | Doc.-No.: 121-6-01-01.4a

The footprints of the jumpers J5 and J6 are designed to be solder bridged, when not populated.

## 3. Assembly of the Versa64Cart

The Versa64Cart can work with a minimum of components when being configured with solder bridges. Just the EPROM and a 100nF capacitor is required.

- The reset switch is nice to have, but it is just an option.
- The DIP-switch can be replaced by configuring the solder bridges JP4, 5, 8, 10 and 12.
- The pull-up resistors (R2-4) can be omitted and JP9, 11, 14 can be utilized to set a HIGH level on A15 … A13 (BE CAREFUL, see warning above!). If you are not sure, keep the pull up resistors.
- J5 and J6 can be hard wired with solder bridges.
- R1, D1 and D2 are only required in 16k modes.
- The EPROM can be soldered, a socket is not necessary

Soldering the EPROM can be required if a shallow cartridge case is used. A socket might add too much height. In this case, it is advised to test the EPROM with a Versa64Cart with a socket before soldering.

## 4. Retrieving the binary and the settings from a CRT file

### 4.1. VICE cartconv

The CRT file format is created to emulate cartridges with VICE or devices like the Ultimate II+ etc. It should not be programmed into an EPROM; this will not work.

Instead, the binary has to be retrieved from the CRT file. The binary is a file that can be used for programming EPROMs. Also, it is possible to find out the required settings for GAME and

EXROM .

The utility that is used here is CARTCONV, which is a command line toot that comes with VICE (C64 emulator). For the examples in this chapter , CARTCONV and the cartridge files are copied to the same directory. To start, enter cmd into the search box on the task bar of Windows (Press Windows-Key, write cmd, press ENTER).

First the CRT information is required. Enter the following command

cartconv -f mycartridge.crt

mycartridge.crt stands for the crt file, that you want to convert.

The second step is to generate a *.bin file from the *.crt. The *.bin file can be used to program EPROMs.

cartconv -i mycartridge.crt -o mycartridge.bin

### 4.2. Example I - deadtest.crt (Mode 8k ultimax)

In this first example we will look at the output of cartconv and use it to make a dead test cartridge step by step. The important information is colored red.

### 1. List the CRT information:

C:\cartconv>cartconv -f deadtest.CRT CRT Version: 1.0
Name: C64DEADTESTREV718220

Drafted by Sven Petersen | Page 6 of 14 | Doc.-No.: 121-6-01-01.4a

Hardware ID: 0 (Generic Cartridge)
Mode: exrom: 1 game: 0 (ultimax)
offset | sig | type | bank start size | chunklen
$000040 CHIP ROM | #000 $e000 $2000 $2010

total banks: 1 size: $002000

### 2. Check the hardware ID. It must be 0. Many (game or special) cartridges require special

circuitry. The Final Cartridge and Super Zaxxon are examples of that and will not work with the Versa64Cart.

### 3. Check the Mode. From the mode we know how to configure the jumpers on the board. It

shows that exrom=1, game=0 and the mode is ultimax.
4. Check the size. Here it is $2000, meaning 8k.

With the information above we see that

- $2000: we need an 27C64 8k EPROM. If you select a larger ROM, tie A13-A15 to GND. (SW1-3, SW1-4 and SW1-5 to ON) to ensure that the lowest part of the rom is addressed.
- exrom: 1 game: 0 (ultimax): set SW1-1 to ON and SW1-2 to OFF.

Note: A switch in the OFF position means HIGH or 1. Nicely confusing.

EXROM has to be 1 (HIGH) and GAME has to be 0 (LOW) Þ DIP Switch 1=ON, 2=OFF. The

ultimax mode is mentioned here, too. The start address is $e000 (0xE000). Referring to Table 1, J6 has to be set to ROMH . The size is $2000 (which is hexadecimal for 8k). Hence jumper J5 is set to “switch”. It is assumed, that the binary is programmed to the first 8k of the EPROM, so the address lines A15, A14 and A13 are L, L, L Þ the switches 3-5 are ON.

Item | cartconv | Setting
GAME | 0 (= LOW) | SW1-1 = ON
EXROM | 1 (= HIGH) | SW1-2 = OFF
size | $2000 (=8k cartridge) | A13 (J5) = “Switch”
start | $E000 | OE (J6) = ROMH
EPROM offset | $2000 | A15…13 = LLL Þ SW1-3 = ON SW1-4 = ON SW1-5 = ON

Now the deadtest.bin file can be generated:

C:\cartconv>cartconv -i deadtest.CRT -o deadtest.bin
Input file : deadtest.CRT
Output file : deadtest.bin
Conversion from Generic Cartridge .crt to binary format successful.

### 4.3. Example II - diag04.crt (Mode 8k game)

C:\cartconv>cartconv -f diag04.crt
CRT Version: 1.0

Drafted by Sven Petersen | Page 7 of 14 | Doc.-No.: 121-6-01-01.4a

Name: 586220PLUS_0.4
Hardware ID: 0 (Generic Cartridge)
Mode: exrom: 0 game: 1 (8k Game)
offset | sig | type | bank start size | chunklen
$000040 CHIP ROM | #000 $8000 $2000 $2010
total banks: 1 size: $002000

Here, the Hardware ID is 0 (Generic Cartridge) again. The Versa64Cart is suitable for running the software. Now, it is assumed, that the first 8k are already in use and the binary should be programmed to the second 8k slot of the EPROM.

Item | cartconv | Setting
GAME | 1 (= HIGH) | SW1-1 = OFF
EXROM | 0 (= LOW) | SW1-2 = ON
size | $2000 (=8k cartridge) | A13 (J5) = “Switch”
start | $8000 | OE (J6) = ROML
EPROM offset | $2000 | A15…13 = LLH Þ SW1-3 = ON SW1-4 = ON SW1-5 = OFF

The binary conversion is exactly the same like in Example I.

### 4.4. Example III - neutron.crt (Mode 16k game)

C:\cartconv>cartconv -f neutron.crt CRT Version: 1.0
Name: NEUTRON
Hardware ID: 0 (Generic Cartridge)
Mode: exrom: 0 game: 0 (16k Game)
offset | sig | type | bank start size | chunklen
$000040 CHIP ROM | #000 $8000 $4000 $4010
total banks: 1 size: $004000

Again, it is assumed, the binaries should be programmed to the first 16k of the EPROM.

Item | cartconv | Setting
GAME | 0 (= LOK) | SW1-1 = OFF
EXROM | 0 (= LOW) | SW1-2 = ON
size | $4000 (=16k cartridge) | A13 (J5) = “16k” OE (J6) = “16k”
start | $8000 | Not relevant in 16k mode
EPROM offset | $0000 | A15…13 = LLL Þ SW1-3 = ON SW1-4 = ON SW1-5 = ON

Drafted by Sven Petersen | Page 8 of 14 | Doc.-No.: 121-6-01-01.4a

The binary conversion is exactly the same like in Example I.
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

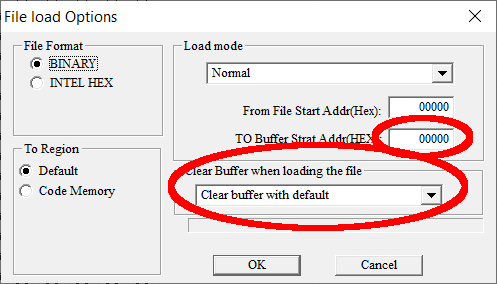
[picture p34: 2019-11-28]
v1.6/pictures/TL866_first.png

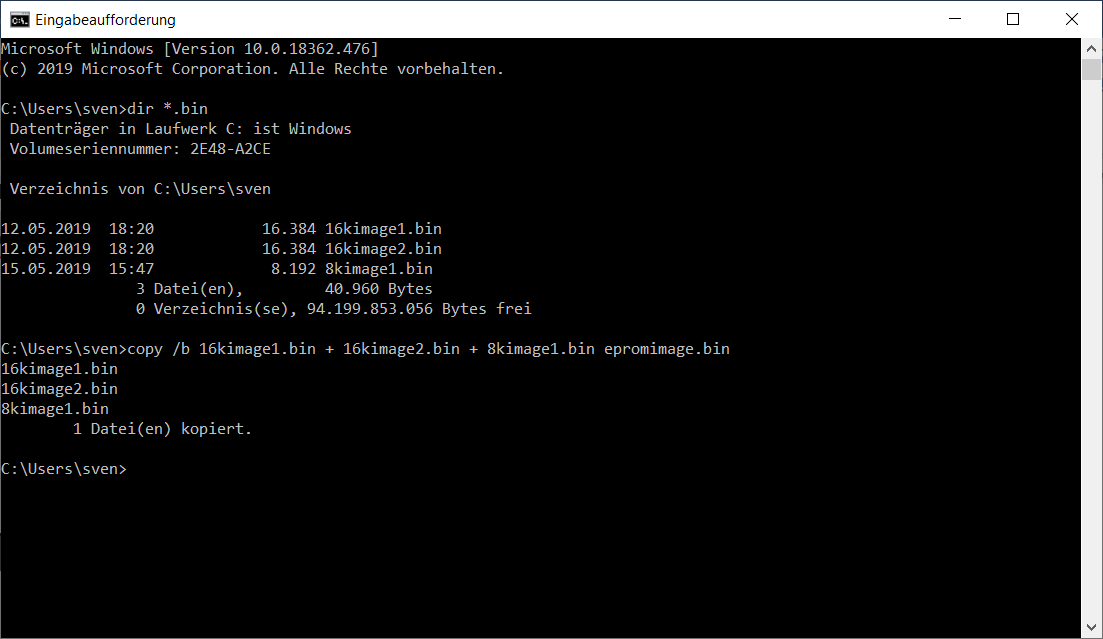
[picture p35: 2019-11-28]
v1.6/pictures/command_interface.png

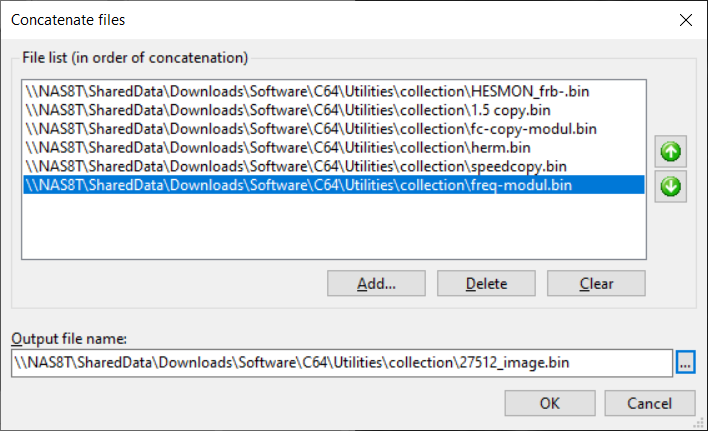
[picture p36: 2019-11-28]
v1.6/pictures/HxD_concatenating.png

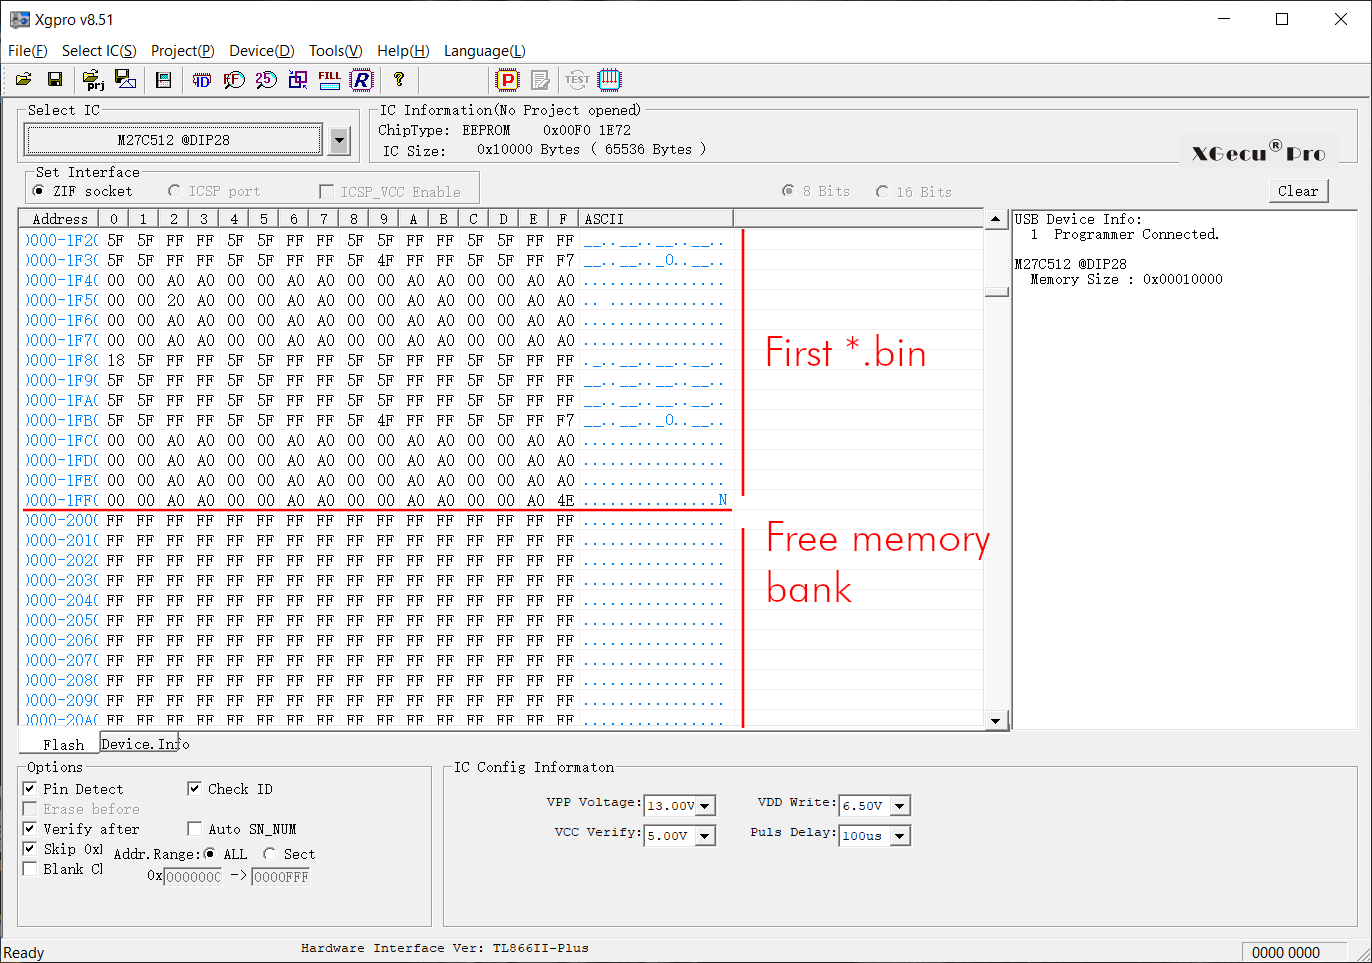
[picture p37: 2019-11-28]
v1.6/pictures/TL866_buffer.png

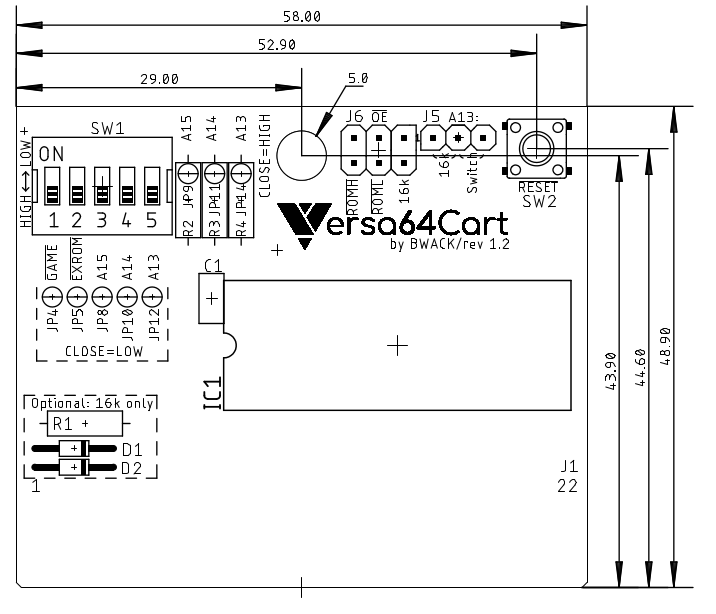
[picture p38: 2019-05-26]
v1.2 (eagle)/pictures/Versa64Cart_v1_2.png

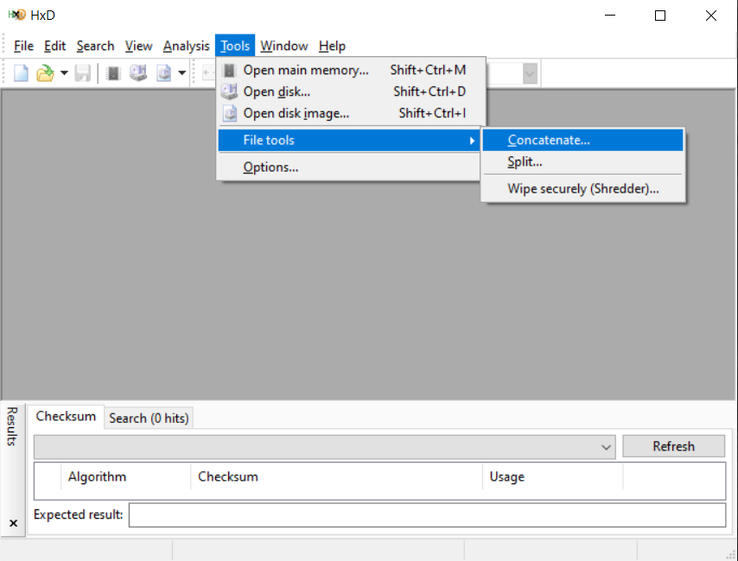
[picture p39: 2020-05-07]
v1.6/pictures/HxD_concatenate.png

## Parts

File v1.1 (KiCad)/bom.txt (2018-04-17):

Ref   - Elfa no.   -
 
C1    -            - 100nF Capacitor 3.8 x 2.6 x 2.5mm
D1,D2 - 300-92-928 - 1N4148 or BAT42 Schottky Diodes or similar
R1-R4 - 160-95-467 - 22k Resistors Throughhole Axial L6.4 x D2.5 x P7.62mm
J5    - 300-24-527 - Pin Header Straight 2x2 pins 2.54mm pitch
J5    - 300-24-524 - Pin Header Straight 2x3 pins 2.54mm pitch
SW1   - 135-39-684 - DIP switch 5 way. W7.62mm slide
U1    -            - 27128, 27256 or 27512 EPROM DIP-28 W15.24mm

2x Jumpers: Elfadistrelec: 300-24-773

Versa64Cart PCB

online bom created by sajattack:
https://octopart.com/bom-tool/bEfXBXH2

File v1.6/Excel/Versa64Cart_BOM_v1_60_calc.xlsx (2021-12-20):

Versa64Cart Rev. 1.5
Bill of Material Rev. 1.50
Pos. | Qty | Value | €/ea | € | Comment
1 | 1 | 121-2-01-01.5 | 1.00 € | 1.00 € | 2 layer, Cu 35µ, HASL, 58mm x 48.9mm, 1.6mm FR4
2 | 1 | 100n | 0.10 € | 0.10 € | ceramic capacitor, pitch 2.54
3 | 4 | 10k | 0.08 € | 0.32 € | resistors
4 | 2 | 1N4148 | 0.02 € | 0.04 € | diodes
5 | 1 | 27C512 | 0.00 € | 0.00 € | EPROM. Also possible: 27C256, 27C128 and 27C64
6 | 1 | socket | 0.42 € | 0.42 € | IC socket for the EPROM
7 | 1 | Pinheader 3x1 pin | 0.07 € | 0.07 € | 2.54mm pitch (0.1") pinheader (option: 90°)
8 | 1 | Pinheader 3x2 pin | 0.14 € | 0.14 € | 2.54mm pitch (0.1") pinheader (option: 90°)
9 | 2 | Jumper 2.54mm | 0.02 € | 0.04 € | Jumper to be placed on J5 and J6
10 | 1 | DIPSW-05V | 0.22 € | 0.22 € | Standard DIP-Switch with 5 switches (switch side facing up) The DIP-Switch can be replaced with a normal 2x5 jumper.
11 | 1 | JTP-1130 | 0.15 € | 0.15 € | Standard 6x6mm tact switch, e.g. Namae JTP-1130 or any other
 |  |  | Total | 2.50 €

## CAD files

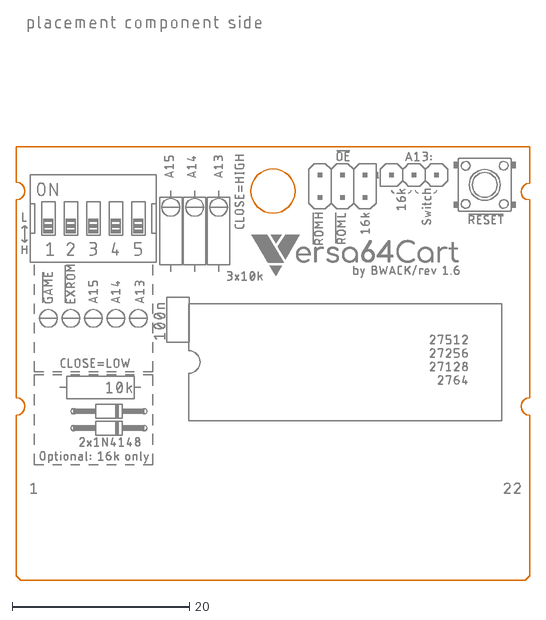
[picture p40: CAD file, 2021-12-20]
v1.6/dxf/Versa64Cart_v1_6.dxf
58.0 x 63.7

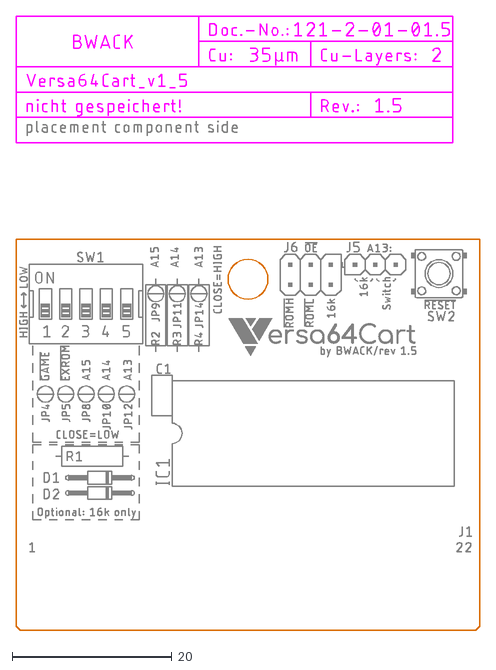
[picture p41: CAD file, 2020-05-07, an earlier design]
v1.5/dxf/Versa64Cart_v1_5.dxf
58.0 x 76.8

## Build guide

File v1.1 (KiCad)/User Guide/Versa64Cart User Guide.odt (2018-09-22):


User Guide

# Introduction


Versa64Cart is designed to be a modern easy-to-use cartridge development board for Commodore 64 and Commodore 128 hobbyists and hackers. The versatile design of the PCB allows for flexible implementation of various cartridge types. Whether it’s a simple cartridge backup of an 8k game or a

switchable multi-program diagnostic cartridge, Versa64Cart has you covered.

# Overview

- Supported EPROMS: 27C64 (8k), 27C128 (16k), 27C256 (32k), 27C512 (64k)
- Ability to access multiple program images by using optional on-board DIP switches(*)
- Rapid low-cost production of clean, single image cartridges via simple solder pad bridging option
- PCB designed to fit inside any standard C64 cartridge shell, including centre post versions
- Rounded corners to allow for easier cartridge insertion and reduced wear to PCB

(*) CAUTION: Only make DIP switch changes when computer is power off. Never change DIP switch settings while cartridge is inserted and computer is powered on.

# The board

## Jumpers and DIP switches

Bank control

test points: CPU A15, A14, A13 ROMs with start address $E000 ROMs with start address $8000 #ROML & #ROMH are mixed by D1 and D2 in 16k mode because two chipselects has to become one The computer controls EPROM_A13 in 16k mode The dipswitch controls EPROM_ A13 in 8k mode.

Technical note: The Versa64Cart makes it possible to run 2x8k (16k) ROM games on a single 16k EPROM device. Two chipselects has to become one, and the two 8k images has to be banked with A13.

Banking is easy! We let the computer control EPROM_A13. A jumper is put on J5:16k. The jumper now disconnects DIP switch A13 and reconnects #ROML to EPROM_A13. We have banking! The two chipselects are #ROMH and #ROML and are mixed with D1 and D2. A jumper on J6:16k routes the mixed signal to the EPROM_#OE.

Instead of #ROML on EPROM_A13 we could have used CPU_A13. It would have a better timing, because #ROML is a product of A13 from the PLA, but would it work in ultimax mode? In ultimax mode the two 8k banks are not placed adjacent ($8000-9FFF and $E000-$FFFF).

## Solder Jumpers

You don't need to attach jumpers and DIP switches if you just want a single game or a dead test cart. You can use solder jumpers instead.

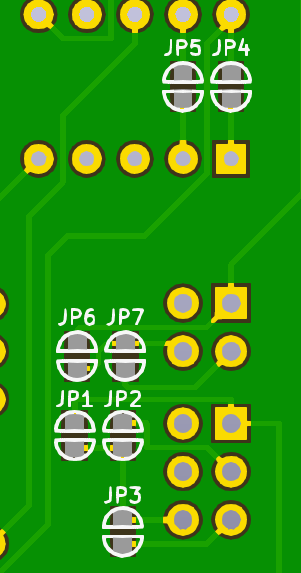
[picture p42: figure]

solder jumper settings | #EXROM | #GAME | switch | 16K | 16K | #ROML | #ROMH
mode | JP5 | JP4 | JP6 | JP7 | JP1 | JP2 | JP3
8k | x | | x | | | x
8k ultimax | | x | x | | | | x
16k | x | x | | x | x
16k ultimax | | x | | x | x

# The ROM image

## Setting #GAME and #EXROM

Mapping the EPROM into memory is done with the #EXROM and #GAME jumpers. There are 4 modes:

8k: #EXROM=0, #GAME=1 : start $8000-$9FFF #ROML

8k ultimax: #EXROM=1, #GAME=0 : start $E000-$FFFF #ROMH

16k: #EXROM=0, #GAME=0 : start $8000-$9FFF (#ROML) + $A000-$BFFF (#ROMH)

16k ultimax: #EXROM=1, #GAME=0 : start $8000-$9FFF (#ROML) + $E000-$FFFF (#ROMH)

You can find the mode of a .CRT file using WinVICE's cartconv.exe.

C:\WinVICE-2.4-x86>cartconv -f Wizard_of_Wor.crt

CRT Version: 1.0

Name: Wizard of Wor

Hardware ID: 0 (Generic Cartridge)

Mode: exrom: 0 game: 0 (16k Game)

offset sig type bank start size chunklen

$000040 CHIP ROM #000 $8000 $4000 $4010

Finding the mode for Wizard of Wor in a CRT file.

#EXROM and #GAME are routed to the PLA and the PLA is the address decoder inside the C64. The PLA controls and drives the ROML and ROMH signals used to put the EPROM onto the data bus.

## Converting .CRT to .BIN

The EPROM must be programmed with a binary file. Use WinVICE's cartconv.exe tool to convert the .CRT file.

C:\WinVICE-2.4-x86>cartconv -i Wizard_of_Wor.crt -o wizardofwor.bin

Input file : Wizard_of_Wor.crt

Output file : wizardofwor.bin

Conversion from Generic Cartridge .crt to binary format successful.

Converting CRT to BIN for burning to EPROM.

# Examples

## Dead Test Cart example

You must program a 27C64 EPROM with the dead test image. The Dead Test cartridge is in 8k ultimax mode (Please see "Setting #GAME and #EXROM"), and effectively replaces the C64 Kernel ROM. Solder in the programmed EPROM, and put a solder blob on JP4, JP6, and JP3 to configure as shown in the table above. Solder in the four 22k resistors. Solder in a 100nF cap on C1.
Note: If you use 27C128/256/512, and you have burned the 8k image in the beginning of the EPROM, you must connect A15, A14 and A13 to GND on SW1. You can do that by soldering three wires from top to bottom of SW1 where the silkscreen says A15 A14 and A13.

## Multi-Cart example

An example with 16k + 8k + 8k ROM images on a 27C256 (32k) EPROM.

Jumpan Junior: 16k, #EXROM=0, #GAME=0, start=$8000

Dead Test: 8k ultimax, #EXROM=1, #GAME=0, start=$E000 (#ROMH)

Jupiter Lander: Same as Dead Test. Usually it is not ultimax though.

memory area | ROM image | DIP switches & jumpers
$0000-$1FFF | Jumpan Junior | ↑↑x↑x, J5:16k, J6:16k
$2000-$3FFF
$4000-$5FFF | Dead Test | ↑↓x↓↑, J5:Switch, J6:#ROMH
$6000-$7FFF | Jupiter Lander | ↑↓x↓↓, J5:Switch, J6:#ROMH

DIP switch positions: ↑=0V, ↓=5V, x=don't care

Solder in the programmed EPROM, the DIP switches, the 2x2 and 2x3 2.56mm pinheader, two 1n4148 on D1 and D2, the four 22k resistors, and a 100nF cap on C1. Use jumpers on J5 and J6.

This is the same example I have used in my Versa64Cart YouTube video. Now you should write down the settings because you will forget them. A 27C512 ROM will give you twice as much space. Eight 8k games, four 16k games or a mix of this.

# Other notes

Kernal ROMs on the cartridge does not work.

# Board Manufacturing

The board thickness is 1.6mm. The board is 58.0 x 48.9 mm. PCB prototyping houses take gerber files. Some companies can handle .kicad_pcb files directly. Creating gerbers is beyond the scope of this document, however I have made a video about it on my YouTube Channel (https://www.youtube.com/c/bwack):

- KiCAD Gerber files and DirtyPCBs (https://www.youtube.com/watch?v=NZ9kQpM7UwQ)

# Enclosures

The board is based on original cartridges and enclosures. The board width is 58mm. It fits original cartridge enclosures and Jim Brain's ones too. It does not fit stumpy cart. The standoffs are 1mm narrower. That can be tweeked. You can't use a ic-socket because then the eprom hits the top.

# Aknowledgements

I would first of all like to thank MindFlare Retro for helping me out with this document. Also a thank you to Jim Brain for the Simple64Cart and its eagle design files. MindFlare converted the eagle .brd file to kicad. I took the cartridge outline (document layer) and imported it in my own design. From there it was super easy to design on top of that drawing. Also a big thanks to my viewers on YouTube for feedback on this project.

# PCBnew Screenshot

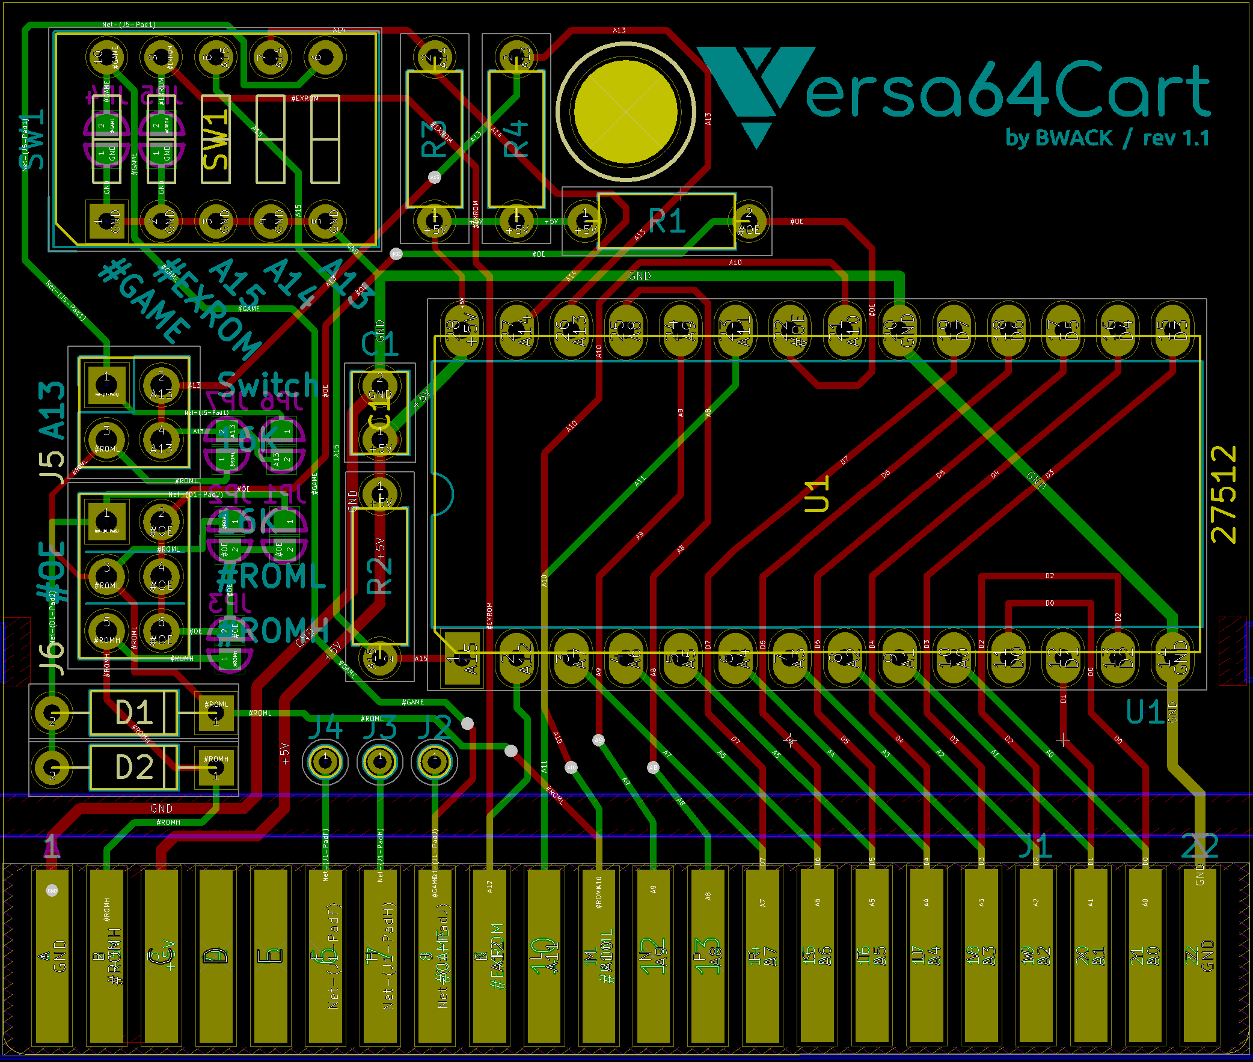
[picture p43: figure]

Zoom on the PDF to see the signal names on the traces.

# Schematics

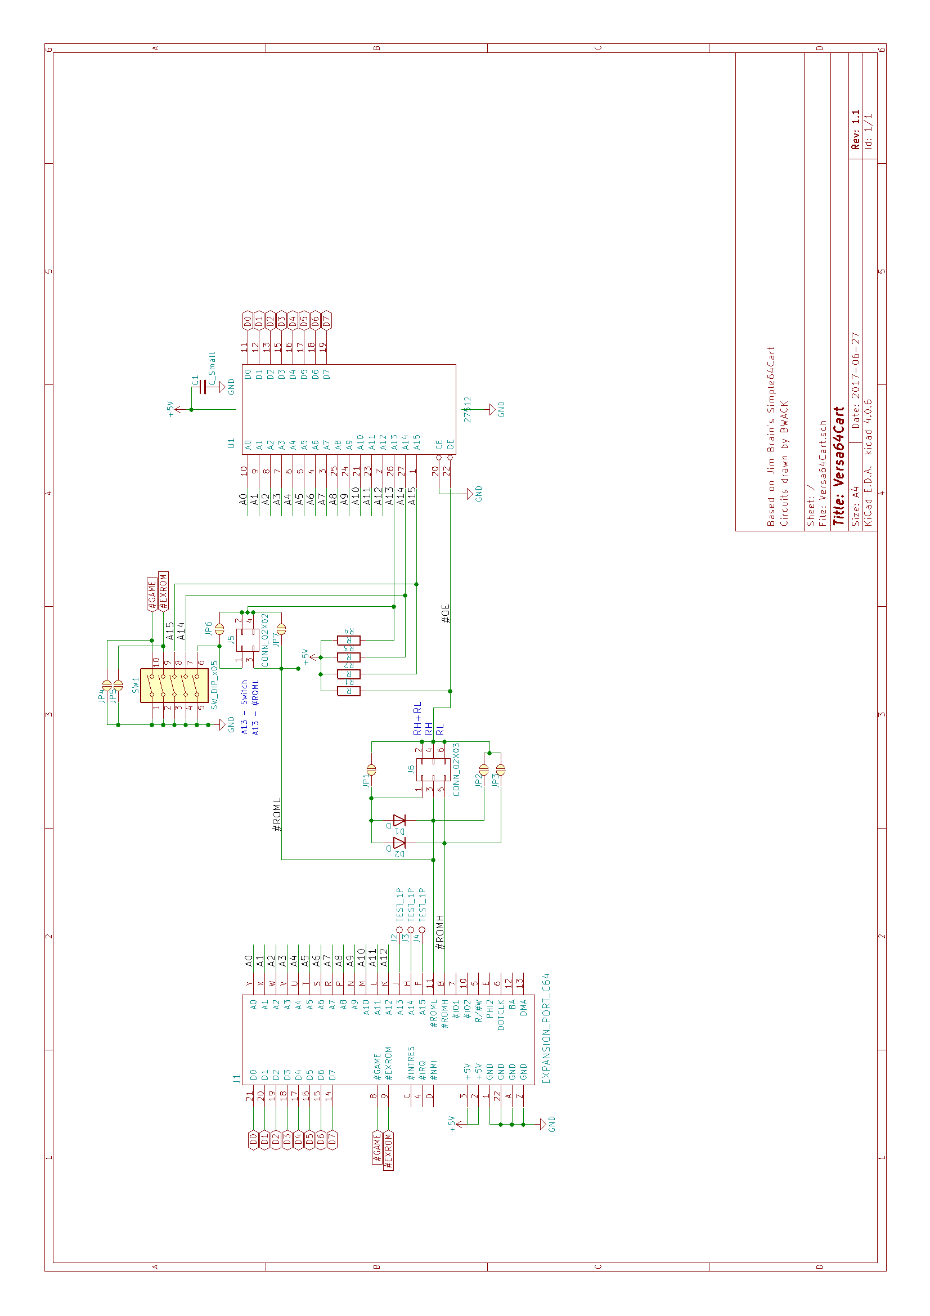
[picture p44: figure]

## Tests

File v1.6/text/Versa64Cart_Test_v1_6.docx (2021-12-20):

Versa64Cart v1.6

Testing

# Test Description

The electrical test was executed with a Versa64Cart v1.2 (the differences to v1.3 to v1.6 are not functional), a C64G (Mainboard ASSY 250469) and an EPROM type ST micro M27C512 10F1. The programming of the EPROM was done with a TL866II Plus programmer.

The following binaries were loaded into the program memory of the programmer, programed to the EPROM and verified “ok”:

Binary | Binary # | Start Address | End Address
Neutron.bin | 1 | 0x0000 | 0x3FFF
Deadtest.bin | 2 | 0x4000 | 0x5FFF
586220plus_0_4.bin | 3 | 0x6000 | 0x7FFF
LalaPrologue.bin | 4 | 0x8000 | 0xBFFF

The EPROM was inserted into the socket of Versa64Cart, which was then configured, inserted into the C64, the C64 was switched on and the selected binary was run.

# Test Execution

Binary # | A15..13 | | | J6 | J5 A13 | Observation | Testing
1 | LLL | L | L | 16k | 16k | working | ok
2 | LHL | L | H | | Switch | working | ok
3 | LHH | H | L | | Switch | working | ok
4 | HLL | L | L | 16k | 16k | working | ok

Test | Observation | Testing
Does the Cart fit into the slot? | yes | ok
Does the Cart move inside the slot? | The Cart moves 0.9mm from left to right in total. The contacts of the cartridge connector do not leave the contact pad. | ok
Comparison of measures v1.2 vs. v1.1 | Both PCBs have the same dimensions. The mounting holes are aligned. The port contacts are aligned, the contacts of v1.2 are wider. | ok
Reset button | Binary #1 can be restarted by pushing the reset button. Some software (e.g. LalaPrologue.bin) does not reset well after pressing the RESET button. It depends on that software, not on the memory bank. | ok
Running cartridge with a breakout board, which adds 90mm to the bus | Binary #1 is running The bus length is not critical | ok

The critical signal is the pulse for the EPROM when the 16k-mode is selected. It can either be too wide or the low level is above 0.7V (the upper margin for a TTL low level).

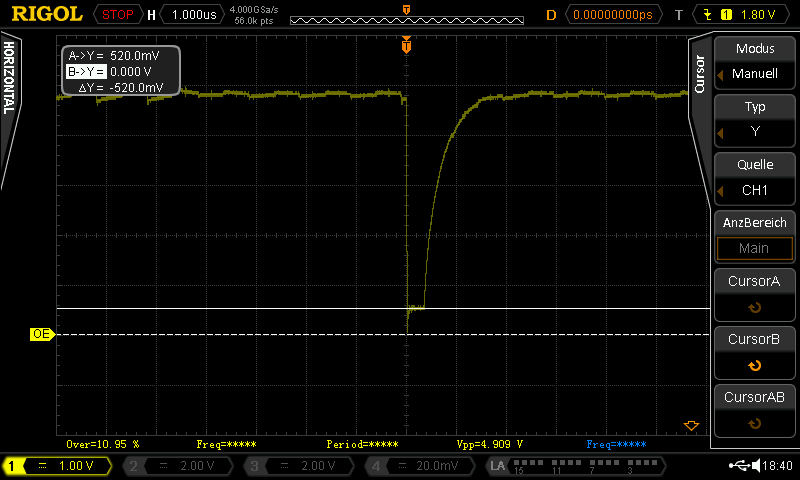
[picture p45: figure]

Figure 1: The /OE pulse (low level = 520mV)

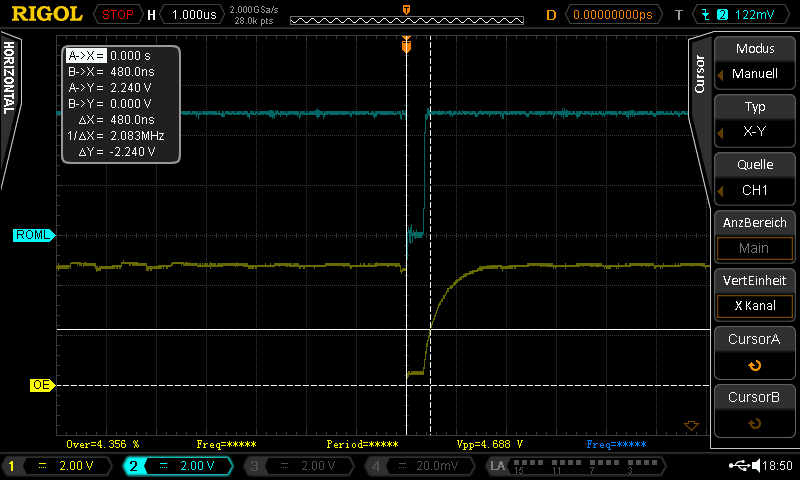
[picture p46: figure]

Figure 2: /OE pulse (pulse width = 480ns)

Test | Observation | Testing
Low level of the 16k- OE pulse below 0.7V | The low level is 520mV | ok
Pulse width of the 16k-OE pulse less than 500ns (?) | The pulse width is 480ns | ok (?)

Test | Observation | Testing
Neutron.bin & LalaPrologue.bin were programmed into a 27C256, A15 was set HIGH | Both games started and played properly. | ok
LalaPrologue.bin was programmed into a 27C128A, A15 & A14 were set HIGH | Game started and played properly. | ok
1541diagcart.bin was programmed into a 27C164A, A13..A15:HHH, : H, : L, : ROML | Software started and worked properly | ok

# Testing the Rev. 1.6 in a Stumpy Cartridge Case


Figure 3: Versa64cart Rev. 1.6 on an open Stumpy cartridge case

# Conclusion

- All extra address lines (A15 … A13) can be asserted
- can be configured properly
- can be configured properly
- works as a chip select
- works as a chip select
- The 16k works properly, the timing cannot be proved ok, due to a lack of information.
- All binaries are running (16k, 8k Game, 8k Exrom)
- EPROM types tested: ST M27C512, M27C256B, M27C128A, M27C64A
- The notches of Rev. 1.6 fit the Stumpy cartridge case.

The Versa64Cart v1.6 is fully functional.

Versa64Cart_Test_v1_6.docx 19.12.2021 16:30 Drafted by Sven Petersen Page 2 of 2 Doc.-No.: 121-6-03-01.6

Versa64Cart_Test_v1_6.docx 19.12.2021 16:30 Drafted by Sven Petersen Page 1 of 1 Doc.-No.: 121-6-03-01.5

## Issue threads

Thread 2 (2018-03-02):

Bomberland 64k

rmueller83, 2018-03-02:
Hi,

[Bomberland](https://rgcddev.itch.io/bomberland) is not available for order any more, but the 64k crt is freely downloadable at the bottom of the linked webpage. It should fit in a 27C512 but the Versa64Cart manual only lists 8k and 16k configurations. Would this work with Versa64Cart?

```
cartconv -f bomberland.crt
CRT Version: 1.0
Name: VICE CART
Hardware ID: 19 (Magic Desk)
Mode: exrom: 0 game: 1 (8k Game)

offset  sig  type  bank start size  chunklen
$000040 CHIP ROM   #000 $8000 $2000 $2010
$002050 CHIP ROM   #001 $8000 $2000 $2010
$004060 CHIP ROM   #002 $8000 $2000 $2010
$006070 CHIP ROM   #003 $8000 $2000 $2010
$008080 CHIP ROM   #004 $8000 $2000 $2010
$00a090 CHIP ROM   #005 $8000 $2000 $2010
$00c0a0 CHIP ROM   #006 $8000 $2000 $2010
$00e0b0 CHIP ROM   #007 $8000 $2000 $2010

total banks: 8 size: $010000
```

bwack, 2018-03-04:
Hi. No. I would guess it would need more digital logic circuits to switch between the eight banks.

tomse, 2018-07-28:
Sorry for posting to an older thread, but Bomberland is indeed available still
http://rgcd.bigcartel.com/product/bomberland-commodore-64

Closed 2018-09-22.

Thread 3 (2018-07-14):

Nice work on Versa64cart!

C-64Bram, 2018-07-14:
Hi Bwack.
I just saw your Versacart and it looks like a great piece of work! I understand it can hold up to 8 programs , each 8kb in a 512 eprom and each of the 8kb can be selected by changing the dipswitches. Perhaps a stupid question but I was wondering: can the Versacart be used to switch between kernelroms as well? So 8 different kernals in a 512 KB eprom and switch between Them by changing the dipswitches?
Best regards,
Bram.

VintageProject, 2018-07-16:
Hi Bram,
the switching mechanism is similar, I think. Both rely on working with address lines A13-A15 to select the appropriate 8kB bank. (8 kilobyte (kB) rather than 8 kilobit (kb))
Look at the switchless Kernal switcher here: https://github.com/bwack/C64-Switchless-Multi-Kernal-27C256-adapter
It's designed for 4 different Kernals with 8 kB each, so it only uses 256 kB instead of 512 kB. But the way it works would be very similar. Just add A13 to the equation.

It doesn't use DIP switches but rather a microcontroller that does the ROM selection and automatic reset for you. Thanks to bwack, I have one in my C64 and it works a treat!

Best regards,
Thilo

C-64Bram, 2018-07-16:
HHi Thilo,
Thanks! I will try it when I am back from vacation. :-)
I will check out the kernal switcher for sure too!

Best regards,
Bram.

Op ma 16 jul. 2018 08:32 schreef Thilo N <notifications@github.com>:

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

bwack, 2018-09-22:
Late answer, but here is one in case more is wondering..
In ultimax mode (see docs), the cartridge replaces the kernal memory region with the cartridge rom, but I don't know what happens to the rest of the memory map, and if it is the same as just replacing the kernal ic. It must be tried. :)

C-64Bram, 2018-09-22:
Hi.! I will try in a few days .
To busy with work at the time. :-(
Thank you for the answer!!

Best regards,
Bram.

Op za 22 sep. 2018 11:08 schreef bwack <notifications@github.com>:

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

bwack, 2018-09-22:
I asked on facebook and got a reply that it won't work because even if you replace the kernal by putting the cart in ultimax mode, the c64 can only access 4k of the RAM. The kernal will not work then.

C-64Bram, 2018-09-22:
Aha.
Thanks! No problem.
It is still a great design, this cartridge of yours. :-)
I am enjoying it very much!

Best regards, Bram

Op za 22 sep. 2018 21:41 schreef bwack <notifications@github.com>:

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

bwack, 2018-09-22:
Thank you very much. Glad you like it :)

Closed 2018-09-22.

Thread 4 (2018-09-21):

Dead Test Cart on 27C256

sajattack, 2018-09-21:
I couldn't find any 27C64's like the guide recommends for a Dead Test Cart so I programmed it into the lower 8K of a 27C256 and zeroed the rest. I followed the guide, jumping JP3, JP4, and JP6. It doesn't seem to be working. Any ideas why? Are there any solutions that don't involve reprogramming the chip? It's already soldered in (unsocketed) and I don't really want to have to desolder it. Hope you can help. If there's a better place for support requests please let me know.

bwack, 2018-09-22:
Suggestion: Move R1 and R2 to SW1 at where it says A15 and A14 on the silkscreen. then those two lines will be pulled low. Hell, or just use wires on SW1 to pull A15 and A14 to ground.

bwack, 2018-09-22:
and A13. Sorry too late. My head is not working.

bwack, 2018-09-22:
A15 has only an effect on 27C512 :) so it is A13 and A14 then.

sajattack, 2018-09-22:
Thanks. Got it working.

bwack, 2018-09-22:
Great :)

Closed 2018-09-22.

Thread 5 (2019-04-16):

Gerbers are wrong!

TabajaraLabs, 2019-04-16:
Gerbers are wrong in dir gerbers and the gerbers.zip file

bwack, 2019-04-17:
Hi. Let me know which pcb manufacturer you are using so I can help you. MAybe the files just need renaming. It varies from manufacturer to manufacturer.

bwack, 2019-04-18:
Can you be more specific ?

Closed 2019-04-25.

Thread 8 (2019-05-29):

sharewareplus and tfw8bit stumpy cart enclosures does not fit

bwack, 2019-05-29:
Issue regarding Versa64cart v1.1 and v1.2

# sharewareplus cart enclosure hits the diode
The sharewareplus cartridge enclosure beam near the pcb edge fingers rest on top of the diodes.
http://sharewareplus.blogspot.com/

# tfw8bit stumpy 1mm narrower
The stumpy cart dimensions is different to Commodore. It is only a millimeter or so it should be easy to modify the pcb to fit all the carts out there.
https://www.thefuturewas8bit.com/shop/commodore/c64romcart.html
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

# retro innovations enclosure: jumpers hits roof
Currently, I've only tested the cartridge with cartriges from retro innovation. The jumpers hit the top enclosure wall. Might aswell be a problem in other carts
http://store.go4retro.com/categories/Commodore/Hardware/

svenpetersen1965, 2019-05-30:
I have fixed the problem with the diodes being too far south. From v1.1 to v1.2 they moved south about 1mm. I have now moved them north about 5mm, they are aproximately flush with the IC socket.

I have compared the width of 58mm woth all different cartridges I had. Dela DOS: 58.0mm, REX 9628: 58.0mm, FCIII+: 58.0mm, Simple64Cart57.8mm, Handic Forth 64: 58.0mm, Ultimate II+: 57.4mm. Right now, the Versa64Cart moves 0.8mm from one side to the other, after reducing width by 1mm, that would be 1.8mm. The pitch is 2.54mm. For my taste, it would be too much and we might get even shortcuts between the neigboring contacts. We should not do that.

bwack, 2019-05-30:
Ok thanks a lot! for reference, the stumpy pcb is 57mm. I agree regarding not narrowing the board.

bwack, 2019-05-30:
second problem is now that the diodes might hit the resting stands on the left. (and also on the right of the board, but that is the other issue).

svenpetersen1965, 2019-05-30:
Moved the diodes east by 3.463mm.
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
Anything else, that needs to be changed?

bwack, 2019-05-30:
Awesome! Yesh! https://github.com/bwack/Versa64Cart/issues/9 :)

Closed 2019-07-08.

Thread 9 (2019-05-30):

v1.2 IC1 too close to right-edge

bwack, 2019-05-30:
IC1 is too close to the right edge and hits resting-post on original cart and retro innovations cart.
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

retroinnovation cart. similar:
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

This was a problem in Simple64cart too.
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

Versa64Cart v1.1 has the ic1 (U1 v1.1) about 1mm further to the left.

svenpetersen1965, 2019-05-30:
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
So now the IC and C1 are moved west by 1.6mm. Ok?

bwack, 2019-05-30:
Perfect ! That should do the trick!

svenpetersen1965, 2019-05-30:
So I generate the Gerbers :-) Maybe first optimize the traces a bit. And hey, the parcel arrived... that made my day :-)

bwack, 2019-05-30:
Thanks. I'll order pcb's tonight myself of the new v1.3. Thanks alot for the boards in the parsel and Tee ! There will be future videos of a couple of these boards :)

svenpetersen1965, 2019-05-30:
<3

Closed 2019-07-08.

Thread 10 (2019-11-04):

New version 1.5

kopsec, 2019-11-04:
I have made small mods to V1.4 dessign, really don't know the exact differences with v1.4

- Added a SP3T slide swith for J6 (very usefull for mounting inside a cartridge case). Do not use switch and pin headers at same time, use only one.
- Removed all the vias near the edge connector, this allow the PCB to be manufactured using GOLD ENIG "gold fingers".
- Increased diameter on vias holes to 0.5mm to be compatible with PCBs manufacturers.
- Increased also some layers width.
[Versa64Cart_v1_5.zip](https://github.com/bwack/Versa64Cart/files/3803488/Versa64Cart_v1_5.zip)
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

bwack, 2019-11-08:
Hi it nice to see people take an interest in this design. I'm not having time and energy to work on a new version now. Also because the design moved from KiCad to Eagle by Sven I don't have the tools to verify. Sorry.

kopsec, 2019-11-09:
OK. I don't know how to work with GitHub, so I put it here, just to share it with people.
Just say that is tested and working. Cheers!

Closed 2024-01-21.

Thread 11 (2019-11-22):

lack of information regarding .bin files merging

vidmo91, 2019-11-22:
Hi,
it's not a big deal, but adding that info to the manual would help others. I waste some time using a few bad methods before finding good one.

Simplest working method in Windows:
1. open cmd in folder containing bin files,
2. use command form merging binary files files into new one:
`copy /b file_1.bin + file_2.bin + ... + file_n.bin output_file.bin`
eg.
`copy /b DeadTest.bin + jupiterl.bin + SomeGame.bin combined.bin`
or
`copy /b DeadtTest.bin + jupiterl.bin combined.bin`

This for sure won't work: copy-paste in Hex-editor plugin of Notepad++

bwack, 2019-11-23:
@svenpetersen1965 Any suggestions ?

svenpetersen1965, 2019-11-23:
I can integrate it into the manual. It will not work, if a files has other than exactly 8k or 16k content, though.

bwack, 2019-11-23:
Right, the problem you mention Sven is a special case for mixed 8k and 16k game images. What you can do then is a simple trick and copy the same 8k binary twice. In that way you are making only 16k slots. Example with one 8k game and 16k game on a 32k eeprom:

`copy /b first8kgame.bin + first8game.bin + second16kgame.bin epromimage.bin`

Maybe also an example in the docs would be nice, and titles like "Example I - deadtest", etc.. If you like I can try import the msword doc into google docs format and we can work on it together. I'd like to fix some small mistakes. Google docs can save to pdf also.

svenpetersen1965, 2019-11-26:
I have changed the Module description. Please find it on the google drive.

bwack, 2019-11-28:
Thanks for updating, Sven. Closing this issue.

Closed 2019-11-28.

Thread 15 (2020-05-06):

Suggestion: Replace SW1 and solder blobs by pin/jumper

pablocastine, 2020-05-06:
Just wanted to know your opinion about replacing the DIP switch at SW1 and the solder blobs at GAME/EXROM/A13/A14/A15 by standard 2.54mm pitch pins as found in ROMH/ROML in order to a) some sellers might not have that specific 5-bit DIP switch in stock and b) 100% solder-less configuration using standard jumpers.

Thanks.

bwack, 2020-05-06:
Thats not a bad idea. Lets ask @svenpetersen1965  :)

svenpetersen1965, 2020-05-07:
I think, the Dip-switch can be replaced with a combination footprint of a jumper and the dip switch. I was thinking of that already some days ago. I would prefer to keep the solder bridges as is, because they are of good use.

bwack, 2020-05-07:
Thanks Sven! I have updated the repository and releases.

pablocastine, 2020-05-07:
Great work guys!

Closed 2020-05-08.

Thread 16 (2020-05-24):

Typo in 16k Game documentation for 1.4 and 1.5

bagofarms, 2020-05-24:
On page 7 of the 1.4 and 1.5 documentation, in the section titled "4.4. Example III", I believe there is a typo on the first row of the table.  The neutron.crt file reports `exrom: 0 game: 0 (16k Game)`, and I think `0 (=LOK)` is supposed to be `0 (=LOW)`.  Also, I think the Setting column for !GAME is supposed to be `SW1-1 = ON` instead.  I tested this with doccosmos.crt, which reports the same information as the neutron.crt example in the documentation, and having SW1-1 set to ON worked perfectly.

(P.S. Great work on this pcb!  It's so compact and well documented.  I went from not knowing anything about C64 cartridges to building my own cart and flashing the ROM chips within a couple of hours!)

bwack, 2020-10-17:
Sorry for the late reply. I'll have to ask  @svenpetersen1965  for help on this one :)

bwack, 2020-10-17:
You are right ! :) It should say LOW and ON :) Thanks for help !

bwack, 2020-10-18:
Thanks for the tip and also thanks for help by  @svenpetersen1965  :)

bagofarms, 2020-10-18:
Glad I could help!

Closed 2020-10-18.

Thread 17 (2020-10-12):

Question: why the switch from KiCad to Eagle ?

uffejakobsen, 2020-10-12:
Question: why the switch from KiCad to Eagle ?

It would seem more logical to have an open project like this supported by an open program as KiCad - than a proprietary program as Eagle

bwack, 2020-10-13:
Hi. I agree regarding open design and tools. The eagle boards are drawn by Sven. It ads some minor changes, but they are not anything you will mis in V1. 1 KiCad version.

uffejakobsen, 2020-10-13:
Thanks for your answer
Well - I'm interested in some of the changes up to and including version 1.5
So I guess that I'll have to check if the new KiCad Eagle import is as good as they say :-)

bwack, 2020-10-17:
I tried KiCad Eagle import in KiCad 5.1.4, and I'm impressed. :)

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

uffejakobsen, 2020-10-18:
Yes, exactly my point - the KiCad 5.x release series has improved a lot of things.
Actually I've not yet tried the Eagle import - but guess that your picture is the result of an Eagle import into KiCad  ? :-)

bwack, 2020-10-18:
Yes. I tried another project too now, and it also went well. It was a hotplate "soldering iron" project :) https://github.com/makermoekoe/Hotplate-Soldering-Iron

uffejakobsen, 2020-10-20:
Great news - thanks :+1:

Closed 2020-10-20.

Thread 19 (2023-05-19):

28C64 EEPROM?

oXL0C0Xo, 2023-05-19:
I'm curious if there is a way to use a 28C64 EEPROM in this instead of a 27C64, as I have a ton of them. I have tried, but I just get a black screen. It looked like the 28C64 was pin compatible, so I was thinking this is strange. Anyways, thank you for the project!

uffejakobsen, 2023-05-19:
Hmm, they should work... what brand and speed grade are the 28C64's ?
If you could post the full text from the full text found on the top of the IC - or a photo

oXL0C0Xo, 2023-05-19:
It's at Microchip 28C64AF-15/P
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

uffejakobsen, 2023-05-19:
Ok - just to be sure - A14 and A15 are left open ? or ?

oXL0C0Xo, 2023-05-19:
Ok, so this is how I currently have it soldered. On page 9 of the documentation, it says those three should be open. So I didnt solder them high or low.
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

uffejakobsen, 2023-05-19:
Good hat you posted that photo - I assumed (wrong) that you had populated your PCB with resistors.

You should re-read section 2.4 "Solder Bridges"

I think that you should also solder JP9 and JP11

As stated in the section 2.4 - please ensure that any of the joint-pairs  JP8/JP9, JP10/JP11 and JP12/JP14 are *NEVER* both closed - that will short circuit V5 and GND

oXL0C0Xo, 2023-05-19:
Still black screen. I added jumpers and the resistors to see if it would make any difference. Here’s how it’s jumpers now
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

uffejakobsen, 2023-05-20:
As far as I can see - the jumper config on the last photo is illegal.

For "Dead Test Cartrigde" (Ultimax mode):
EXROM=H
GAME=L
ROML=no jumper
ROMH=jumper set

For "Diagnostics Cartridge" ($8000 - 8k):
EXROM=L
GAME=H
ROML=jumper  set
ROMH=no jumper

oXL0C0Xo, 2023-05-20:
I finally did end up getting this working using the following configuration. Thank you for all of your help 👍
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

uffejakobsen, 2023-05-20:
That is good to hear :+1:

Closed 2024-01-21.

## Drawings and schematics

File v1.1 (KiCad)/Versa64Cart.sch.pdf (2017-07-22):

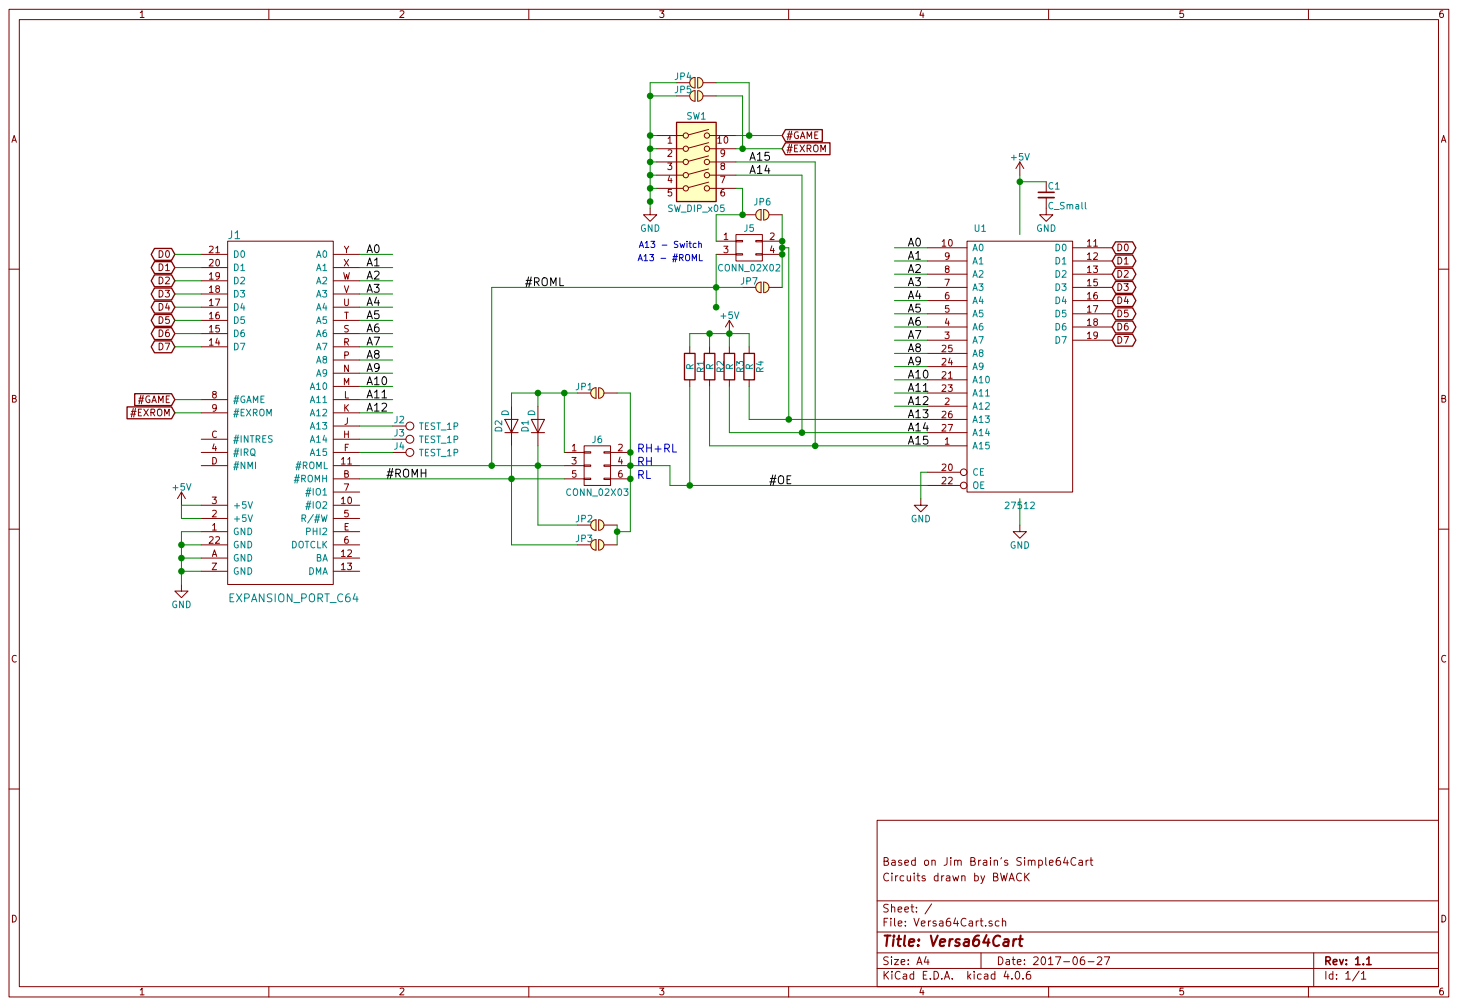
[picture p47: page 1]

Based on Jim Brain's Simple64Cart GND

Id: 1/1 Title: Versa64Cart File: Versa64Cart.sch Sheet: / Circuits drawn by BWACK

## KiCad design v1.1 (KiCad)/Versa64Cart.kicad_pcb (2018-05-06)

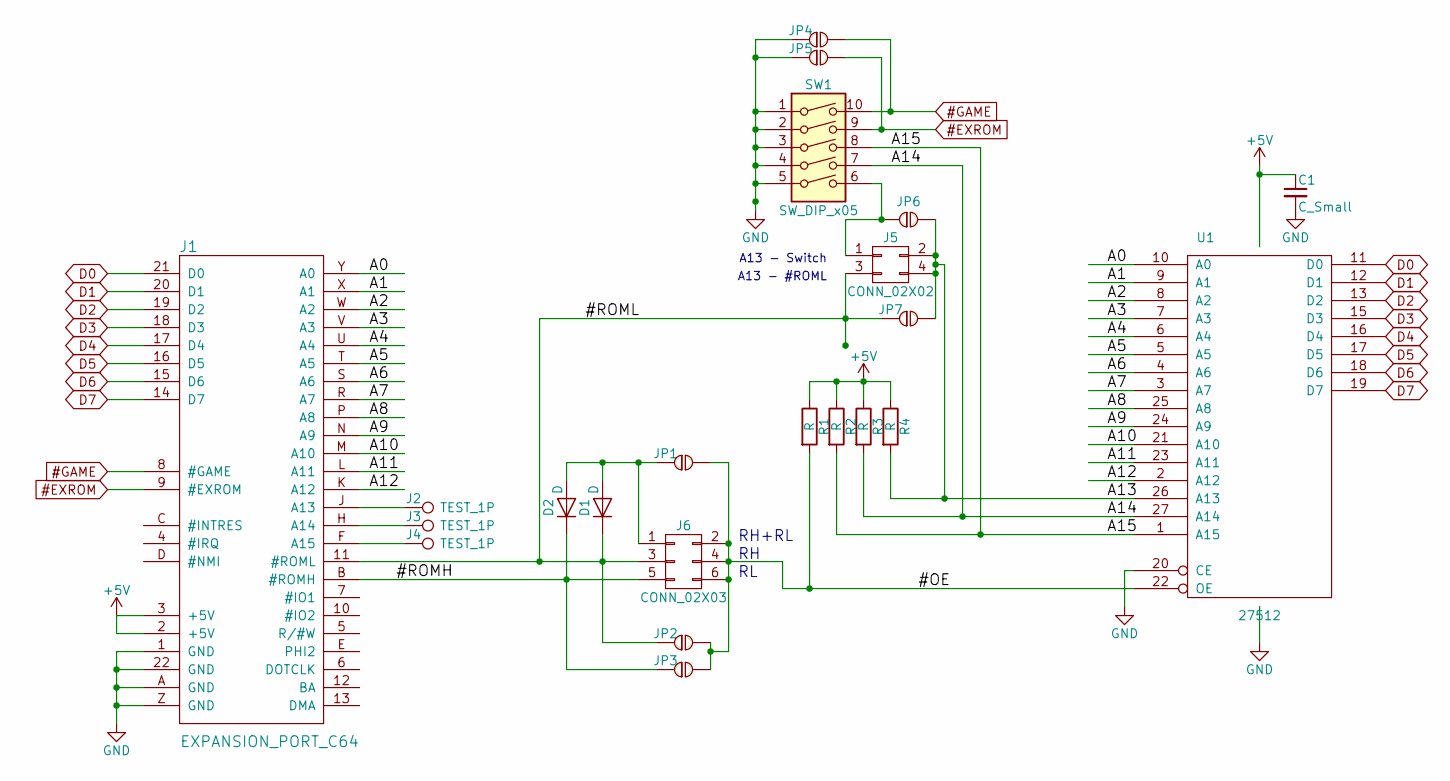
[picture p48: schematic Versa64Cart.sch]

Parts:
C1: C_Small; C_Disc_D3.8mm_W2.6mm_P2.50mm
D1, D2: D; D_DO-35_SOD27_P7.62mm_Horizontal
J1: EXPANSION_PORT_C64; C64_EXPANSION_PORT
J2, J3, J4: TEST_1P; PINTST
J5: CONN_02X02; Pin_Header_Straight_2x02_Pitch2.54mm
J6: CONN_02X03; Pin_Header_Straight_2x03_Pitch2.54mm
JP1, JP2, JP3, JP4, JP5, JP6, JP7: JUMPER_2-PIN; SOLDER-JUMPER_1-WAY
R1, R2, R3, R4: R; R_Axial_DIN0207_L6.3mm_D2.5mm_P7.62mm_Horizontal
SW1: SW_DIP_x05; SW_DIP_x5_W7.62mm_Slide
U1: 27512; DIP-28_W15.24mm_LongPads

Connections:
#EXROM: J1.9 (#EXROM), JP5.2, SW1.9
#GAME: J1.8 (#GAME), JP4.2, SW1.10
+5V: C1.1, J1.2 (+5V), J1.3 (+5V), R1.1, R2.1, R3.1, R4.1, U1.28 (VCC)
/#OE: J6.2, J6.4, J6.6, JP1.2, JP2.2, JP3.2, R1.2, U1.22 (OE)
/#ROMH: D2.1 (K), J1.B (#ROMH), J6.5, JP3.1
/#ROML: D1.1 (K), J1.11 (#ROML), J5.3, J6.3, JP2.1, JP7.1
/A0: J1.Y (A0), U1.10 (A0)
/A1: J1.X (A1), U1.9 (A1)
/A2: J1.W (A2), U1.8 (A2)
/A3: J1.V (A3), U1.7 (A3)
/A4: J1.U (A4), U1.6 (A4)
/A5: J1.T (A5), U1.5 (A5)
/A6: J1.S (A6), U1.4 (A6)
/A7: J1.R (A7), U1.3 (A7)
/A8: J1.P (A8), U1.25 (A8)
/A9: J1.N (A9), U1.24 (A9)
/A10: J1.M (A10), U1.21 (A10)
/A11: J1.L (A11), U1.23 (A11)
/A12: J1.K (A12), U1.2 (A12)
/A13: J5.2, J5.4, JP6.2, JP7.2, R4.2, U1.26 (A13)
/A14: R3.2, SW1.7, U1.27 (A14)
/A15: R2.2, SW1.8, U1.1 (A15)
D0: J1.21 (D0), U1.11 (D0)
D1: J1.20 (D1), U1.12 (D1)
D2: J1.19 (D2), U1.13 (D2)
D3: J1.18 (D3), U1.15 (D3)
D4: J1.17 (D4), U1.16 (D4)
D5: J1.16 (D5), U1.17 (D5)
D6: J1.15 (D6), U1.18 (D6)
D7: J1.14 (D7), U1.19 (D7)
GND: C1.2, J1.1 (GND), J1.22 (GND), J1.A (GND), J1.Z (GND), JP4.1, JP5.1, SW1.1, SW1.2, SW1.3, SW1.4, SW1.5, U1.14 (GND), U1.20 (CE)
unnamed: D1.2 (A), D2.2 (A), J6.1, JP1.1
unnamed: J1.F (A15), J4.1
unnamed: J1.H (A14), J3.1
unnamed: J1.J (A13), J2.1
unnamed: J5.1, JP6.1, SW1.6

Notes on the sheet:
A13 - #ROML
A13 - Switch
RH+RL

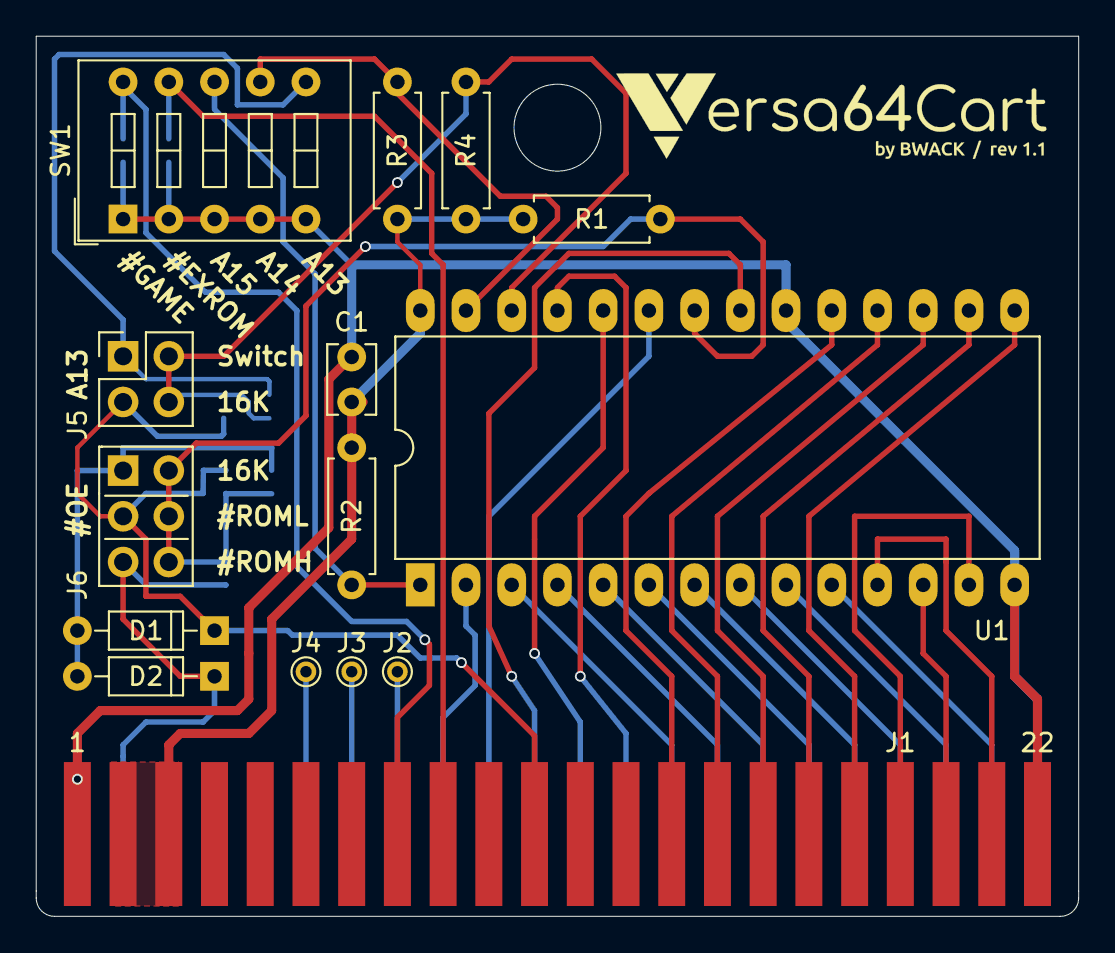
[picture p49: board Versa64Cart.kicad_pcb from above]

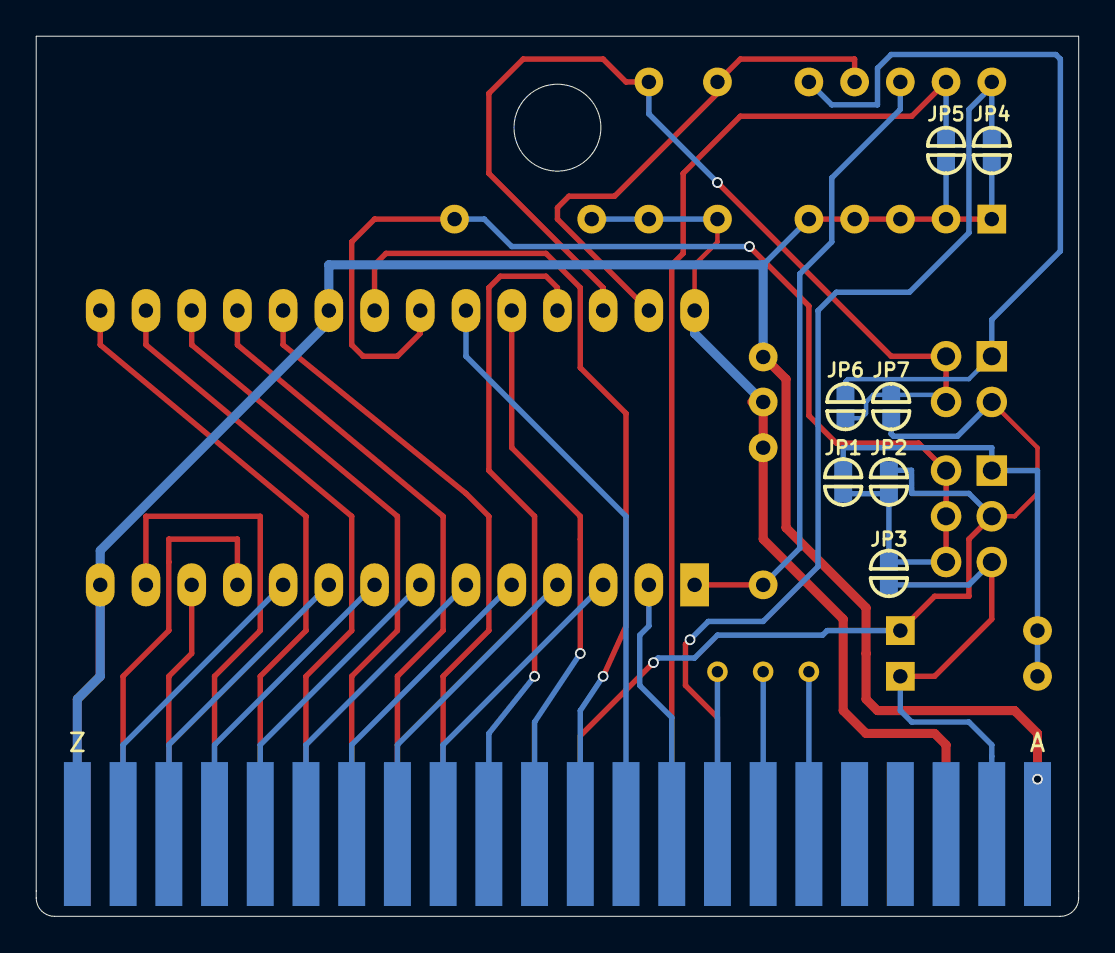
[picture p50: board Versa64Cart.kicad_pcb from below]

Board: 2 copper layers, 57.9 x 48.9 mm, 22 parts (7 on the bottom side), 36 nets.

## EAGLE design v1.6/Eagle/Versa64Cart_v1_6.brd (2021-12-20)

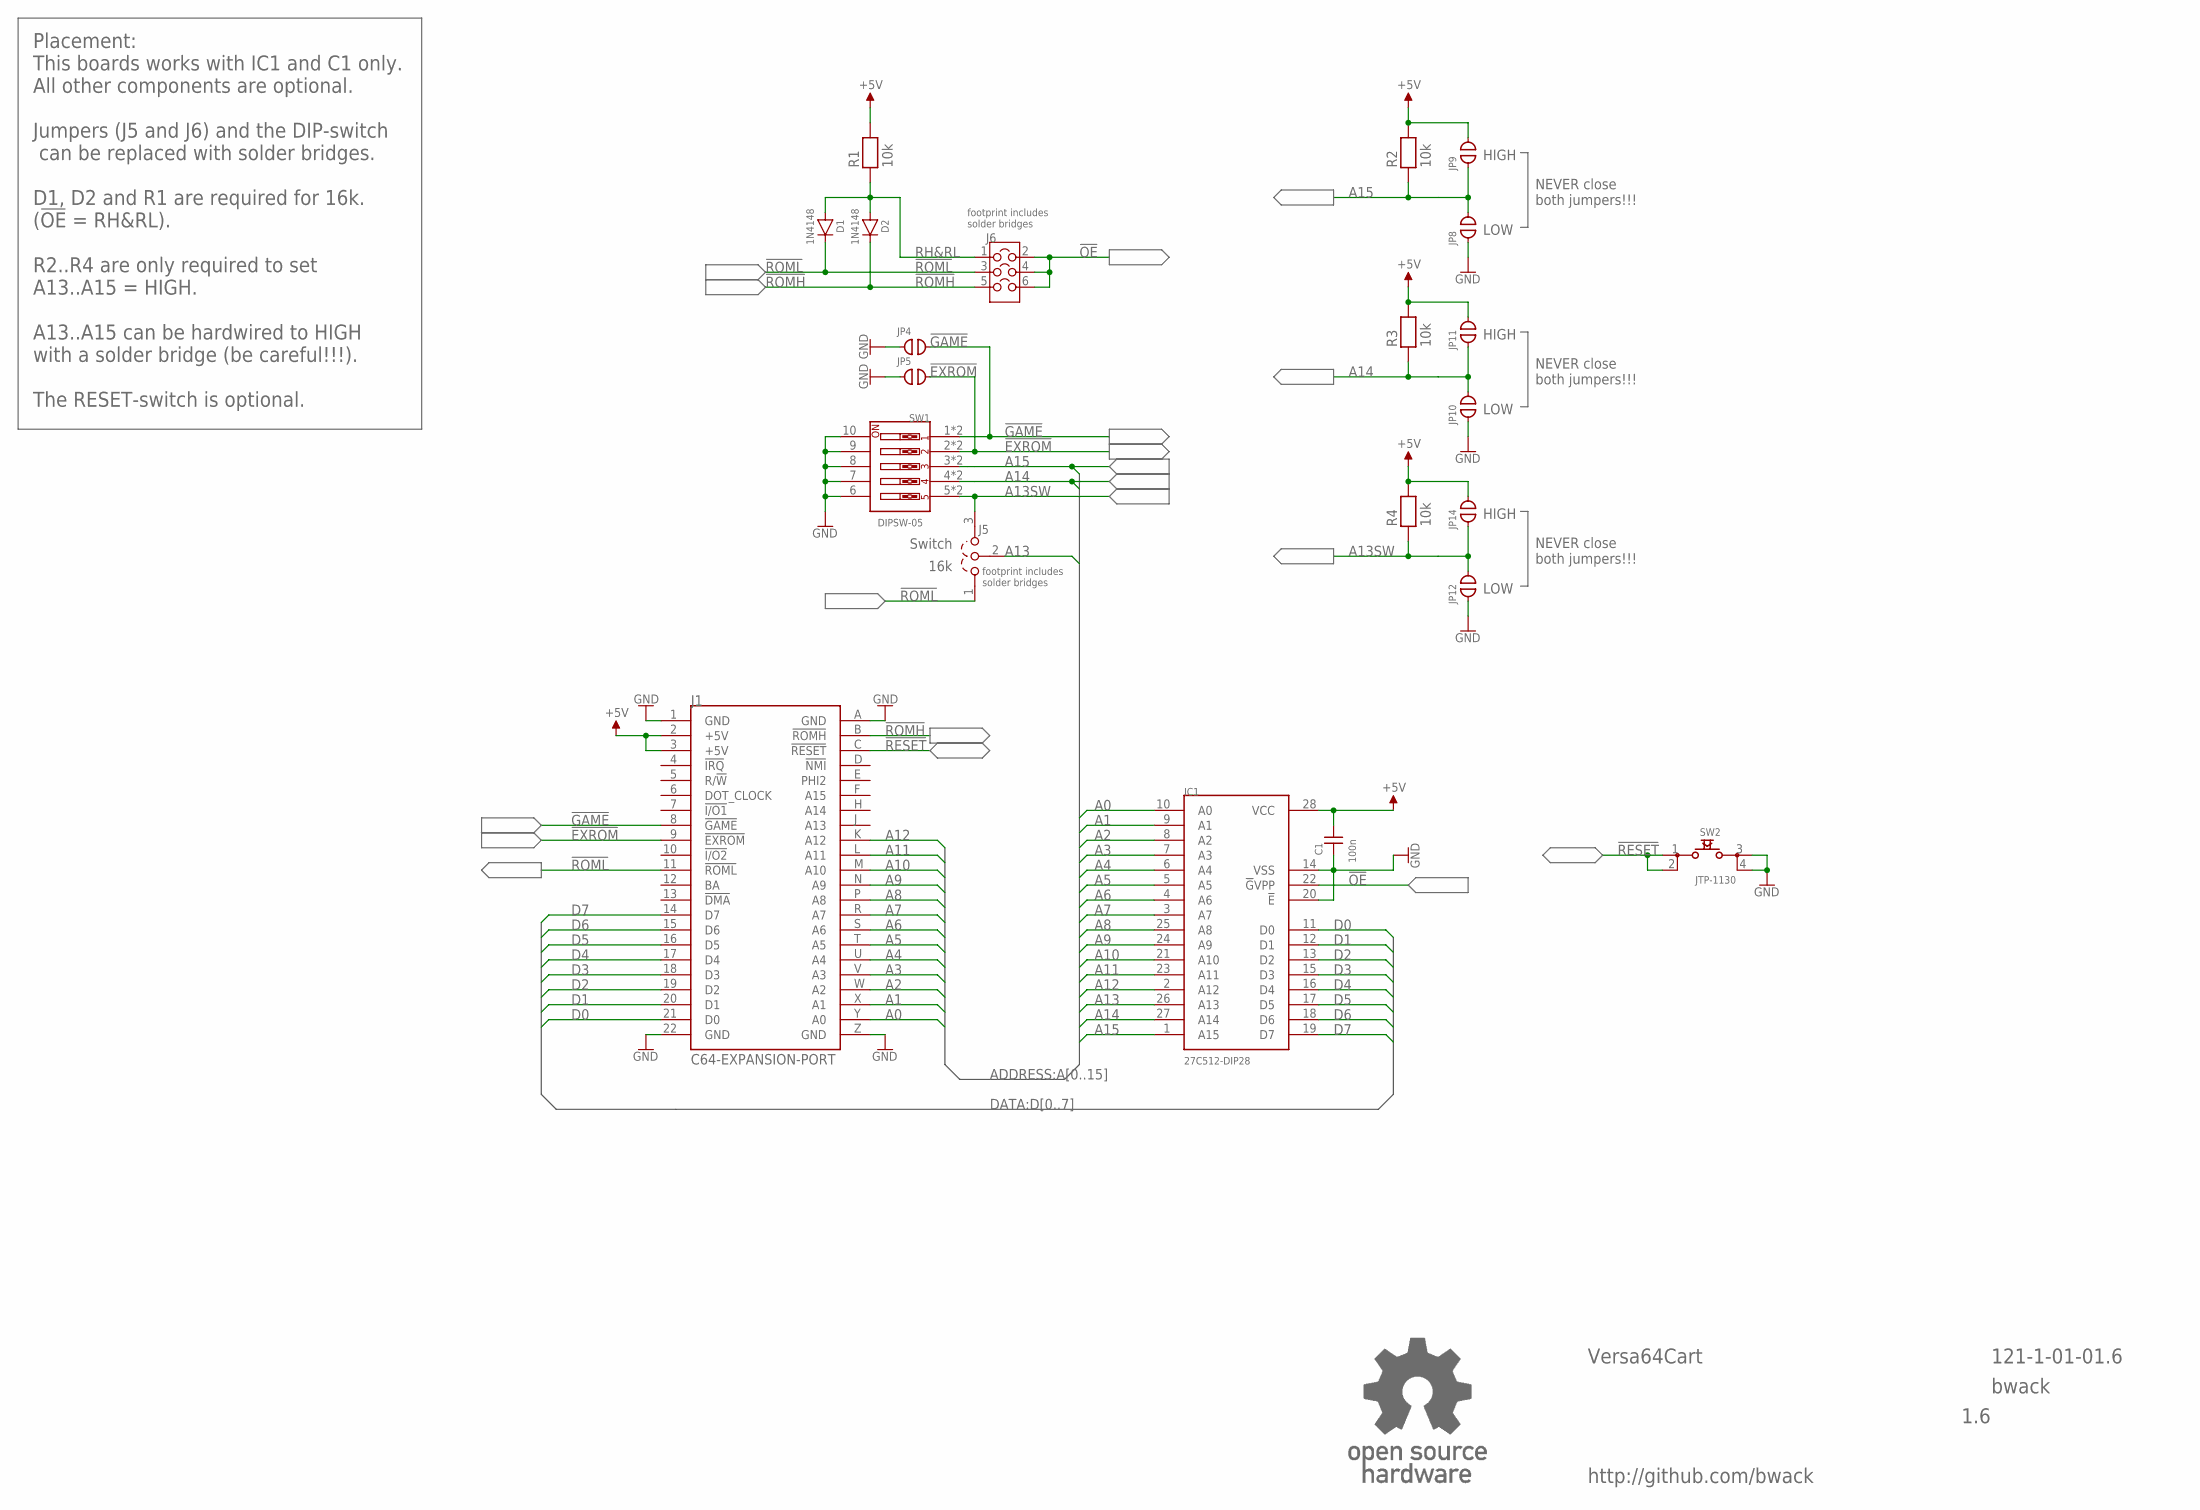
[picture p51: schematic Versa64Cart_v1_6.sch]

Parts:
C1: 100n; C-2,5
D1, D2: 1N4148; DO-35
IC1: 27C512-DIP28; DIL28-6
J1: C64-EXPANSION-PORT; EXPANSIO_SQ
J5: COMBI-3P
J6: COMBI-3X2P; COMBI-3X2
JP4, JP5, JP8, JP9, JP10, JP11, JP12, JP14: OPEN; CP_OP
R1, R2, R3, R4: 10k; R-10
SW1: DIPSW-05; DIPSW-05VJ
SW2: JTP-1130
U$43: OPEN_SOURCE_HW; OPENHW

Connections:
!EXROM: J1.9 (!EXROM), JP5.2, SW1.2, SW1.2J (2)
!GAME: J1.8 (!GAME), JP4.2, SW1.1, SW1.1J (1)
!OE: IC1.22 (!G!VPP), J6.2, J6.4, J6.6
!RESET: J1.C (!RESET), SW2.1, SW2.2
!ROMH: D2.K, J1.B (!ROMH), J6.5
!ROML: D1.K, J1.11 (!ROML), J5.1, J6.3
+5V: C1.2, IC1.28 (VCC), J1.2 (+5V), J1.3 (+5V), JP9.2, JP11.2, JP14.2, R1.2, R2.2, R3.2, R4.2
A0: IC1.10 (A0), J1.Y (A0)
A1: IC1.9 (A1), J1.X (A1)
A2: IC1.8 (A2), J1.W (A2)
A3: IC1.7 (A3), J1.V (A3)
A4: IC1.6 (A4), J1.U (A4)
A5: IC1.5 (A5), J1.T (A5)
A6: IC1.4 (A6), J1.S (A6)
A7: IC1.3 (A7), J1.R (A7)
A8: IC1.25 (A8), J1.P (A8)
A9: IC1.24 (A9), J1.N (A9)
A10: IC1.21 (A10), J1.M (A10)
A11: IC1.23 (A11), J1.L (A11)
A12: IC1.2 (A12), J1.K (A12)
A13: IC1.26 (A13), J5.2
A13SW: J5.3, JP12.2, JP14.1, R4.1, SW1.5, SW1.5J (5)
A14: IC1.27 (A14), JP10.2, JP11.1, R3.1, SW1.4, SW1.4J (4)
A15: IC1.1 (A15), JP8.2, JP9.1, R2.1, SW1.3, SW1.3J (3)
D0: IC1.11 (D0), J1.21 (D0)
D1: IC1.12 (D1), J1.20 (D1)
D2: IC1.13 (D2), J1.19 (D2)
D3: IC1.15 (D3), J1.18 (D3)
D4: IC1.16 (D4), J1.17 (D4)
D5: IC1.17 (D5), J1.16 (D5)
D6: IC1.18 (D6), J1.15 (D6)
D7: IC1.19 (D7), J1.14 (D7)
GND: C1.1, IC1.14 (VSS), IC1.20 (!E), J1.1 (GND), J1.22 (GND), J1.A (GND), J1.Z (GND), JP4.1, JP5.1, JP8.1, JP10.1, JP12.1, SW1.6, SW1.7, SW1.8, SW1.9, SW1.10, SW2.3, SW2.4
RH&RL: D1.A, D2.A, J6.1, R1.1

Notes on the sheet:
LOW
HIGH
NEVER close both jumpers!!!
Versa64Cart
bwack
1.6
footprint includes solder bridges
121-1-01-01.6
Placement: This boards works with IC1 and C1 only. All other components are optional. Jumpers (J5 and J6) and the DIP-switch can be replaced with solder bridges. D1, D2 and R1 are required for 16k. (!OE! = RH&RL). R2..R4 are only required to set A13..A15 = HIGH. A13..A15 can be hardwired to HIGH wi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
16k
Switch
http://github.com/bwack

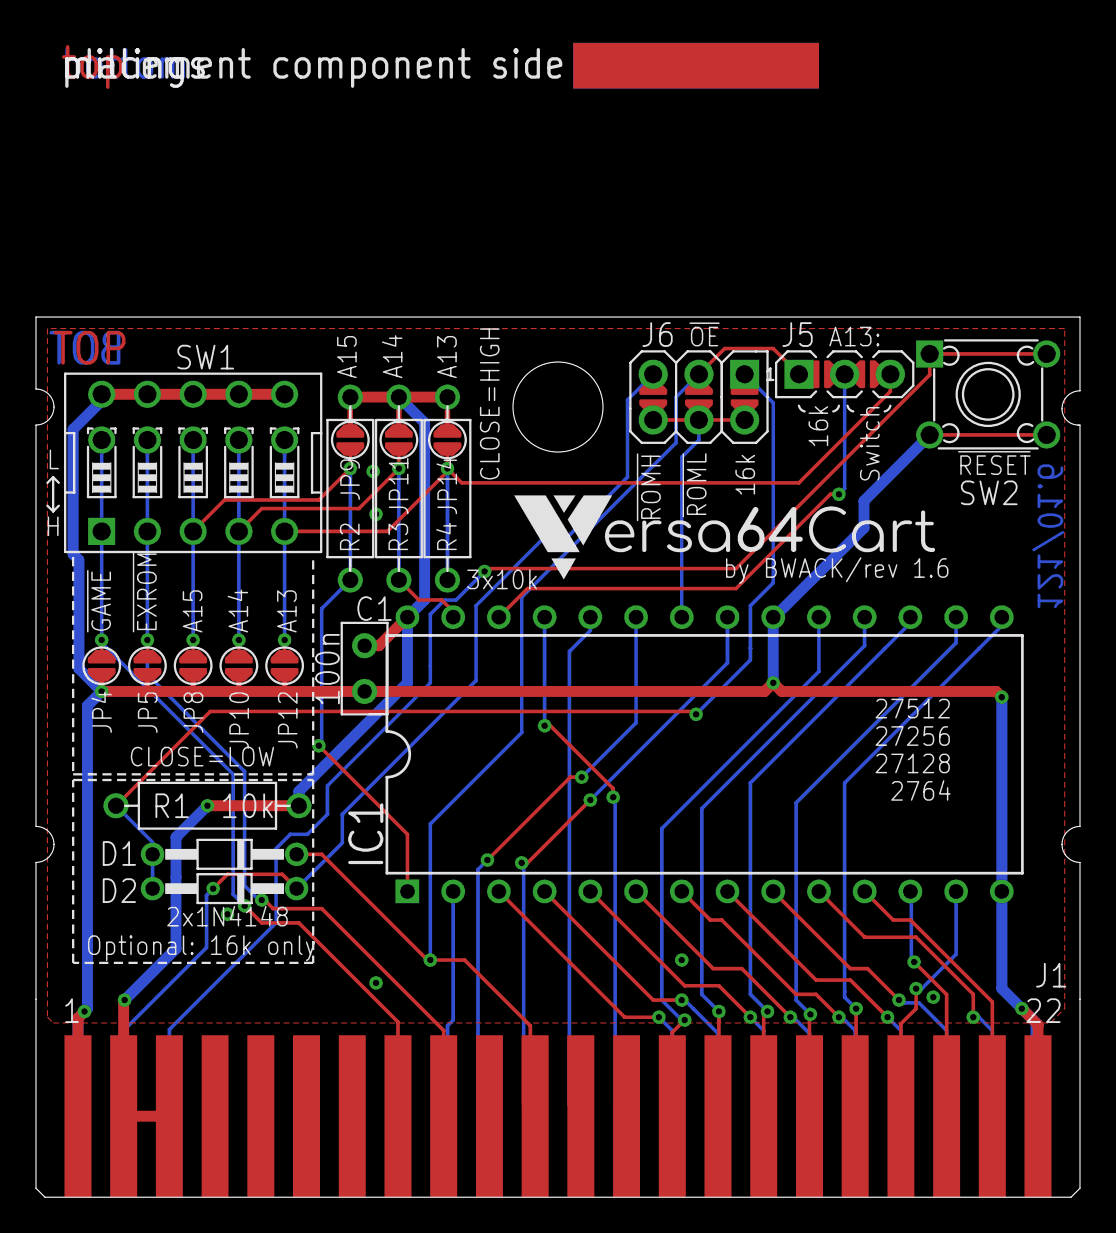
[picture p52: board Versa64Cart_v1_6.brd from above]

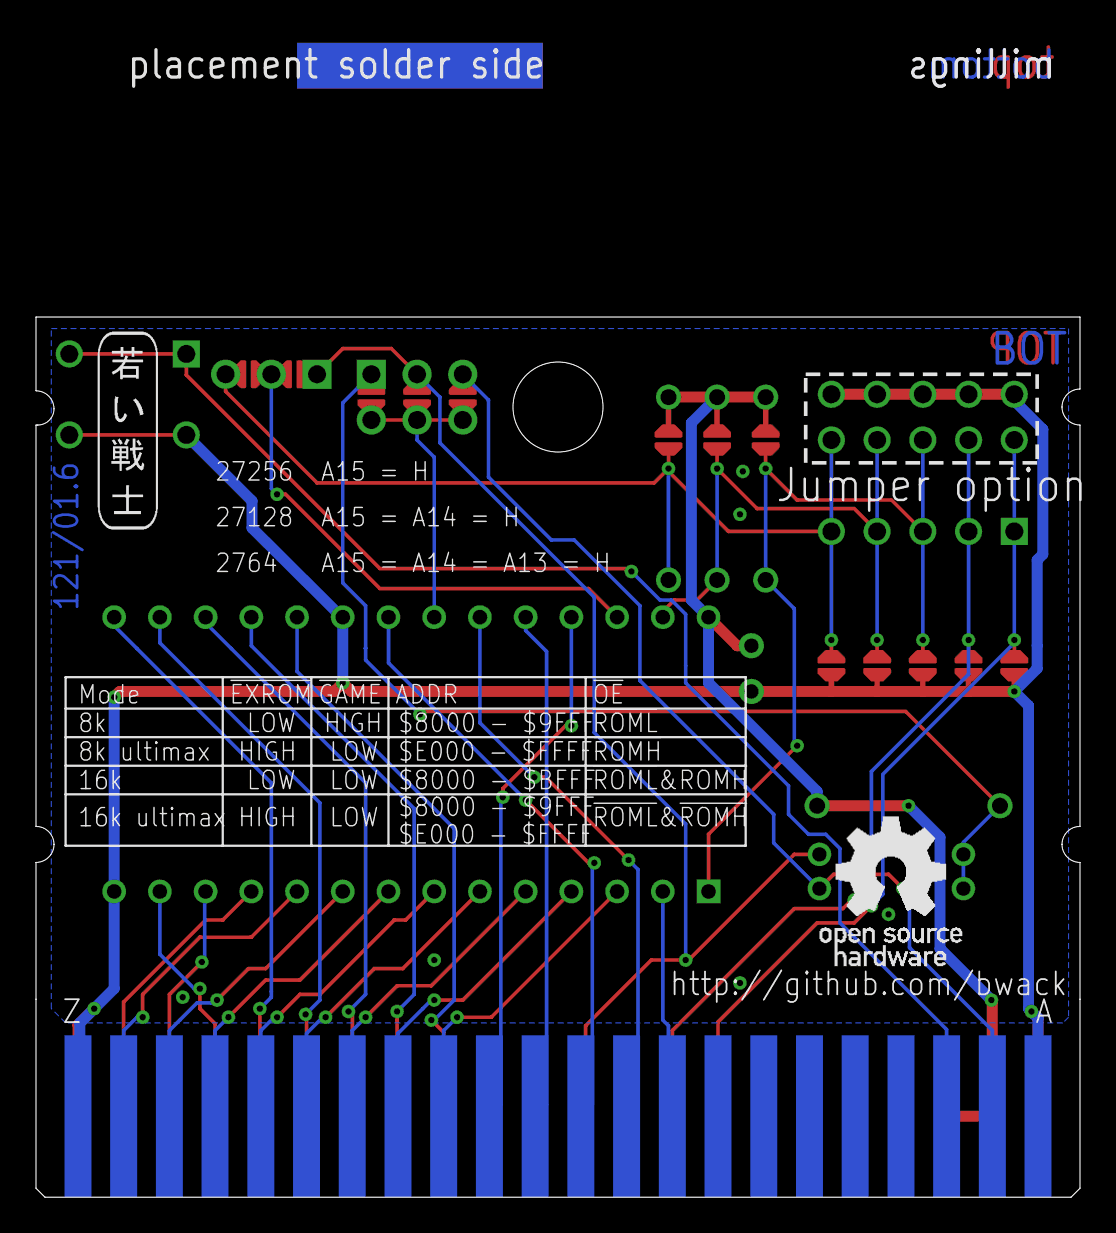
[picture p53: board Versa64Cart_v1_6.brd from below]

Board: 2 copper layers, 58.0 x 48.9 mm, 26 parts (2 on the bottom side), 34 nets.

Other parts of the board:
U$39: VERSA64CART
U$40: 2LAYER
U$41: PCB-TITLE/
U$42: SVEN_TAG

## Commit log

2017-06-27 first commit 1.0
    [Versa64Cart.kicad_pcb, Versa64Cart.sch]
2017-06-27 the pcb image file
2017-06-27 changed NPTH pad to be NP
    [Versa64Cart.kicad_pcb]
2017-06-29 VersaCart logo
    [Versa64Cart.kicad_pcb]
2017-07-22 Rev 1.1 - missing trace on ROML
    [Versa64Cart.kicad_pcb, Versa64Cart.sch]
2017-09-09 User Guide V.15 DIP switches
2017-09-27 gerbers
    tested with dirtypcbs. No extended attributes to support chinese fabs
    with CAM350 software.
2018-04-17 online bom #1
2018-05-06 User Guide V0.18: Board dimentions and enclosures.
    [Versa64Cart.kicad_pcb]
2019-04-18 Removed Gerbers catalogue with incorrect gerber file #5
    There is a gerbers.zip file though
2019-05-25 Include v1.2 from Sven
    [Versa64Cart.kicad_pcb, Versa64Cart.sch, Versa64Cart_BOM_v1_20.xlsx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]
2019-05-25 Released Rev. 1.2
    Rev. 1.2 adds some cosmetic changes to Rev 1.1. The jumpers have been moved to the outer edge of the board and a reset switch has been added.
    [Versa64Cart_BOM_v1_20.xlsx, Versa64Cart_v1_2.brd, Versa64Cart_v1_2.csv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]
2019-05-30 new v1.3 files and readme
    [Versa64Cart_BOM_v1_30.xlsx, Versa64Cart_v1_3.brd, Versa64Cart_v1_3.sch]
2019-05-30 changed to right angle pinheaders
    [Versa64Cart_BOM_v1_30.csv, Versa64Cart_BOM_v1_30.xlsx]
2019-05-30 right angle pinheaders in docs and bom
    [Versa64Cart_BOM_v1_30.csv, Versa64Cart_BOM_v1_30.xlsx]
2019-05-30 comma separate file
    github didn't like the colon separated file.
    [Versa64Cart_BOM_v1_30.csv]
2019-05-30 no idea
    [Versa64Cart_BOM_v1_30.csv]
2019-06-25 Rev 1.4
    [Versa64Cart_BOM_v1_40.csv, Versa64Cart_BOM_v1_40.xlsx, Versa64Cart_v1_4.brd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]
2020-05-07 combined footprint SW1, 5way DIP switch and 2x5 way 2.54mm pin header
    [Versa64Cart_BOM_v1_50.csv, Versa64Cart_BOM_v1_50.xlsx, Versa64Cart_v1_5.brd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]
2021-12-20 v1.6: added notches for the stumpy cart
    [Versa64Cart_BOM_v1_60.csv, Versa64Cart_BOM_v1_60.xlsx, Versa64Cart_BOM_v1_60_calc.xlsx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]
